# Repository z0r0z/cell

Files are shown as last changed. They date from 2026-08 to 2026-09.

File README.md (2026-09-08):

# CELL

A hardware wallet that needs a live pulse, or a drop of fresh blood, to authorise a transaction.

Airgapped signer for Bitcoin and Ethereum. Raspberry Pi, 3D-printed enclosure, $97.45 of hardware. Public domain.

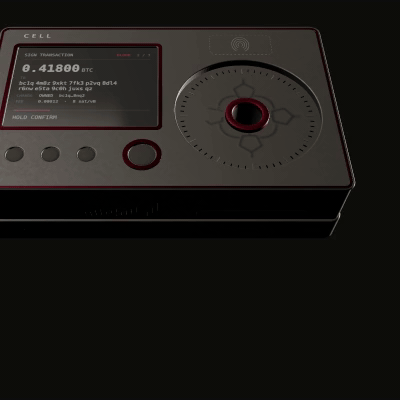
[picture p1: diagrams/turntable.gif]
CELL enclosure, 116 x 73 x 28 mm


<sup>The ring is the sensor port. A fingertip on it, or a cartridge under it. It is a bezel, not a control; nothing rotates.</sup>

## What it is

Transactions arrive as a QR code read by the camera and leave as a QR code on the display, in either of the two framings the airgap ecosystem uses. There is no wifi, no bluetooth and no USB data path.

`BUILD.md` §11 describes an optional USB-C data variant, for a device that signs often from one machine. It costs two properties §16 sets out, and it is not the default.

To authorise a signature you enter an eight-digit PIN and pass one of two liveness proofs.

| | Touch | Blood |
|---|---|---|
| Action | Fingertip on the ring | A drop in a disposable cartridge |
| Duration | 15 seconds | 10 minutes |
| Consumable | None | Cartridge and lancet |
| Proves | A living body is present | A living body bled, just now |

Touch is the everyday default. Blood is a mode you enter deliberately.

A button press costs nothing, so malware, an automated script and a deliberate human decision all produce an identical signal. An act your body rate-limits separates them: one drop of blood is one signature, and no budget compresses that.

How the two liveness tiers gate the signing key

## Status

**Firmware: complete.** 51 suites run on every commit, covering the signing stack against the vectors published in the BIPs, RFC 6979 and the EIPs, both liveness gates, the whole device loop, and the documented build sequence driven end to end. Bitcoin Core funds an address this firmware derives, and accepts and mines the spend it signs.

**Enclosure: complete.** Eleven parts are printed, all generated from the same constants the specification quotes, all mesh-checked and fit-checked before they are written.

**Sensors and secure element: written, not yet run on hardware.** The sensor head, the display, the buttons and the ATECC608B driver are code without a bench behind them. `VALIDATION.md` lists every claim in this repository and how it was checked, including the ones that are still open.

**Thresholds: calibrated on your build.** Sensing thresholds ship as physics-derived defaults. `calibrate.py` runs the spoof panel for both tiers against your own samples and writes the file the device loads. `BUILD.md` §13 is the procedure.

### Someone built one

**[Austin Griffith built a prototype and signed a transaction with fresh blood.](https://x.com/austingriffith/status/2097231722094191031)** Video, September 2026.

<a href="https://x.com/austingriffith/status/2097231722094191031">The blood gate running on the first prototype: laser warm-up, then gates G1 to G4</a>

<sup>A frame from the video: the blood gate mid-run on the prototype's display, showing this design's chemistry sequence in the builder's own wording: G1 return signal, G2 cellular scatter, G3 Soret, G4 shape.</sup>

The first build outside this repository: assembled hardware, a sample in the chamber, and a signature that happened because the blood gate passed. That build did not send back any measurements, so `VALIDATION.md` is unchanged. Everything it lists as needing hardware still needs it.

**There is a [bounty](https://poidh.xyz/mainnet/bounty/24) for building one and signing with it.** `BOUNTY.md` says what a claim looks like. A reader-only build counts.

## Try it without hardware

The gate logic, the signing stack and the whole device loop run on any machine.

```bash
pip install -r firmware/requirements.txt
python firmware/run_tests.py           # all 51 suites
```

Or one piece at a time:

```bash
cd firmware
python calibrate.py selftest --n 8     # blood tier, 6 gates, 18 sample classes
python touch_gate.py                   # touch tier, 7 gates
python test_app.py                     # the whole loop, driven with fakes
python test_wallet.py                  # end to end, then every footgun
```

Each spoof class fails at the physically correct gate, and the self-test fails if any gate stops being exercised by at least one class.

You can also spin the enclosure. It is a parametric three.js model, not a static render, and you can export OBJ or glTF straight from the viewer:

```bash
python3 -m http.server -d viewer 8000     # then open localhost:8000/instrument.html
```

## Building one

Read `SAFETY.md` first. It is short, and it covers blood handling.

The build splits into two kits, bought separately. **Order the reader kit first.** It answers the question that decides whether the rest is worth building, it has no security requirements because it signs nothing, and it costs a third of the total.

### 1. The reader kit: $63 of hardware plus $31 of consumables

A Pi, a spectrometer, a laser, a lensless camera, LEDs, a printed optical chamber, and the lancets, film and cartridges to run them. One weekend.

Build it, then run the spoof panel in `BUILD.md` §13. If the gate does not separate real blood from every fake on your hardware, you stop here and you have spent $94.

### 2. The wallet kit: a further $34.70

The signing half: display, buttons, QR webcam, ATECC608B secure element, USB-C power, the printed shells and the ring window. Then provision a seed and do the airgap hardening: radios disabled, antenna trace cut, read-only rootfs.

### The documents

| | |
|---|---|
| `BUILD.md` | The specification. Parts, wiring, optics, cartridge, firmware, calibration, threat model |
| `BOM.csv` | Every part, with a `Kit` column saying which kit it belongs to and what to insist on |
| `PRINTING.md` | The print runbook: plate order, what to check at each stage, the post-processing that is not optional |
| `SAFETY.md` | Blood handling. Read it before the first build |

Eleven parts are printed, all from `python3 tools/gen_printables.py`, all checked before they are written. `models/print/MANIFEST.md` is generated in the same pass and carries every dimension, quantity and print setting.

**Running costs.** A touch signature costs nothing. A blood signature spends a lancet, an alcohol pad, a PET window and a printed cartridge: about twenty cents, restocked from any pharmacy. Nothing in the device is consumed by either, and nothing on the bill of materials has a shelf life.

## How the gates work

### Blood: six gates, all must pass

**Chemistry.** Haemoglobin absorbs strongly at 415 nm, the Soret band of the iron-bearing porphyrin ring at the centre of the molecule. The absorption is roughly an order of magnitude stronger than anything else in the visible spectrum, and no common red substance produces it. Ketchup, food dye, beet juice and theatrical blood all fail immediately. Three further gates confirm that the sample returns light at all, that it scatters in the near infrared the way a suspension of cells does rather than a dye solution, and that the full eight-channel spectrum matches oxygenated whole blood.

**Motion.** Colour cannot tell fresh blood from a stored sample, so the device measures movement instead. Under laser illumination a liquid suspension of red cells produces a speckle pattern that boils as the cells move; as fibrin forms it locks them in place and the pattern freezes. A camera watches for ten minutes and measures the frame-to-frame correlation.

Fresh blood is the only sample that starts decorrelated and becomes correlated. Anticoagulated blood never arrests. Clotted blood, corn syrup and gels never moved in the first place. Dye produces no speckle at all.

This works because of an asymmetry in how blood can be kept: blood you can store has been anticoagulated and will not clot in the chamber, and blood that was not anticoagulated has already clotted and cannot be poured into a well. `BUILD.md` §16 gives the one exception and how far it reaches.

Implementation in `firmware/blood_gate.py`, with every threshold in a single dataclass.

### Touch: seven gates, all must pass

Photoplethysmography through the same ring bore the cartridge sits under. Arterial blood volume in the fingertip changes with each heartbeat, so the light coming back carries a small pulsatile signal on a large steady one. The white LED gives a red channel and the 940 nm LED gives infrared, both sampled at 50 Hz by the spectrometer that is already there. No extra parts.

The gates check that the capture rate was high enough to analyse, that a finger is in contact, that the signal is pulsatile at a physiological depth, that the rate falls between 40 and 180 bpm, that the cardiac band dominates, that beat-to-beat variability is present, and that the red-to-infrared ratio matches haemoglobin.

The last two carry most of the anti-spoof weight. A silicone finger with dye pumped through it can produce a convincing pulse, but dye does not share haemoglobin's absorption ratio across the two wavelengths; and respiratory sinus arrhythmia puts a resting adult's beat-to-beat variability in the tens of milliseconds, where a mechanical pulsator produces single digits.

Implementation in `firmware/touch_gate.py`.

### Tier policy

You may always escalate to a higher tier than policy requires. You may never proceed at a lower one.

Policy sets a floor, and changing that floor is blood-locked in both directions. Loosening must cost blood, or a thief lowers the bar and uses their own finger. Tightening must cost blood too, or someone locks you out by raising your floor while you are travelling without cartridges.

Escalation applies to one operation and does not persist. Five operations are blood-locked at provisioning and cannot be unlocked: policy changes, key export, device wipe, reprovisioning, and changes to the recipient allowlist.

Implementation in `firmware/policy.py`.

## What else it does

### Attestation

A signature says nothing about what gated the key, so the tier is claimed separately. Each device holds an attestation key generated at provisioning and signs a 238-byte record binding the tier to a specific sighash, a monotonic counter, a firmware hash, the calibration in force and the gate measurements behind the claim.

Co-signers register each other's attestation keys once, alongside the firmware and calibration hashes they accept. Verifying that every member of a quorum signed at blood tier is then a mechanical check, and a missing attestation counts as a failure and never an abstention.

The record travels beside the PSBT in a BIP-174 proprietary field and is stripped before broadcast, so it does not appear on chain. Publishing it says "this address is a CELL device, and this spend was authorised with blood", which is a leak for a treasury, and the whole point for an allowlist, so it is an option and not a default.

A contract can check the record itself. `contracts/src/CellAttestation.sol` verifies the signature; `CellRegistry.sol` holds what the record cannot carry: whose key it is, the highest counter seen from it, and which firmware and calibration you accept. The BIP-340 Schnorr signature has no EVM precompile, so it is rearranged into one `ecrecover` plus a `modexp` to lift the point: about 41k gas to verify, 81k for a full `redeem`. The digest commits to the chain, the contract and the claimant, so a record cannot be replayed on a fork, against another deployment, or by someone else.

What that buys is a signature nobody can farm. A script produces a million; a body produces about two a day, each costing a lancet and ten minutes. Implementation in `firmware/attest.py`.

### One of these devices bled, and you cannot tell which

For an allowlist, a mint or a quorum vote, the claim worth publishing is "a human bled", not "device 7 bled".

`firmware/ring.py` signs as one member of a registered set, using LSAG over the same secp256k1 everything else here signs on. A key image `I = d · H(event ‖ P)` links two claims from one device in one event, so nobody votes twice, and leaves claims in different events unlinkable, so nobody accumulates a voting history.

The firmware and calibration hashes are deliberately left out. They are what makes the ordinary record auditable, and they are exactly what would narrow a ring of forty to a ring of three. The ring replaces them: a verifier admits a set of keys and checked their firmware when it registered them.

A ring of n costs about 2n scalar multiplications on each side, which is slow in pure Python and does not matter, because the ring computes while the sample clots. Use it off chain or in a coordinator-maintained allowlist; it is too expensive to verify on chain.

### Proof of life

Dead-man switches key off signing activity, which answers the wrong question. A stolen key resets the clock, and an owner who simply does not spend for a year looks dead. The touch gate measures a body, so CELL can tell them apart.

A beacon is the attestation with no transaction under it: fifteen seconds, no consumable, nothing signed with the seed. `CellRegistry.heartbeat` records when a living human was last proven present, and an inheritance path, a recovery quorum or a multisig can read it.

**The date on the screen is the security control.** The device has no clock. The period comes from the companion and is displayed as a date range, so the owner is the clock, and `heartbeat` accepts a beacon only while its period is current. A harvested record cannot be spent early or late.

`CellDormancy.sol` reads it in two phases on purpose: a claim releases nothing, it opens a challenge window, and one beacon during that window cancels it. Six months in a drawer is the ordinary case, and fifteen seconds of a fingertip undoes it.

## The signing stack

Both chains sign on secp256k1, so one key and one signing core serve both. The wallet half is implemented here rather than delegated because the gate reaches inside it: the tier decision, the confirmation screen and the attestation all depend on what the transaction actually says. Pure Python, with `cryptography` as the only dependency, used for AES-GCM.

| | |
|---|---|
| `secp256k1.py` | ECDSA with RFC 6979 nonces, low-S, low-R grinding, BIP-340 Schnorr, BIP-341 tweaks |
| `bip39.py` / `bip32.py` | Mnemonic and HD derivation, with the wordlist's SHA-256 checked on load |
| `psbt.py` / `tx.py` | BIP-174 and BIP-370 parsing, and all three sighash algorithms |
| `addresses.py` | bech32 and bech32m, every script type, EIP-55 |
| `eth.py` | RLP and EIP-1559, built on the device from fields it displays |
| `names.py` | WNS, GNS and ENS names the owner registered — routing, per-chain addresses, and the reverse the screen draws |
| `eip712.py` | EIP-712 typed data for smart accounts, the timelock the screen states, and the EIP-7702 delegation |
| `beacon.py` | The beacon digest, and the period the owner reads |
| `qr.py` | The airgap: `pNofM` frames, and reassembly that refuses substitution |
| `ur.py` | UR 2.0 with fountain codes, and EIP-4527, against the published vectors |
| `link.py` | The USB-C data variant's wire. Opt-in, and it costs two properties |
| `app.py` | The loop: scan, show, confirm, PIN, gate, sign, emit |

The device signs a closed set of operations it can render as readable text, and refuses everything else, including arbitrary EVM calldata. Two consequences look like missing features and are not: a PSBT paying several recipients is refused, because the owner can check one destination character by character and cannot check a total; and every Ethereum field (chain id, nonce, and `gas_limit × max_fee_per_gas`) is on the confirmation screen, with unrecognised chain ids refused.

**Handing over your accounts.** The device prints its extended public keys on screen, and will also emit them as one `ur:crypto-account` so a coordinator scans all four Bitcoin script types instead of somebody retyping an xpub. It signs nothing and needs no PIN. It sits behind a warning, because an account xpub reveals every address that wallet will ever use, forever, to whoever reads it.

**Both QR framings, and a browser.** Transfers arrive and leave as either `pNofM` frames (the Specter convention) or UR 2.0 (what Sparrow and the Keystone-compatible coordinators reach for), and the device replies in whichever it was asked in. UR is rateless, so a frame the camera never manages to read is recovered from a mixture of others instead of stalling the transfer — which matters on a $8 webcam. UR also carries EIP-4527, so MetaMask's and Rabby's QR-account flows work: the request arrives as `ur:eth-sign-request` and the answer goes back as `ur:eth-signature`. There the transaction arrives encoded rather than as fields, so the device rebuilds it, re-encodes it, and refuses if the two differ by a byte.

One operation carries calldata, and the way it does is the point. An **ERC-20 transfer** is signed for tokens the owner registered, and the device is never handed those 68 bytes — it is handed a token, a recipient and an amount, and it writes `transfer(address,uint256)` itself. Both addresses go on the screen in full, because an ERC-20 transfer is addressed to the *contract* and carries the *recipient* in its calldata, and one address on a screen is the wrong one. `decimals` comes from the registration and never from the request: it is where the decimal point goes, and a request that could supply it could render a millionth of a token as one whole token. `approve` is not implemented, and neither is any other selector.

**Names, on both chains.** A payee's `.wei`, `.gwei` or `.eth` name can sit above their address on the confirmation screen — WNS first, then GNS, then ENS, since this project co-developed WNS. The device never resolves one: it has no network, and a name that arrived with a transaction would be a label an attacker picked for an address you are about to approve. So names are registered like chains, tokens and quorums are — `tools/ethnames.py` resolves and forward-verifies on the host, you check the address against the name's own page, and `provision.py name` records the pair. The address stays on the screen in full, and it is still what the signature commits to.

All three systems are rooted on Ethereum mainnet and read through the same SLIP-44 coin types, so one name covers more than one chain: its default address is drawn on every EVM chain, a per-chain address (ENSIP-11) overrides it on the chain that published one, and a Bitcoin address (coin type 0) makes the same name a payee on a Bitcoin spend. Where a name publishes an override, the device refuses to draw that name over the default address on that chain — the same twenty bytes on two chains can be two different owners.

One exception earns its place. A smart account's timelock is not in the signed message, so the same signature means "send now" or "send in two days" depending on chain state the device cannot read — the delay is registered out of band and stated on the screen, along with whether every owner signing together can skip it. And `cancelQueued` is the one self-call the device will sign, at touch tier, because a device that can start a delay but not stop one has given its owner a countdown and no button.

Multisig and smart accounts must be registered before they can be signed, and this device has to be a member of what it registers — a Bitcoin quorum it holds no key in, or an EVM account it is not an owner of, is refused rather than signed for and rejected afterwards. Without the co-signers on file, "is this output mine?" collapses to "does it contain a key of mine?", and a hostile coordinator can build a script holding one key of yours and the rest theirs; it hashes correctly, the wallet calls it change, and the money moves somewhere you cannot spend alone. With the quorum registered the device rebuilds the exact script your co-signers produce and compares it byte for byte. `tools/provision.py multisig` does the registering.

## Keys and backup

The device holds a standard BIP39 seed, encrypted at rest and unwrapped only after the gate passes. The unwrapping key comes from your PIN and the secure element's own secret, so the encrypted seed is inert on any other machine and recoverable on this one. Back it up on paper or steel as with any hardware wallet. If the device fails, restore to a Ledger, a Trezor or a replacement build.

The seed itself is drawn from three sources XORed together: the kernel CSPRNG, the ATECC608B's hardware RNG, and the difference between disjoint pairs of speckle frames from the chamber, where the static field cancels and photon shot noise does not. `provision.py` prints the min-entropy it measured on the sample it actually drew. A chamber that is dark, blocked or absent contributes zeros and says so, and zeros XOR into nothing.

## Limits

Worth reading before you trust it with anything. `BUILD.md` §16 carries the full threat model.

**The PIN is what proves who.** The gate only proves that someone alive is present. The PIN is eight digits. PIN-v2 derives each candidate through a random secret in the secure element, consuming a chip-counter use before comparison. A public PIN hash no longer suffices for raw verification commands. Firmware wipes after ten wrong entries; the separate hardware bound is the remaining Counter0 capacity, at most 2,097,151 uses shared with wrapping operations. The new provisioning policy rejects the old configuration. Physical validation remains required before release; see `VALIDATION.md`.

**The attestation rests on firmware and the tamper seal.** It states that a device holding this key ran the gate; it does not prove the gate passed. This is the same assumption as a TPM quote or a Secure Enclave receipt. Someone who opens the case and extracts the key can sign records without bleeding, so treat it as raising the cost of faking a human. Co-signers register firmware hashes alongside keys, and `verify()` refuses builds it does not recognise.

**An opened case derives a different key.** A ground-glass diffuser is epoxied into the optical chamber, and the laser and camera that watch blood clot read its speckle at every unlock. That reading is a term in the key that unwraps the seed, so a case that has been opened does not fail a check. It derives a different key, and the seed stays shut. Thermal drift is registered out against two reference patches and reported separately from tampering. Enrolment is optional. It costs one habit: because the laser is interlocked to the cartridge switch in hardware, an enrolled device needs the bay closed at every unlock, so leave a spent cartridge in the slot. `firmware/optical_puf.py`.

**Coercion needs a second PIN.** No measurement tells willing blood from coerced blood. Set a duress PIN and the device carries two wrapped seeds and two wallets; the duress PIN unlocks, signs and behaves identically, and opens the other one. Both seeds are written whether or not you configure one, so the card never says which kind of device this is. It protects what you sign, not what your device shows: the receive and identity screens are watch-only and still display the primary wallet. Fund the decoy plausibly. `firmware/duress.py`.

**A prepared laboratory attack is not in scope.** A well-made artificial finger containing a genuine haemoglobin-like absorber, driven by a pump replaying recorded variability, would pass the touch tier. So would a citrated sample recalcified immediately before loading, at the blood tier. Both need your blood, your device and your PIN together.

**Anyone taking anticoagulants cannot use the blood tier.** Their blood will not clot, and the gate will reject every sample.

## Repository layout

| Path | Contents |
|---|---|
| `BUILD.md` | Hardware specification: parts, wiring, optics, cartridge, firmware, calibration |
| `PRINTING.md` | Print runbook: order, checks, post-processing |
| `BOM.csv` | Bill of materials, by kit, with sourcing notes |
| `SAFETY.md` | Blood-contact handling. Read it first |
| `VALIDATION.md` | Verification status: what is tested, by what method |
| `CONTRIBUTING.md` | What this project actually needs |
| `firmware/blood_gate.py` | Blood tier, six gates |
| `firmware/touch_gate.py` | Touch tier, seven gates |
| `firmware/calibrate.py` | Spoof-panel harness for both tiers, and the synthetic self-test |
| `firmware/hardware.py` | Sensor drivers, and a bring-up checklist |
| `firmware/policy.py` | Tier selection and escalation rules |
| `firmware/signer.py` | The unlock chain: policy, confirm, PIN, gate, sign, attest |
| `firmware/attest.py` | Tier attestation and quorum verification |
| `firmware/ring.py` | The attestation with the device's name taken off it |
| `firmware/beacon.py` | Proof of life: the attestation with no transaction under it |
| `firmware/duress.py` | The second PIN |
| `firmware/optical_puf.py` | The chamber as a tamper boundary |
| `firmware/chamber_trng.py` | Seed entropy from the chamber, and its health tests |
| `firmware/se_atecc.py` | ATECC608B driver: CheckMac PIN, duress slots |
| `firmware/wallet.py` | Provisioning, and the two signing entry points |
| `firmware/app.py` | The loop, as a person uses it |
| `firmware/ur.py` | UR 2.0 framing, against the published vectors |
| `firmware/link.py` | The optional USB-C wire, and what choosing it costs |
| `firmware/names.py` | WNS, GNS and ENS names the owner registered, and what the screen may draw |
| `firmware/names.py` | WNS, GNS and ENS names the owner registered, and what the screen may draw |
| `firmware/run_tests.py` | Every self-test in one run. What CI runs |
| `tools/provision.py` | Choose a seed, wrap it, record the watch-only accounts |
| `tools/companion.py` | The host end of the USB-C variant's wire |
| `tools/ethnames.py` | Resolves WNS, GNS and ENS on the machine that has a network |
| `tools/ethnames.py` | Resolves WNS, GNS and ENS on the machine that has a network |
| `tools/gen_printables.py` | Generates every printable part, checks it, writes the manifest |
| `tools/gen_enclosure.py` | The inside of the two shells, and the fit checks |
| `tools/bench.py` | The checks only the built device can answer |
| `tools/regtest_e2e.py` | Sign with the firmware, make Bitcoin Core accept it |
| `tools/evm_e2e.py` | Deploy the contracts, make a node accept a beacon the firmware signed |
| `contracts/` | On-chain verification of the attestation record, and the registry |
| `models/print/` | The eleven printable STLs and their generated manifest |
| `viewer/` | Parametric three.js model of the enclosure |
| `diagrams/` | Explainer, build sheet, dimensioned drawings |

Build sheet: parts, optical head, cartridge

## Licence

CC0 1.0. See `LICENSE`.

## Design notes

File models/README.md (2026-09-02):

# Enclosure model

`instrument.obj`: 104 named objects with materials, 116.2 × 73.2 × 28.3 mm.
~54 MB, tracked with Git LFS (see `.gitattributes`).

The object and vertex counts are printed in the corner of
`diagrams/mechanical.svg`, which is generated from this file. Trust that copy
if this line ever drifts again.

## The chain is one-way

```
viewer/model.js  ──export──▶  instrument.obj  ──generate──▶  diagrams/mechanical.svg
```

`viewer/model.js` is the **parametric source**. It builds the geometry in
three.js. `instrument.obj` is an export from that viewer. The drawing is
generated from the export by `tools/gen_mechanical.py`, which reads every
dimension out of the mesh at generation time, so the drawing cannot drift from
the model. CI fails if it does.

After any model change, re-export and then:

```bash
python tools/gen_mechanical.py
```

**Do not hand-edit the OBJ.** It is 54 MB of triangles, and nothing downstream
of a hand edit can be reconciled with a parametric change.

`instrument.mtl` is written by `tools/export_model.py` in the same pass as the
OBJ, from the viewer's own materials, so the two stay in step. Material names
also ride on the objects themselves (`shell`, `oxblood`, `trim_oxblood`,
`glass`, `pad`, `etch_floor`, `steel`, `cavity`, `cavity_bore`, `screen`,
`silkscreen`, `silkscreen_mark`), so the separation survives if you drop the
MTL and assign your own. Twelve, not eleven: `cavity_bore` is the inward-facing
material on `port_sleeve`, and it is the one the OBJ cannot carry faithfully,
because a back-faced material is a thing the format has no way to say.

The two accent materials, `oxblood` and `trim_oxblood`, are the only ones a
builder is meant to choose. `model.js`'s `FINISHES` table names five, and
`PRINTING.md` section 2b carries the same set as filament colours. Oxblood is
the default, and the export is byte-identical in every finish that does not
change it: the OBJ carries no colour at all, and the MTL is written from
whichever finish is loaded, which for every committed artefact is the default.
Nothing here needs regenerating when a finish is added.

## Coordinate convention: centre-origin

| Axis | Range | Meaning |
|---|---|---|
| X | −58.10 … +58.10 | length, right positive |
| Y | 0 … 28.32 | height from the base |
| Z | −36.60 … +36.60 | depth, **+Z toward the front face** |

Some tooling works left-edge-origin (0 … 116.2). Crossing the two frames is a
silent 58 mm error that will not look wrong on screen.

---

## The printed parts

`models/print/` holds the parts that are *not* enclosure: the cartridge, the
pre-flight REFERENCE and NULL bodies, the aperture tube, the optical head, the
slot baffle, the display bezel, the rear bay blank, the window jig, and both
enclosure shells.
`python3 tools/gen_printables.py` builds all eleven, validates each one, and
regenerates `models/print/MANIFEST.md` from the same constants. The manifest
cannot describe a part the STLs no longer are.

The shells are the one place the one-way chain above does not tell the whole
story. `model.js` owns the outside and is an appearance model: its shells are
solid, and its openings are dark boxes with no volume removed. The inside
(wall, part line, bosses, rails, optical chamber) comes from
`tools/gen_enclosure.py`. Two parametric sources is exactly the drift this file
warns about, so the seam is checked on every run: the assembled shells must
match the documented envelope, and the assembly checks must pass. See
`models/print/MANIFEST.md`.

## Regenerating

`tools/export_model.py` drives headless Chrome against the real viewer, so the
mesh comes out of the same three.js code path a person gets when they open the
page. No reimplementation to drift.

```bash
python tools/export_model.py        # model.js  -> instrument.obj + .mtl
python tools/gen_mechanical.py      # instrument.obj -> diagrams/mechanical.svg
```

Run both after any model change, in the same commit. CI checks both links: the
`model-export` job re-exports and diffs the OBJ, and `drawings` regenerates the
SVG from it.

Three more things are rendered from this same model and are stale the moment it
changes. None is checked by CI, because each needs a browser:

```bash
python3 tools/render_turntable.py       # -> diagrams/turntable.gif + .mp4
python3 tools/render_social_card.py     # -> diagrams/social-card.png
python3 tools/build_single_file_viewer.py   # -> viewer/instrument-standalone.html
```

The last one is what `cell.wei.is` serves, so it is the one that matters
outside the repository. Building it is not deploying it. CI's `viewer` job
checks the bundle in the tree carries this tree's viewer. Nothing can check
what the host is serving.

## Geometry check

The cartridge enters the front slot and must land under the optical head, so
the slot and the ring share a centreline:

| | X centre | Z |
|---|---|---|
| `front_slot` | +28.50 (spans +11.5 … +45.5) | +36.05 |
| `ring` / read spot | +28.50 | +5.00 |
| Front face | — | +36.60 |

Cartridge travel front face to read spot is **31.6 mm**, which sets the 51 mm
cartridge length in `BUILD.md` §8. The WELL has to reach the read spot and sits
10.5 mm back from the tip, so 42.1 mm goes in and 8.9 mm stands proud to grip.
If you move the dish, re-derive the cartridge length from this number.

## The sensor port

The dish floor is an annulus. `PORT_D` 9.8 opens through it to the optical
chamber, and the Ø10 × 0.5 ring window that `BOM.csv` buys sits in a
Ø10.2 × 0.6 rebate under the ring's inner lip, flush with the floor. Four
objects carry it: `recess_floor_etch` (the annulus), `ring_window`,
`port_sleeve` and `port_floor`. The numbers come from `tools/gen_enclosure.py`,
which owns the inside. This file's job is only to look like it.

## The deck's top face is 28.32

Not 28.0. `shell_skin` extrudes 27.5 → 28.0 with a 0.4 bevel, which is thicker
than half the slab, so `ExtrudeGeometry` clamps the depth and the chamfer adds
its full thickness on top. The deck finishes at 28.32. That is where the
envelope's 28.32 comes from, and what `gen_enclosure.py` pins `ENV_Z` to.

Anything that sits ON the deck has to be placed against 28.32. Four things were
placed against 28.0 instead and spent a long time invisible inside the shell:
the pad marking, the display bezel, the CONFIRM collar and the edge break. They
are coplanar with the deck now, and depth-offset instead of floated, because
lifting them even a hundredth would raise the envelope that
`gen_enclosure.check_viewer_envelope()` compares against the printed shells.

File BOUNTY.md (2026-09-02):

# Bounty: build one and sign with it

Everything you need to build one is in this repo.

**Build the device. Sign with a pulse. Sign with fresh blood. Post pictures.**

**[Bounty 24 on poidh](https://poidh.xyz/mainnet/bounty/24)**, on mainnet. It
is topped up over time, so the listing carries the amount and this file
deliberately does not.

## Cost

**~$97 in hardware, ~$31 in consumables.** `BOM.csv` lists every part with
sourcing. The bounty is worth more than the build.

## Build it

`BUILD.md` §15, milestones 1 to 14. Wiring in `diagrams/wiring.svg`, optical
head in `diagrams/build-sheet.svg`, printables in `models/print/`.

Milestone 14 is the restore drill: wipe the device, restore from your paper
backup, spend again. Do it before you claim.

## Before you start

Read `SAFETY.md`. One device per person, one lancet per use, sharps container.

The gate wants a fresh sample from anybody. Anyone on anticoagulants will be
rejected every time, since clotting is the thing being measured.

Two things to know:

- `firmware/hardware.py` has never touched hardware. Treat it as a wiring
  diagram in Python. It has a bring-up checklist.
- Locking the chip is permanent. `lock-data` refuses a chip that fails its own
  policy or does not enforce it, so the tool covers you. Run
  `atecc_config.py verify --behaviour` first and read it anyway.

## Claim it

Submit the claim on [the bounty page](https://poidh.xyz/mainnet/bounty/24),
with pictures or video of:

1. The assembled device, running
2. A signature authorised by a pulse
3. A signature authorised by a fresh blood sample
4. The transaction on chain. Testnet is fine

And say what you had to change to make it work, if anything.

## Partial claims count

**Reader only.** Milestone 7, a spoof panel run, `thresholds.json` and
`captures/` posted. That is the half carrying the novel physics, and the
cheaper one to reach at $62. Open an issue here with the numbers as well as
claiming on poidh: `CONTRIBUTING.md` says what makes a panel run useful to
everybody else, and the captures are `.npz` so they can be replayed safely.

**A failure is a claim too.** If dye passes a gate, or real blood fails on your
optics, post it. That answer is worth paying for.

`VALIDATION.md` tracks what has been verified and what is waiting on a first
build. You're the one who moves rows from the second list to the first.

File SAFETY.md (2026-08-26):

# Safety

CELL is a blood-contact instrument. The handling rules are the ones any
phlebotomy or home-glucose workflow uses. Followed, the risk is that of a
finger-prick glucose test, a routine procedure performed billions of times a
year.

Read this before your first build.

---

## Who the blood tier is for

The blood tier works by measuring clotting. If your blood does not clot on a
normal schedule the gate rejects you every time. That is an incompatibility,
not a safety warning.

**Use the touch tier if you:**

- take anticoagulants: warfarin, DOACs (apixaban, rivaroxaban), clopidogrel,
  or daily aspirin
- have a bleeding or clotting disorder
- are immunocompromised
- have poor peripheral circulation

The touch tier is the everyday default, needs no consumable, and defeats the
same remote-attacker class. Nothing about the device is closed to you.

## The five rules

1. **One device, one person.** Blood-contact equipment is personal, the way a
   lancing device or a toothbrush is. Do not share it and do not lend it.

2. **Commercial sterile single-use lancets.** Contact-activated, 28G / 1.8 mm,
   about $0.06 each from any pharmacy. One lancet, one use. They retract and
   lock, which is what you are paying for.

3. **One cartridge, one use, then the sharps container.** A 1 L container is on
   the BOM. Used cartridges and lancets go in it, never in household waste.

4. **Alcohol before, pressure and a plaster after.** Rotate fingers. Use the
   sides of the pad: less nerve density, and not the surface you type with.

5. **Two blood authorisations a day is the design point.** The blood tier is
   for cold storage and infrequent high-value operations. The touch tier
   handles everything else. Wanting more means your policy floor is set too
   aggressively, which is a settings change.

## During calibration

Calibration wants 30+ genuine captures, and 100 for a tighter bound. Spread
them out:

- Draw once, venously, to supply the negative classes (aged, EDTA, haemolysed,
  deoxygenated). Do not lance repeatedly for them
- Spread genuine capillary trials across several weeks
- Rotate fingers and sites

It is also better data. Samples taken across weeks, hydration states and
temperatures give thresholds that hold up in real use.

## Standard aftercare

Puncture sites heal in a day or two. See a doctor for spreading redness,
warmth, swelling, pus, red streaking up the finger, fever, or bleeding that
will not stop after 10 minutes of direct pressure. That is the guidance that
comes with any lancing device.

## Laser

650 nm diode at ≤5 mW. Class 3R, the same class as a lecture pointer. It is
interlocked to the cartridge switch and sealed inside a light-tight chamber in
normal operation.

The chamber is open during bring-up. Do not stare into the beam. Do not point
it at anyone. Take off reflective jewellery while you work.

## Scope

CELL is a security device. It is not a medical one. It measures clotting to
prove a sample is fresh, and it reports gate results. It says nothing about
your health. A rejection means the sample or the optics, and the usual cause
is a fingerprint on the window.

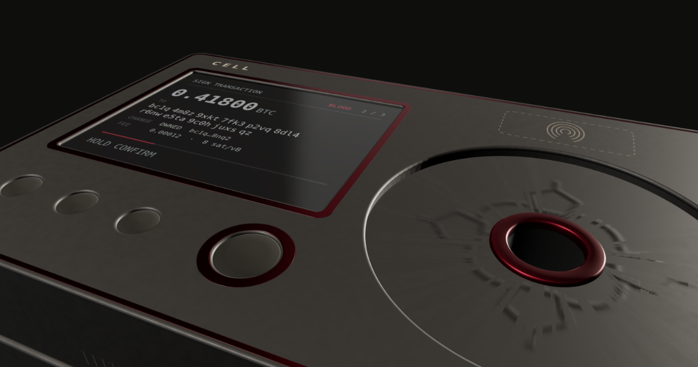
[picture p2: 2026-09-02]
diagrams/social-card.png

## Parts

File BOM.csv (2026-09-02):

Kit | Category | Item | Part / Spec | Qty | Unit USD | Ext USD | Notes
Reader | Compute | Single board computer | Raspberry Pi Zero 2 W | 1 | 15.00 | 15.00 | Disable radios in config.txt AND cut the antenna feed trace. Firmware-only disabling is reversible.
Wallet | Security | Gate chip | ATECC608B breakout (Adafruit 4314 / SparkFun) | 1 | 6.00 | 6.00 | PIN attempt counter + AES key storage + KDF. Counter increments before verify.
Reader | Sensing | Spectrometer | AMS AS7341 breakout (Adafruit 4698) | 1 | 16.00 | 16.00 | 8 colour channels 415-680nm + Clear + NIR. Onboard LDR pin drives LED #1 directly.
Wallet | I/O | Display | ST7789 1.3in 240x240 SPI | 1 | 8.00 | 8.00 | SPI0 CE0
Reader | I/O | Camera (speckle) | Pi Camera + mini-CSI cable | 1 | 10.00 | 10.00 | LENS REMOVED. Fixed exposure/gain/AWB - auto adjustment destroys the correlation measurement.
Wallet | I/O | Buttons | 12mm tactile switch + cap | 4 | 0.75 | 3.00 | CONFIRM gets its own pin (GPIO26) + RC debounce 10k/100nF
Reader | Optics | White LED | 5mm white 5000K | 2 | 0.40 | 0.80 | Mounted at 45 deg opposed
Reader | Optics | IR LED | 940nm 5mm | 1 | 0.50 | 0.50 | Co-sited with LED #1
Reader | Sensing | Laser | 650nm diode module, <=5mW | 1 | 2.00 | 2.00 | Liveness gate. Coherent source is MANDATORY - an LED has microns of coherence length and produces no speckle. Interlock to the cartridge switch.
Reader | Optics | MOSFET | 2N7002 SOT-23 | 3 | 0.15 | 0.45 | Low-side gates for white LED #2 (GPIO12, 68R to +5V), 940nm IR (GPIO23, 47R to +3V3) and the laser (GPIO6). Three loads, three parts.
Reader | Optics | Passives | 68R / 47R / 10k / 5.1k / 2.2k / 100nF assortment | 1 | 1.00 | 1.00 | ONE 2.2k pull-up pair on the whole I2C bus - remove from the other breakouts. The two 5.1k are the USB-C CC pulldowns - see the USB-C row.
Wallet | Power | USB-C power input | USB-C breakout, power only | 1 | 2.00 | 2.00 | NO BATTERY. A LiPo left at partial charge for a year swells or worse. Desolder D+/D- or use a data blocker. CHECK THE BREAKOUT HAS 5.1k CC1/CC2 PULLDOWNS - without them a compliant charger supplies nothing. Feed the Pi 5V/GND pads; needs 5V at 2A.
Reader | Sensing | Cartridge switch | SPDT snap-action microswitch with lever | 1 | 0.50 | 0.50 | GPIO22 cartridge-present. Also the laser interlock: the laser gate runs through its contacts, so an open chamber cannot be illuminated even if the firmware asks.
Reader | Compute | Prototyping | Small breadboard + jumper wires | 1 | 5.00 | 5.00 | No PCB needed to prove the sensing.
Reader | Storage | microSD | 16GB A2 | 1 | 6.00 | 6.00 | Read-only rootfs via overlayfs
Reader | Enclosure | Filament black | PETG black ~90g | 1 | 2.00 | 2.00 | Optical chamber. NOT PLA - creeps under screw preload.
Reader | Enclosure | Filament white | PETG white ~60g | 1 | 3.00 | 3.00 | Cartridges, ~2.4 g each. 20 for the build order's batch check, plus the REFERENCE and NULL pair. Ironing ON - the white patch is a photometric reference.
Wallet | Enclosure | Fasteners | M2.5x16 screw + M2.5 heat-set insert, 3.5mm knurled OD | 6 | 0.30 | 1.80 | Six insert bosses. Screws enter from the base into inserts in the upper shell; the two front-face pockets are blind and cosmetic
Wallet | Enclosure | Display fasteners | M2x6 self-tapping screw | 4 | 0.10 | 0.40 | Into the Ø1.8 pilots in the four display posts. Module hangs below the deck; display_bezel.stl masks the window down to the active area
Wallet | Optics | Ring window | 10mm dia x 0.5mm clear acrylic or glass disc | 1 | 1.00 | 1.00 | Seals the optical chamber and gives touch mode a defined contact surface. No AR coating needed - specular exits at 45 deg.
Reader consumable | Consumable | Safety lancets | Contact-activated sterile 28G / 1.8mm | 100 | 0.06 | 6.00 | COMMERCIAL ONLY. Never fabricate or reuse. Any pharmacy.
Reader consumable | Consumable | Alcohol prep pads | 70% IPA individually wrapped | 100 | 0.02 | 2.00
Reader consumable | Consumable | PET window film | 0.10mm laser transparency or laminate pouch | 100 | 0.08 | 8.00 | ~1600 windows per 100 sheets
Reader consumable | Consumable | Adhesive | 3M 300LSE double-sided 0.05mm | 1 | 9.00 | 9.00 | Window attachment
Reader consumable | Consumable | Sharps container | 1 litre | 1 | 6.00 | 6.00 | MANDATORY. Used cartridges and lancets are biohazard, not household trash.
Wallet | Enclosure | Test cartridges | REFERENCE + NULL, printed once and sealed | 2 | 0.00 | 0.00 | Pre-flight drift check. REFERENCE must pass spectral gates and fail Gate 5 (it cannot move). NULL must fail Gate 1 on the bright side.
Wallet | I/O | Camera (QR) | Cheap USB webcam | 1 | 8.00 | 8.00 | The Pi Zero has one CSI port and speckle has it. QR decoding tolerates auto-exposure.
Wallet | I/O | USB OTG adapter | micro-USB male to USB-A female | 1 | 2.00 | 2.00 | The Pi Zero's ports are micro-USB. Without this the QR webcam physically cannot be plugged in.
Wallet | Security | Chamber diffuser | Ø6 mm ground glass or holographic diffuser, 220 grit or finer | 1 | 1.50 | 1.50 | Epoxied into the chamber wall, clear of the cartridge optical window. Its speckle is the tamper boundary — see firmware/optical_puf.py. Any rough transmissive disc works; what matters is that it never moves again
Wallet | Security | Chamber epoxy | Two-part epoxy, 5 minute, opaque black | 1 | 1.00 | 1.00 | Bonds the diffuser and fills the void behind it. Opaque so the chamber stays light-tight. Do NOT use hot glue — it creeps with temperature and the speckle drifts with it

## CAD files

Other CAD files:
models/instrument.obj
models/print/shell_lower.stl
models/print/shell_upper.stl
models/print/cartridge.stl
models/print/cartridge_reference.stl
models/print/cartridge_null.stl
models/print/slot_baffle.stl
models/print/optical_head.stl
models/print/display_bezel.stl
models/print/aperture_tube.stl
models/print/bay_blank.stl
models/print/window_jig.stl

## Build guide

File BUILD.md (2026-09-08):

# CELL Build Specification

Single device, $97.45 in hardware plus $31.00 of consumables, Raspberry Pi Zero 2 W, 3D-printed shell over the Pi.

The enclosure comes from `viewer/model.js`, a parametric three.js model. `models/instrument.obj` is its export, 104 named objects with materials, 116.2 × 73.2 × 28.3 mm, and `diagrams/mechanical.svg` is generated from that by `tools/gen_mechanical.py`, so the drawing cannot drift from the model. See §10.

Sensing thresholds ship as physics-derived defaults and are calibrated to your hardware in §13, the step any instrument needs before it is trusted. `VALIDATION.md` is the engineering status record. Use testnet until you have run the calibration.

## Where to start

Read §1 and §2, order the reader kit, then work through §15's build order. The rest of this document is reference: come back to a section when the build order sends you there.

| | Sections |
|---|---|
| **What it is and what it costs** | §1 what you're building · §2 the two kits · §6 parts, and what to insist on when buying |
| **How it decides** | §3 sensing architecture · §4 the two tiers and the policy between them · §7 the six blood gates |
| **What to make** | §8 the cartridge · §9 optical head · §10 enclosure · §11 wiring |
| **What to install** | §12 firmware, from a blank SD card to a running device |
| **What to do once** | §13 calibration · §15 build order, milestone by milestone |
| **Before you trust it** | §5 deployment model and pre-flight · §14 safety · §16 threat model and design limits |

`PRINTING.md` is the print runbook and `BOM.csv` is the shopping list. Both are driven by the same constants as this document.

---

## 1. What you're building

An airgapped hardware wallet, 116 × 73 × 28 mm. Transactions enter and leave as QR codes, in either of the two framings the ecosystem uses; there is no wifi, bluetooth or USB data path. Signing requires a PIN and one of two liveness proofs. §11 has an optional USB-C data variant, and §16 says what it costs.

```
   operation ──(QR)──▶  camera ─▶ parse ─▶ render as readable text ─▶ confirm
                                                  │
                                    PIN  +  PULSE or BLOOD
                                                  │
                        seed decrypted in RAM ─▶ sign ─▶ zeroise
                                                  │
   authorisation ◀──(QR)─────────────────────────┘
                    companion submits it and pays the fee
```

Four elements, kept separate:

| Element | Mechanism | Establishes |
|---|---|---|
| Touch tier | 7-gate photoplethysmography, 15 s | A living body is present |
| Blood tier | 6-gate optical and speckle liveness, 10 min | A living body bled, just now |
| PIN | ATECC608B with a monotonic attempt counter | Identity |
| Seed | BIP39, AES-256-GCM at rest, key held by the ATECC608B | The signing secret |

The seed is backed up on paper or steel as with any conventional hardware wallet.

---

## 2. Two kits, ordered separately

The blood reader is the novel component. The wallet layer is a solved problem that can be forked from an existing project, so you build and buy them as two separate kits.

**"Phase" here means a shopping list, not a schedule.** Every row in `BOM.csv` carries a `Kit` column that says which one it belongs to:

| Kit | What it is | Cost |
|---|---|---|
| `Reader` | The blood reader hardware, Pi, spectrometer, laser, camera, LEDs, filament | $62.75 |
| `Reader consumable` | Lancets, alcohol pads, PET window film, tape, sharps container. Needed to run the reader at all. About 100 blood readings, limited by the lancet and pad counts | $31.00 |
| `Wallet` | The signing half, secure element, display, buttons, QR camera, ring window, fasteners | $34.70 |

Order the reader kit and its consumables together; they are one purchase and the reader is useless without both. The wallet kit is a second purchase you only make if the reader works.

### Kit 1. The blood reader ($62.75 hardware + $31.00 consumables, one weekend)

| Item | ~USD |
|---|---|
| Raspberry Pi Zero 2 W | 15 |
| AS7341 spectrometer breakout | 16 |
| 2 × white LED, 1 × 940 nm IR LED | 1.30 |
| 650 nm laser diode module | 2.00 |
| Pi Camera + mini-CSI cable | 10.00 |
| 3 × 2N7002 + resistors | 1.45 |
| Cartridge-present microswitch, DPDT | 1.00 |
| 16 GB microSD | 6 |
| Jumper wires, small breadboard | 5 |
| PETG white + black, ~90 g black + 60 g white | 5.00 |

Plus the reader consumables ($31.00): 100 sterile lancets, 100 alcohol pads, PET window film, 3M 300LSE tape, and a 1 litre sharps container. Every one of them is needed to run the spoof panel in §13, so budget them with the hardware. That is a starter pack, not a device lifetime: the lancets and pads run out first at 100 each, while 100 sheets of film cut about 1,600 windows. Restock the lancets from any pharmacy.

The reader has no security requirements, because nothing is being signed. Leave wifi enabled, work over SSH, print results to the console. No display, secure element, enclosure or airgap is needed. The only printed parts are a light-tight optical chamber and a plate of cartridges.

It answers the question that determines whether the rest is worth building: does the gate separate real blood from every fake? Run the spoof panel in §13. If it does not, you never order the wallet kit.

### Kit 2, the wallet (+$34.70)

| Item | ~USD |
|---|---|
| ST7789 1.3" 240×240 SPI display | 8 |
| USB webcam, for QR ingest | 8 |
| micro-USB OTG adapter, for that webcam | 2 |
| ATECC608B breakout | 6 |
| 3 × 6 mm tactile + 1 × 12 mm tactile (CONFIRM) | 3 |
| USB-C breakout, power only | 2 |
| M2.5 screws + heat-set inserts, M2 display screws | 2.20 |
| Ø6 mm ground-glass diffuser + 5-minute epoxy | 2.50 |
| Ø10 × 0.5 mm ring window, clear acrylic or glass | 1.00 |

The signing firmware is in this repository, see §12. Build it, provision a seed, then do the airgap hardening: radios disabled, antenna trace cut, read-only rootfs.

**Full device: $97.45 of hardware,** plus $31.00 of consumables. $128.45 all in.

**What a signature costs.** A touch-tier signature costs nothing, no
cartridge, no lancet, and touch is the everyday default. A blood-tier
signature spends one lancet ($0.06), one alcohol pad ($0.02), one PET window
(~$0.005) and one printed cartridge (~2.4 g of PETG, ~$0.12): call it **twenty
cents**. The device is not consumed by either, and nothing here has a shelf
life, there are no reagents, which is why §5 chose native clotting over dried
accelerants.

The hardware is not consumed. The $31.00 covers about 100 blood-tier readings. The lancets and alcohol pads run out first at 100 each, while 100 sheets of film cut roughly 1,600 cartridge windows. Touch-tier signatures cost nothing, and cartridges are printed filament rather than a purchase.

---

## 3. Sensing architecture

| | Sensor | Asks |
|---|---|---|
| **Chemistry** | AS7341 spectrometer + 3 LEDs | Is it blood? |
| **Liveness** | 650 nm laser + camera, speckle | Is it alive? |

The split matters because the two questions have different physics and one sensor is bad at both.

**Chemistry.** Haemoglobin's Soret band at 415 nm is roughly an order of magnitude stronger than anything else in the visible spectrum, and nothing in a kitchen has one. Four gates off one $16 part.

**Liveness is not a reflectance measurement.** What changes during clotting is the *motion* of the scatterers, red cells go from free Brownian motion to being locked in a fibrin network. Bulk reflectance barely registers that. Coherent light does: a speckle pattern from a liquid suspension boils, and a speckle pattern from a clot is frozen. This is why every established low-cost optical coagulometer uses a laser and a camera rather than a photodiode.

The measurement is **frame-to-frame speckle decorrelation**:

```
D = 1 − (correlation between consecutive frames)

    liquid blood   D ≈ 1.0    speckle fully decorrelates between frames
    clotted blood  D ≈ 0.0    pattern is static
```

The signal is close to binary. This is why the liveness gate measures motion rather than reflectance.

### The liveness test assumes no curve shape

Published coagulation indices disagree about whether clotting is exponential, sigmoid, or something else. The test does not need to know. It asks three things:

The frames are spatially high-passed before they are correlated. Real lensless speckle rides on a strongly non-uniform beam envelope which is *identical* frame to frame, and correlating raw frames measures the envelope instead of the speckle, enough to hold the correlation above 0.5 while the speckle is fully boiling, which fails Gate 5 on genuine blood. Each frame is high-passed independently; subtracting a temporal mean instead would invert the gate, because a frozen field minus its own mean is pure noise and decorrelates perfectly.

1. **Did it start moving freely?** `D(early) ≥ 0.60`
2. **Did it stop?** `D(late) ≤ 0.25`
3. **Was the transition real and in the right direction?** drop `≥ 0.35`, Spearman ρ `≤ −0.70`

This restates the security argument in measurable terms:

> Fresh blood is the only sample that starts decorrelated and becomes correlated. Anticoagulated blood never stops moving. Already-clotted blood, syrup and gels never started. Dye has no speckle at all.

---

## 4. Two tiers

| | **Touch** | **Blood** |
|---|---|---|
| Proves | A living body **is** here | A living body **bled** here |
| Action | Fingertip on the ring | A drop in a cartridge |
| Time | 15 s | 10 min |
| Consumable | None | Cartridge + lancet |
| Added parts | **Zero**, it reuses the spectrometer | The laser and the camera |
| Defeats | Malware, automation, remote signing | All of that, plus stored samples |

Touch mode is photoplethysmography. Arterial blood volume in the fingertip changes with each heartbeat, so light coming back through the ring bore carries a small pulsatile signal on a large steady one. The white LED gives a red channel, the 940 nm LED gives infrared, the AS7341 samples both at 50 Hz. **The ring bore is the sensor port in both modes**. A finger on it, or a cartridge under it.

### Seven gates, `firmware/touch_gate.py`

| # | Gate | Test | Catches |
|---|---|---|---|
| T0 | Capture rate | Achieved sample rate ≥ 20 Hz | A hardware timing fault. Not an anti-spoof gate, see below |
| T1 | Contact | DC level 8–85% of the empty bore | Nothing on the ring; or pressed so hard perfusion is occluded |
| T2 | Pulsatile | Perfusion index 0.3–10% | Static objects, printed photos, and, at the ceiling, motion |
| T3 | Rate | Dominant frequency 40–180 bpm | Anything not beating like a heart |
| T4 | Cardiac band | ≥45% of band power at the fundamental | Broadband noise, artefact |
| T5 | Variability | RMSSD 15–250 ms | **Mechanical pulsators.** A real heart is not a metronome |
| T6 | Haemoglobin ratio | Red/IR ratio-of-ratios 0.40–0.90 | **Dye-based fake fingers** |

T6 is the important one, and it is the same physics the blood mode uses at 415 nm applied to a living finger. A silicone finger with red dye pumped through it can produce a convincing pulse, but dye does not have haemoglobin's red-to-infrared absorption ratio. It also catches motion from the other side: a geometry change hits both wavelengths equally and drives the ratio toward 1.0, while real perfusion sits near 0.6.

**T0 exists because the sample rate is not a constant.** Every gate after it is computed in units of `fs`, so a capture taken at 8 Hz and analysed at a nominal 50 Hz reports a 68 bpm heart as ~11 bpm and fails T3. That sends the user hunting a heart problem that is really an I²C timing problem. `read_ppg` measures the rate it actually achieved and returns it; the analysis uses that number, and T0 refuses the capture outright if it is too low to analyse. The AS7341's chemistry integration time is 281 ms per channel and **cannot** produce a PPG waveform, touch mode switches to a short ATIME and back. See `hardware.py`.

Two of the thresholds are physiology, not tuning. **Perfusion above 10%** cannot be blood volume in tissue. The sensor or the finger moved. **Respiratory sinus arrhythmia** puts a healthy resting adult's RMSSD in the tens of milliseconds; a pump produces single digits.

### Touch is the default. Blood is a mode you enter.

Everyday operations run on touch. Blood is deliberate. You choose it, the way you'd choose to swear to something.

That only holds if the choice runs one way:

> **You can always escalate. You can never de-escalate.**

If blood were purely opt-in, an attacker holding the device and the PIN would simply never opt in, and the top tier would be decorative. So policy sets a floor. You may enter blood mode for a trivial transfer because it feels significant. That is a valid act and the device permits it. You may not go under the floor, ever, and there is no override.

**Changing the policy is itself blood-locked.** This is the rule people leave out, and it is the only thing separating a two-tier device from a one-tier device with extra steps. Without it the attack isn't "defeat the blood gate", it's "lower the threshold, then use a finger", which needs no blood at all.

Permanently blood-locked at provisioning, not configurable:

```
policy.change · key.export · device.wipe · device.reprovision · recipient.allowlist
```

Everything else is yours to set: an amount threshold, specific operation classes, or nothing at all.

### Escalation and the floor are different things

| | Scope | Persists? | Costs blood to change |
|---|---|---|---|
| **Escalation** | This one operation | No. The next one reverts to the floor | Nothing to change |
| **The floor** | A standing rule | Yes, until changed | **Yes, in either direction** |

Choosing blood for a single transfer changes nothing permanently; you paid more for one signature. Changing the floor is a different act, and it is blood-locked **both ways**.

Loosening must cost blood or a thief lowers the bar and uses their own finger. Tightening must cost blood too, or someone locks you out by raising your floor to blood-for-everything while you are travelling without cartridges.

Changing the rules costs blood, in either direction.

Running permanently at blood tier is `blood_above = 0`, blood for any positive amount, with every operation class locked.

`blood_above = None` is how you turn amount-based escalation *off*, leaving only the operation classes. The sentinel is spelled `None` and never `0`, deliberately: "blood above zero" reads to everyone as "blood for everything", and a value that quietly means the opposite is the wrong thing to hand someone hardening their own device.

Implementation in `firmware/policy.py`. It returns a reason alongside the tier so the device can display why blood is being requested rather than simply demanding it.

**Why the asymmetry matters most for proof-of-human:** one drop of blood is one signature, rate-limited by your body. A pulse can be produced all day. You cannot rent bloodstreams, but a hand can sit on a sensor indefinitely.

### Attesting the tier

A signature carries no information about what gated the key, so "this was signed with blood" has to be a **separate claim signed by a different key**. Each device holds an attestation key, generated in the ATECC608B at provisioning and never rotated. You record its public half once, the way you record an xpub.

`firmware/attest.py`. 238 bytes, fits in a QR:

```
magic 4 · version 1 · tier 1 · counter 8 · sighash 32 · fw_hash 32 · cal_hash 32 · live_hash 32 · pubkey 32 · sig 64
```

Four fields carry the security, and leaving any of them out breaks it:

- **sighash** binds the claim to one transaction. Without it a blood attestation can be lifted onto any other signature.
- **counter** is the device's monotonic counter. Without it an old blood attestation can be replayed for a new transaction.
- **fw_hash** says which firmware made the claim, so a verifier can refuse builds it doesn't recognise.
- **live_hash** is the gate's own measurements, compressed by `signer.liveness_digest()`. Without it the record says a tier passed but not on what evidence, so nothing ties the claim to a specific capture.
- **cal_hash** says which *thresholds* it was comparing against. The firmware hash pins the code and nothing else; every limit the gate can reject on lives in a per-device JSON file, and two devices on identical firmware can hold calibrations a factor apart. `blood_gate.calibration_hash()` computes it over the threshold files actually in force, and hashes an `UNCALIBRATED` sentinel when there are none, so a device still on shipped defaults is distinguishable rather than unattestable, and a co-signer decides whether that is acceptable.

**No timestamp.** The device is airgapped with no battery-backed clock, so it cannot honestly attest to time. The counter orders events; the coordinator's clock does the rest.

### The quorum case

`verify_quorum()` answers "everyone in this multisig signed with blood." Each signer's attestation key goes in a roster at setup; after that it is a mechanical check against one sighash.

**A missing attestation is a failure, not an abstention.** Otherwise the claim degrades silently into "everyone who bothered signed with blood," which is worth nothing.

### Attestations do not go on chain

They travel beside the PSBT in a BIP-174 proprietary field (prefix `CELL`) and are stripped before broadcast. Publishing one fingerprints the address as a CELL device and discloses how it was authorised. On-chain publication is possible and is a deliberate choice, never a default.

### What the attestation is worth

A device holding this key **states** that it ran the blood gate for this sighash. It does not prove the gate passed. You are trusting the firmware and the tamper seal.

This is the same assumption as a TPM quote or a Secure Enclave receipt. It is a real guarantee against a remote or careless attacker and none at all against someone who has opened the case and reflashed the firmware. State this to co-signers explicitly, since the chain does not verify it.

### Limits of the touch tier

Touch cannot prove *whose* finger it is. Neither can blood. That is the PIN's job. And a well-made artificial finger containing a genuine haemoglobin-like absorber, driven by a pump replaying recorded variability, would pass. That is a lab effort, not a lunch-break one, and it is beyond any remote attacker.

### Hardware note

The ring bore needs a **Ø10 × 0.5 mm clear window**, flush, sealing the optical chamber. It gives the finger a defined contact surface and keeps blood and dirt out. No anti-reflection treatment is needed: at 45° incidence the window's specular lobe exits at 45° and misses the 0° aperture, for the same reason the wet blood surface does.

---

## 5. Deployment model

This device is for **infrequent, high-consequence signing**, treasury moves, role authorizations, key ceremonies. Not trading. Everything below follows from that one fact.

### It holds spend authority and nothing else

| | Lives on | Blood |
|---|---|---|
| Spend key → your pubkey `P` | **Device** | Yes |
| Confidential note owner (same `P`) | **Device**, same key | Yes |
| Scan / view key | Companion | Never, it cannot spend |
| Gas account | Companion or relayer | Never. The device holds no gas |

No tiers, no spending thresholds. Every key on the device requires blood, because the only keys on the device are the ones that move value.

**The device never builds a transaction. It signs an authorization; the companion submits it and pays the fee.** So it holds no ETH, has no nonce, and never has to reason about calldata it can't read.

### The closed operation set

It signs exactly six things:

- A Bitcoin spend, amount, destination, fee, change ownership
- An Ethereum transfer, amount, destination, chain, nonce, worst-case fee
- An ERC-20 transfer of a **registered** token, amount, recipient, contract,
  chain, nonce, worst-case fee
- A confidential note spend, note, amount, recipient owner
- A direct transfer to a pubkey
- A transfer out of a registered smart account, as EIP-712 typed data, with
  the amount, the destination, the account, the chain and the account's nonce

And two things that move no value: cancelling a transaction the account's
timelock is holding, and an EIP-7702 delegation. See "The smart-account path"
below.

**It refuses everything else**, including generic EVM calldata and bare hashes. If the device can't render an operation as a sentence a human can read, it doesn't sign it. A device that displays `0x9a3f…` and asks for blood is worse than one that refuses.

**The ERC-20 transfer is the one exception, and how it is taken is the point.** The device is never handed calldata. It is handed a token, a recipient and an amount, and it *encodes* the 68 bytes itself — one selector, `transfer(address,uint256)`, and two arguments the screen already shows in full. A device that decodes calldata has to be right about every way 68 attacker-chosen bytes can be malformed; a device that writes them has to be right about one function. `approve` is not implemented, and neither is any other selector.

Tokens are registered in advance, like chains and quorums, and for a sharper reason than either: `decimals` is where the decimal point goes. A request that could supply it could render a millionth of a token as one whole token, and nothing downstream can catch that — the signature commits to the contract and the unit count, and to neither of the two strings the owner actually reads. See §12.

Two consequences of that rule are worth stating outright, because both look like missing features and neither is:

**One destination per Bitcoin transaction.** A PSBT paying several recipients is refused. The device shows one destination in full, on a screen the owner can check character by character; a batch would be a total they cannot. Split the payment, or batch at a layer above the signer.

**Every Ethereum field is displayed.** The chain id, the nonce and `gas_limit × max_fee_per_gas` are on the confirmation screen next to the amount. They are what the signature commits to, so they are what the owner is asked to approve. An unrecognised chain id is refused, because nobody can evaluate a bare number. A signature that does not pin the chain replays on every other EVM network the owner holds funds on. The device ships knowing four chains and is taught the rest by its owner; see §12.

Make this scope decision deliberately.

### The smart-account path

The first four operations are the EOA path. The device builds a whole EIP-1559
transaction, holds the account's nonce and prices `gas_limit × max_fee_per_gas`,
because an EOA has no other way to move value. That contradicts the rule two
paragraphs up: the device is supposed to sign an authorisation and let the
companion submit it.

A smart account is the shape that rule describes. The authorisation is an
EIP-712 `Execute` message, the account's own contract holds the nonce, and
whoever relays it pays the gas. So the device signs three fields and a domain,
holds no gas, and never reasons about a fee it cannot bound.

`chainId` and `verifyingContract` sit inside the EIP-712 domain separator, so
the signature is pinned to one chain and one deployment. That is strictly more
than the EOA path pins, and it is why the account is registered in advance:

```bash
python3 tools/provision.py smart-account --dir /boot/cell \
    --label treasury --chain-ids 1,8453 \
    --address 0xCcCCccccCCCCcCCCCCCcCcCccCcCCCcCcccccccC \
    --implementation 0xD54cb65224410F3Ff97a8E72f363f224419f4FB0 \
    --implementation-label "Multisig v1" \
    --threshold 2 --owners 0xCD2a...,0xbBbB... \
    --delay 172800 --executor 0x00000000a72A30AdBf38e14d36BCE2610ec3973F \
    --fast-track
```

An attacker who can choose `verifyingContract` chooses which account the owner
is spending from, so the device takes it from its own record and refuses every
account it was not told about. Same rule as a registered quorum, for the same
reason.

**This device must be one of the owners.** `--owners` has to contain the
address `provision.py show` prints for this device, and registration is refused
otherwise. The Bitcoin side has always enforced the equivalent — a quorum this
device holds no key in is refused — and the EVM side did not, so any address
could be registered and the device would take a drop of blood before the
account rejected the signature for coming from a stranger. The owner pays the
gate before anything on chain can tell them.

**One account, several chains.** `--chain-ids` takes a list because the factory
deploys by deterministic salt against a singleton implementation, so a quorum
lives at the same address on every chain it was summoned on. The chain comes
from the request and is checked against this list; it is safe to take it from
there and nowhere else, because `chainId` is inside the domain separator, so a
request naming the wrong chain produces a signature that deployment will not
accept. The alternative — one registration per chain — would mean eight labels
for one account, and the screen would then be naming the label rather than the
network.

### What the timelock does to the screen

The account contract packs a `delay` beside its nonce. When it is non-zero,
`execute` does not execute: it writes `queued[hash] = block.timestamp + delay`
and the transaction runs later. The signed `Execute` struct is `(target, value,
data, nonce)` and commits to **none** of that.

So one signature means "send now" or "send in two days" depending on chain
state the device cannot read, and a confirmation screen that cannot tell those
apart is asking for blood against an outcome the owner has not been shown. The
delay is recorded with `--delay` and stated:

```
  timing   HELD 2d after relay,
           or now if all 2 owners sign
```

The second line is the executor. `TimelockExecutor.forward` verifies **the same
EIP-712 Execute digest** the account does, so one signature from this device is
accepted by both routes and the companion picks which — through the account it
queues, through the executor with every owner's signature and `forwardEnabled`
on, it runs immediately. Both outcomes are on the screen because the owner is
consenting to both. Unanimity is what makes that acceptable rather than a hole:
fast-tracking needs *all* owners, so this device is one of the signatures
required, and no quorum short of everyone can shorten a delay behind its
owner's back. Record it with `--executor` and `--fast-track`.

### The one self-call

`data` must be empty, which keeps the operation renderable and means the
account's own governance calls are refused: changing owners, changing the
threshold, changing the delay all travel as `execute(target=self, data=...)`.

`cancelQueued(bytes32)` is the exception, and it is the exception that lets the
rule stand. A timelock's whole value is the window it opens between a
transaction being authorised and it running; cancelling is what an owner does
*in* that window, and a device that can start a delay but not stop one has
given its owner a countdown and no button. It is safe to render where the
others are not because its calldata has exactly one shape — four bytes of a
selector the firmware fixes, then one 32-byte hash and nothing after it — so
the screen can state the whole of what the signature commits to.

It is **touch tier, deliberately**. `account.cancel` is not in `ALWAYS_BLOOD`.
Everything the operation can do is subtract: it moves no value, it cannot
create a transaction, and the worst outcome of signing one wrongly is that a
transfer has to be proposed again. Meanwhile the case for cancelling is usually
that something is wrong and the clock is running. The expensive gate must not
stand between an owner and the stop button.

Nothing else is decoded. One selector is one sentence to get right; a table of
them is a table of sentences.

### What the companion holds up to the camera

A PSBT is recognised by its magic bytes. Everything else is a flat JSON object
with a `type`, and a request carrying a field the device does not know is
refused rather than ignored — a field it cannot display is a field the owner
cannot consent to.

```json
{"type": "cell-eth-tx", "chain_id": 1, "nonce": 3, "to": "0x5aAe…",
 "value": 100000000000000000, "gas_limit": 21000,
 "max_fee_per_gas": 25000000000, "max_priority_fee_per_gas": 1000000000}

{"type": "cell-account-execute", "account": "treasury", "chain_id": 1,
 "to": "0x5aAe…", "value": 100000000000000000, "nonce": 4}

{"type": "cell-account-cancel", "account": "treasury", "chain_id": 8453,
 "tx_hash": "0xabab…", "nonce": 5}

{"type": "cell-delegate", "account": "mine", "chain_id": 1, "nonce": 0}
```

The account is named by **label**, never by address. The address, the domain,
the implementation, the timelock and the owner count all come from the device's
own registration, so a request cannot choose which account it is spending from
— that is the whole reason the registration is a record rather than a payload.
The delegation request carries no address at all, for the reason above.

The EOA path emits a raw transaction, which is self-describing. The other three
emit a signature, which is not: sixty-five bytes say nothing about which
account they authorise, on which chain, at which nonce, or through which route.
So the fields the device displayed are the fields it emits.

```json
{"type": "cell-signature", "for": "cell-account-execute",
 "account": "treasury", "chain_id": 1, "nonce": 4,
 "signer": "0x9f3c…", "digest": "0x…", "signature": "0x…"}
```

A companion that rebuilds the digest from this envelope and gets a different
answer knows the two disagree before it spends any gas finding out.

**EIP-7702 delegation is blood-locked, unconditionally.** The authorisation is
`keccak(0x05 || rlp([chain_id, address, nonce]))`. Three fields, all
displayable, and it moves nothing. It also decides what every later signature
from that address means, which makes it reprovisioning under another name, so
`policy.ALWAYS_BLOOD` holds `account.delegate` and no policy can unlock it.

Two rules the device enforces on a delegation. Chain id 0 is refused: it is
legal, and it means the authorisation is valid on every chain that exists and
every chain that ever will. And the implementation must be registered first,
because the signature commits to an address and to nothing whatever about what
that address contains.

**What delegation costs you, and it is not small.** A 7702 delegation leaves
the EOA key a superuser. That key can still send ordinary transactions and can
revoke the delegation, so a timelock or a guard on a delegated account bounds a
relayer and does not bound the key holder. For a device whose whole argument is
that one path in is chosen once, that matters: use the factory-deployed account
when the timelock has to be a security property, and the delegated EOA when the
point is to add guards and recovery to an address that already holds funds.
`provision.py smart-account --delegated-eoa` records which one this is.

**The device only ever delegates its own key.** A 7702 authorisation commits to
the implementation, the chain and the nonce, and never to the address being
delegated — the authority is whoever signs. So an account address taken from a
payload would be a caption on a screen rather than a fact about the signature:
the owner reads an address they do not recognise, approves it at blood tier,
and delegates their own. Registration with `--delegated-eoa` therefore refuses
any address that is not this device's, and takes the device's own when
`--address` is omitted:

```bash
python3 tools/provision.py smart-account --dir /boot/cell \
    --label mine --chain-ids 1 --delegated-eoa \
    --implementation 0xD54cb65224410F3Ff97a8E72f363f224419f4FB0 \
    --implementation-label "Multisig v1" --owners 0x9f3c...
```

`--implementation-label` is required to delegate. The screen refuses to render
an implementation the owner has no name to check the address against, and
before this flag existed there was no way to set one — so every account
registered through this command produced a delegation that could not be
displayed, and the path was unusable.

**One gap that signing cannot close.** A 7702 authorisation does not commit to
the initialisation call that has to run in the same transaction, so a relayer
can delegate to the implementation the owner approved and initialise it with
their own owners. That is security consideration 2 of the EIP itself.

The device has no network and will not get one, so the check happens out of
band. Have the companion read `owners()`, `threshold()`, `delay()`,
`executor()`, `forwardEnabled()` and the delegation target into a JSON file,
and diff it against what the device believes:

```bash
python3 tools/provision.py verify-account --dir /boot/cell \
    --label treasury --state state.json
```

```
  owners          MATCH        ('0x9f3c…', '0xbbbb…')
  threshold       MATCH        2
  delay           DIFFER       recorded 172800
                               on chain 0
```

It exits non-zero on any disagreement, and separately says so if this device is
not an owner on chain. Run it before you fund an account and again after a
delegation lands. It proves nothing about the RPC that produced the file — an
owner who is worried should take the numbers off a block explorer — but it
turns "I think I typed it right" into an answer. `VALIDATION.md` carries the
underlying gap open, because no signature can close it.

### Proof of life

The device signs one thing that authorises nothing. A beacon asserts that a
living human authenticated here during one period, and it is the only operation
whose chain never unwraps the seed: the claim is made by the attestation key in
the secure element, so `signer.SignRequest(needs_seed=False)` skips the unwrap
entirely and `EXPECTED_ORDER_NO_SEED` is asserted beside the ordinary order.

Touch tier, by policy and by design. Proof of life that costs a lancet is proof
of life nobody produces, and a dead-man switch that fires on the living is
worse than no switch. `life.beacon` is in `KNOWN_OPS` and not in
`ALWAYS_BLOOD`, and an owner who wants it blood-locked can still do that
through the policy floor.

The period is the whole of what the owner can check, so it is the first thing
on the screen and it is spelled out as two dates. The chain enforces the rest:
`heartbeat` takes a beacon only while its period is the current one, which
means a harvested record cannot be spent early or late. `firmware/beacon.py`
states plainly what that does and does not bound.

### Dual chain is nearly free

Bitcoin and Ethereum both use secp256k1, so one signing core serves both. The difference is transaction encoding, not cryptography. The same spend pubkey can own value on either side, which means one identity and one blood-gated key rather than two devices.

If you're pairing this with a protocol that already derives a tree from one root: keep the spend key on the device, keep the scan key off it, and **make the root's origin exclusive at provisioning.** If a key born in this device can also be reached through a passkey or an exported seed on a laptop, an attacker never touches the device and the blood gate is decoration next to an open door. One path in, permanently, chosen once.

### Dormancy is the real failure mode

A device used twice a year spends 364 days in a drawer. That is where it fails, not under load.

- **No battery.** A LiPo left at partial charge for a year deep-discharges, swells, and occasionally catches fire. USB-C power only. You're at a desk when you use this.
- **No reagents.** Dried clotting accelerants drift with humidity, so cartridges that sit for a year drift with them. Native clotting instead, over a **600 s** window. Indefinite shelf life.
- **Two sealed test cartridges** (below). This is the part that matters most.

### Pre-flight

Per-cartridge references tell you the *cartridge* is fine. They tell you nothing about whether the LED has aged or the optics have fouled over a year in storage. Two sealed cartridges, made once and kept with the device, cover that:

| Cartridge | Contents | Must |
|---|---|---|
| **REFERENCE** | A stable, characterised spectral target, sealed under a bonded PET window | Read within tolerance of the value recorded at provisioning, and **fail the coagulation gate**: it can't clot |
| **NULL** | A red target with no absorption at 415 nm. A printed or painted swatch | **Fail Gate 1.** If a red target ever passes, stop using the device |

The reference cartridge is a **drift check, not a blood simulant.** It verifies the optical chain, LED output, sensor response, geometry, still reads a known target the way it did on day one. It is not trying to imitate blood.

Before any signing that matters:

```
1. Insert NULL       → must reject at Gate 1 (too bright)   ~40 s
2. Insert REFERENCE  → spectral gates within tolerance,
                       G5 rejects it: it cannot move         ~90 s
3. Proceed
```

Under three minutes for the pair, because neither cartridge runs the full ten. NULL fails on chemistry and stops at t = 5 s. REFERENCE passes chemistry and then simply sits there, so what stops it is G5, at the close of the 60 s early window; §7 has both aborts. That fits the ritual this device already is, and it's the check a role-based signer should have and a trading wallet never would.

### Write the PIN down

Not next to the device, **with the seed backup, in the other location.**

For a device used twice a year, forgetting the PIN is a more likely loss event than burglary of two separate locations. And the failure is asymmetric: a forgotten PIN with a working device is recoverable from the seed; a compromised seed is not recoverable at all. Different people will weigh this differently, but for this audience that's the right default.

---

## 6. Parts (~US$97 complete, ~US$63 for the reader alone)

| Item | Part | ~USD | Notes |
|---|---|---|---|
| Compute | Raspberry Pi Zero 2 W | 15 | Radios get disabled *and* the antenna trace cut |
| Gate chip | ATECC608B breakout (Adafruit 4314) | 6 | Wallet kit. PIN counter, AES key storage, KDF |
| Spectrometer | AMS AS7341 breakout (Adafruit 4698) | 16 | 8 colour channels + Clear + NIR. Drives an LED directly |
| Laser | 650 nm diode module, ≤5 mW | 2 | Liveness gate. Coherent source is mandatory. An LED will not produce speckle |
| Camera (speckle) | Pi Camera + **mini**-CSI cable | 10 | **Reader kit.** Lens removed. Fixed exposure/gain, see §8 |
| Display | ST7789 1.3" 240×240 SPI | 8 | Wallet kit |
| Camera (QR) | Cheap USB webcam | 8 | Wallet kit. **Not a second CSI camera**. The Pi Zero has one CSI port and the speckle path has it. QR decoding tolerates auto-exposure |
| USB OTG adapter | micro-USB male → USB-A female | 2 | Wallet kit. The Zero's ports are micro-USB. Without this the webcam does not physically connect |
| Buttons | 6 mm tactile ×3 + 12 mm tactile ×1 | 3 | Wallet kit. The 12 mm one is CONFIRM, on its own pin. The deck is drilled Ø6.3 on an 11 mm pitch for the three and Ø9.1 for CONFIRM, so a 12 mm body will not fit the other three positions |
| LEDs | 5 mm white ×2, 940 nm IR ×1, 2N7002 ×3, resistors | 2.75 | One MOSFET each for LED #2, the IR LED and the laser, see §11 for the rails |
| Cartridge switch | **DPDT** snap-action microswitch, lever | 1.00 | Reader kit. Two poles: GPIO22 on one, the laser supply on the other (§9). One pole cannot do both |
| Power | USB-C breakout, power only | 2 | **No battery**, see §2. Desolder D+/D− or use a data blocker. **Confirm it carries 5.1 kΩ CC pulldowns**, see §11 |
| Storage | 16 GB A2 microSD | 6 | |
| Prototyping | Small breadboard + jumper wires | 5 | Reader kit. No PCB is needed to prove the sensing |
| Test cartridges | Printed once, sealed, kept with the device | 0 | Wallet kit. REFERENCE + NULL, see §5 |
| Filament | PETG black ~90 g, white ~60 g | 5 | Not PLA |
| Fasteners | M2.5×16 + heat-set inserts ×6 | 2.20 | Includes the four M2 self-tappers for the display. **Not a shorter screw:** it enters from the base and has to cross the part line at 11.4 to reach an insert seated 6 mm into the upper shell |
| Ring window | Ø10 × 0.5 mm clear acrylic or glass disc | 1 | Seals the chamber, contact surface for touch mode |
| Chamber diffuser | Ø6 mm ground glass, 220 grit or finer, + opaque black 5-minute epoxy | 2.50 | Wallet kit. The tamper boundary, see §9. Skip it and the device still signs; the case just stops being part of the key |

**Consumables:** contact-activated sterile lancets 28G/1.8 mm (~$0.06 ea, any pharmacy), alcohol prep pads, 0.1 mm PET film for cartridge windows (transparency or laminating pouch, ~$8/100 sheets ≈ 1,600 windows), a 1 L sharps container. No reagents. Nothing here has a shelf life.

**Optional, later:** MLX90614-DCI infrared thermometer (~$15) adds a sixth gate. See §3 for why it isn't in the core build. It must be the DCI variant; the 90° version images the whole chamber rather than the sample.

### Buying it

Most of this is generic and any supplier will do. Five items are not, and
picking the wrong one costs a rebuild rather than a return.

| Item | What to insist on | What goes wrong otherwise |
|---|---|---|
| **ATECC608B** | The **608B**, on a breakout with I²C pulled out. Adafruit 4314 or the SparkFun equivalent | The 508A and 608A are different parts; 608A is end-of-life. Footprints and libraries look identical |
| **AS7341** | Adafruit 4698, or a clone that brings out the **LDR/LED driver pin** | Boards that omit that pin cannot drive LED #1 directly and §9's wiring does not apply |
| **ST7789 240×240** | A module with a **CS pin broken out** | Many 1.3" 240×240 boards hard-wire chip select. §11 puts the display on SPI0 CE0; without CS you cannot share the bus and the pinout in §11 is wrong for your board |
| **Pi camera** | An **OV5647 (v1-style)** module, plus the **narrow 22-pin "Zero" CSI cable** | The lens has to come off (§9). v1 modules unscrew; v3 does not come apart the same way. And the Zero's connector is narrower than a full-size Pi's. The standard cable will not fit |
| **650 nm laser** | A **module with a driver board**, 3–5 V in, ≤5 mW, with a lens you can defocus | A bare laser diode without current limiting dies the first time you power it |

The **USB webcam** only has to resolve a QR code at roughly a hand's distance.
Fixed-focus units often cannot focus that close. One with a manual focus ring
is the safer buy, and it is the cheapest part in the wallet kit to get wrong.

Lancets, alcohol pads and the sharps container come from any pharmacy. PET
window film is laser-printer transparency or laminating pouch stock. The 3M
300LSE tape is worth buying by name: it is 0.05 mm, and thicker double-sided
tape changes the optical path length the cartridge was dimensioned around.

### Tools

Assumed, and not in the bill: a 3D printer (see `PRINTING.md` for what it has
to be able to do), a soldering iron, **with a heat-set insert tip**, which is
the one tool people do not already own, digital calipers, a small screwdriver
set, and a craft knife with fresh blades for the antenna trace and the PET
windows. A multimeter is not required but you will want one the first time a
bus does not answer.

Also assumed: a **5 V supply good for 2 A** and a USB-C cable. The Pi Zero 2 W
peaks near 0.5 A on its own, and the QR webcam, the laser and the LEDs are all
drawing at the same moment during a blood run. A 1 A phone charger will brown
the Pi out mid-capture, which looks like a sensor fault rather than a power one.

### Cost reduction

| Target | Change | Cost |
|---|---|---|
| **~$70 today** | Original Pi Zero instead of the 2 W. It has no radios to disable. One less build step and one less thing to get wrong. Cheapest USB webcam for QR | −$20 |
| **~$60, worth testing on the reader** | Replace the AS7341 with four discrete LEDs (415, 525, 630, 940 nm) and one photodiode, flashed in sequence. Classic multi-wavelength colorimetry. You lose spectral resolution, but the speckle gate does the security work. The colour half only has to establish "this is blood" | −$12 |
| **~$40 at ~100 units** | One custom PCB with bare parts. The AS7341 die is ~$3 against $16 for the breakout; the ATECC608B ~$1 against $6 | −$30 |

Most of the current bill is the cost of breakout boards rather than the silicon on them.

**Deliberately not included:** no secure element beyond the ATECC608B (the seed is backed up anyway, so a $32 non-exportable-key chip buys little here), no fingerprint sensor (the PIN does identity), no impedance analyser, no battery.

---

## 7. How the sensing works

**Six gates, all must pass.** Full implementation in `firmware/blood_gate.py`; every threshold lives in one `Thresholds` dataclass.

| # | Gate | Test | Catches |
|---|---|---|---|
| 1 | **Return signal** | Clear channel in a **window**, 0.015–0.35 of the white patch | Too dark: empty dark well, any non-scattering liquid. Too bright: an empty white well, or a painted swatch, including the NULL cartridge |
| 2 | **Cellular scatter** | White-normalised NIR/Clear ≥ 2.2 | Dye solutions, haemolysed blood. A solution, not a suspension |
| 3 | **Haem Soret band** | (R630−R415)/(R630+R415) ≥ 0.75 | Every kitchen fake. No common red substance is a porphyrin |
| 4 | **Spectral shape** | SAM cosine ≥ 0.995 over the **unclamped** channels | Deoxygenated and met-haemoglobin, blood that is old, venous, or otherwise not a fresh capillary draw |
| 5 | **Free motion** ⭐ | `D(early) ≥ 0.60`, speckle contrast valid | Already-clotted blood, syrups, gels, anything that was never liquid |
| 6 | **Motion arrested** ⭐ | `D(late) ≤ 0.25`, drop ≥ 0.35, ρ ≤ −0.70 | **Anticoagulated blood.** This is the anti-replay gate |

Gates 1–4 are evaluated at t = 5 s **and the capture aborts there if any of them fail**, so an obvious spoof is rejected in seconds instead of ten minutes.

**Gate 5 aborts too, one window later.** It reads only the frames inside the first 60 s, so the moment that window closes its verdict is fixed and the remaining nine minutes cannot move it. Everything that was never liquid leaves there: corn syrup, gels, already-clotted blood, and the sealed REFERENCE cartridge the pre-flight in §5 runs before every signing session.

**Gate 6 is the one that needs the whole run,** and it is deliberately not abortable. Its question is whether the sample arrested by the end, and no earlier moment answers it.

An abort is a latency win only if it cannot change an answer, so `test_gate_robustness.py` runs all 18 spoof classes both ways and requires the two verdicts to match gate by gate. `calibrate.py` disables both aborts, because calibration wants the whole speckle series even for samples that fail on chemistry.

### Gate 1 is a window, not a floor

A floor alone cannot reject a *bright* sample, and two of the things that must be rejected are bright: an empty white well reads ~0.97 of the white patch, and a red painted swatch ~0.58. Whole blood reads ~0.15. The NULL pre-flight cartridge is exactly a bright red swatch, so §5's "NULL must fail Gate 1" only holds with the ceiling in place.

### Gate 2 is normalised before the ratio is taken

Clear is read under the white LED and NIR under the 940 nm LED. A raw `nir/clear` ratio is therefore set largely by the two drive currents and drifts as they age. The exact effect the printed white patch exists to cancel. Both channels are normalised against the patch first, so what remains is a property of the sample.

### Gate 4 ignores the clamped channels

SAM is computed only over the channels not pinned at the absorbance clamp. A clamped channel holds the same value for every sample dark enough to reach it, so including it contributes a constant to every vector and drags all cosines toward 1. Measured against the shipped reference: with 415 nm included, deoxygenated blood scores 0.991 against a 0.985 threshold and is **accepted**. Excluding it, genuine sits at 0.99999 and deoxyHb at 0.98821. A margin ten times larger relative to sensor noise. The mask is derived from the reference at import, so enrolling your own reference recomputes it.

### The 415 nm channel saturates

Whole blood is roughly **4,600 absorbance units per centimetre** at 415 nm. In an optically semi-infinite well the 415 channel sits at the ADC floor, and an absorbance computed from a floor reading is numerically meaningless. It is unbounded and unstable, and a very dark dye floors there too.

Gate 3 is therefore a **normalised difference index**, bounded in [−1, 1], which never divides by a floor value. Gate 1 has already established that the sample returns real signal, so the ratio is meaningful when it is computed. Absorbance is still used for Gate 4's shape comparison, but **clamped** at 2.5, hitting that clamp on the 415 channel is the expected result for genuine blood, not an error.

### Timing

Native whole blood on a plastic surface clots far more slowly than on glass, which is a strong contact activator. The closest published work to this approach used finger-prick samples in glass microchannels and observed for 35 minutes. Ten minutes on PETG carries margin.

For a device used twice a year this costs nothing, and it removes any need for a clotting accelerant, which would carry a shelf life in a device that spends 364 days in a drawer.

---

## 8. The cartridge

**This is the part that needs care.** Everything else is ordinary electronics.

**51 × 14 × 2.4 mm, white PETG, 0.15 mm layers, 100% infill, top-surface ironing ON.**

**It reads at two stops.** There is one aperture and one read spot, 31.6 mm behind the front face, so the patch and the well cannot both be under it at once. They take turns:

| Stop | Insert to | Under the aperture | What the device reads |
|---|---|---|---|
| 1 | 34.6 mm, the first click | the white patch, centred 3.0 mm from the tip | white reference, then dark with the LEDs off |
| 2 | 42.1 mm, pushed past the detent | the well, centred 10.5 mm from the tip | the sample, then 600 s of speckle |

A low detent ridge across the top at 34.6 mm meets the slot lip and gives you the first stop by feel. It stands 0.35 mm proud into 0.6 mm of slot clearance, so a deliberate push rides over it. It is a tactile stop, not a lock.

**The order is load-bearing.** Every gate is normalised against the patch, so a white reference taken at the second stop is a reading of the sample against itself: absorbance collapses to zero and the device rejects genuine blood at G1 while reporting "far too bright to be whole blood". `hardware.py` refuses both mistakes instead of measuring through them. It will not read white with the cartridge seated, and it will not read the sample without the seating switch closed.

The length follows from the geometry: the well must reach the read spot, which puts 42.1 mm of the cartridge inside, leaving 8.9 mm proud of the slot to grip. Shorten it and you are fishing a blood-contact part out of the slot with your fingernails.

| Feature | Dimension | Why |
|---|---|---|
| Sample well | Ø4.0 × 0.55 mm deep (≈7 µL) | See below |
| Overflow moat | Ø7.0 annulus, 0.4 mm deep | Accepts 8–15 µL without flooding the optics |
| White reference patch | 4 × 4 mm, ironed, coplanar with the well rim | Per-measurement normalisation |
| Lid | 0.1 mm PET film, taped along one edge | Optical window. **The tape is the hinge**. No printed living hinge to tune |
| Grip tab | 8.9 × 14 mm, proud of the slot | Keeps fingers off the optics |

Four features in total. Two of them matter more than their size suggests:

**The well is optically semi-infinite.** At ≥0.4 mm, essentially no light penetrates whole blood and returns from the floor. Reflectance becomes independent of fill volume *and* of the backing, which is why 8–15 µL is an acceptable tolerance instead of a pipetting requirement, and why the well floor's print finish is irrelevant. Only the *white patch* needs a good surface. **Don't "improve" this by making the well thinner.**

**Every cartridge carries its own white and black references.** LED aging, sensor drift, and print variation are all first-order effects that would walk your thresholds out of spec within weeks, silently. Normalising against a patch printed in the same layer, on the same part, from the same filament cancels nearly all of it. This one choice is the difference between a device that works for a year and one that works for a week.

**No black reference feature.** The dark reading is taken at the *same position as the white patch with the LEDs off*, dark current plus any ambient leak, for free. That removes a printed feature from every cartridge, and the light-tightness test in §9 is what validates the assumption.

### Printing them

```bash
python3 tools/gen_printables.py     # -> models/print/*.stl
```

That one command builds everything printable. The shells included, via `tools/gen_enclosure.py`, dimensioned from the constants in this section: the cartridge, the pre-flight REFERENCE and NULL bodies, the aperture tube, the optical head, the slot baffle, the display bezel, the rear bay blank, a jig for cutting the PET windows, and the two shells. It validates each mesh before writing it. Every shell closed, consistently wound, positive in volume, and exits non-zero instead of handing a slicer something it would have to guess at. It also re-checks the cartridge geometry, the bezel, and the filament the BOM buys against what the parts actually weigh. `models/print/MANIFEST.md` is regenerated in the same pass and lists quantities, orientation, settings and every dimension the generator had to derive. It is interpolated from those constants, so it cannot drift from the STLs beside it. `PRINTING.md` walks the whole print through in order.

**Why the well sits 10.5 mm back.** It has to leave room for a 4 mm patch *ahead* of it. Features nearer the tip cross the read spot first, so a patch ahead of the well is read before the sample; a patch behind it would only be reachable after the sample had already been read, which is no use for normalising that same reading. At the original 6.0 mm the moat wall was 2.5 mm from the tip and there was nowhere to put the patch at all, which is exactly how this shipped with a white patch that no optical path could reach. `tools/gen_printables.py` re-checks all six distances on every run and refuses to write a cartridge that breaks any of them.

**Windows:** cut 12 × 10 mm rectangles from 0.1 mm transparency film. Tape one edge to the cartridge body with 3M 300LSE so it flips up to load and down to close. Handle by the edges. A fingerprint on the window is a calibration error.

---

## 9. Optical head

```
                    AS7341
                      │  ← 9.0 mm standoff
                 ┌────┴────┐
                 │ Ø3 × 6  │  aperture tube, matte black inside
    white LED    └────┬────┘    white LED
        ╲             │             ╱
         ╲ 45°        │ 0°     45° ╱      ← 12 mm from spot centre
          ╲           │           ╱
    ══════════════════▼══════════════════   PET window
              [   whole blood   ]           well, 0.55 deep
    ─────────────────────────────────────   white PETG cartridge body
```

**The 2 ms exposure has 2.5x of margin, and the failure is not the obvious one.** `firmware/speckle_sim.py` models the scattered field as an Ornstein-Uhlenbeck process and integrates it over the exposure, which is the only way to see this: a frame that averages many independent speckle patterns loses contrast AND looks like the frame before it, so liquid blood reads as arrested. Swept against the shipped thresholds at a 0.3 ms correlation time, liquid still reads liquid at 2 ms and fails G5 by 5 ms. It fails toward a false REJECT rather than a false accept, and only because G5 runs first, without the free-motion check the same blur would satisfy G6 and be read as a clot.

**The camera rate sets how still a clot has to be.** At 30 fps the same model reads liquid up to a 31 ms correlation time and arrest from 269 ms, so clotting has to raise tau_c about ninefold, through a band where the sample reads as neither and is rejected. A faster camera narrows that band: 120 fps moves it to 7.4 ms and 64 ms. Recording tau_c against time for one genuine clot is the first measurement the speckle path needs.

- **45°/0° is not decorative.** Wet blood is glossy. A normal-incidence lamp would swamp the sensor with surface reflection carrying zero chemical information. At 45° the specular lobe exits at 45° and misses the aperture entirely.
- Two opposed LEDs cancel directional shading from droplet asymmetry.
- The aperture tube defines a 3 mm spot inside the 4 mm well, so the sensor never sees the meniscus at the edge.
- White LED #1 runs off the AS7341's own `LDR` driver pin, which gives synchronised flash/measure timing for free. LED #2, the IR LED and the laser each gate through their own 2N7002, **three** of them, on two different rails. See §11.

### The speckle path

A second, independent optical path in the same chamber.

```
   laser diode 650 nm            camera, LENS REMOVED
        ╲  ~30° off normal            │  ~20 mm from the spot
         ╲                            │  off the specular axis
          ╲                           │
    ═══════▼═══════════════════════════════════   PET window
              [   whole blood   ]
```

| Item | Spec | Why |
|---|---|---|
| Source | 650 nm diode module, ≤5 mW | Coherent light is mandatory. An LED's coherence length is microns. It produces no speckle |
| Interlock | Laser energised only when the cartridge switch is closed | The chamber is sealed, but wire the interlock anyway. Put a switch pole in **series with the laser module's supply**, not in the GPIO6 gate line. An interlock the firmware can talk its way past is not an interlock. GPIO6 then gates a laser that is already dead with the chamber open. **This is why the switch is DPDT.** The other pole is GPIO22, and the two jobs need two poles, see §11 |
| Camera | Pi Camera, **lens unscrewed and removed** | Lensless speckle grain ≈ λz/D ≈ 4.3 µm at 20 mm over a 3 mm spot, about 3.1 pixels on the OV5647's 1.4 µm pitch, inside the 3–5 px check below. (On an IMX219's 1.12 µm pitch the same grain is 3.9 px; §6 specifies the OV5647 because its lens unscrews.) With a lens fitted the grain falls to ~1.6 px and is undersampled |
| Standoff | ~20 mm, off the specular axis | |
| Settings | **Fixed** exposure ≤2 ms, fixed gain, AWB off, denoise off | Any auto-adjustment between frames destroys the correlation measurement. This is the single most common way to get garbage out of this sensor |
| Capture | 128×128 ROI, 16 frames per burst, one burst every 20 s | |

**Verify before trusting it:** take the 2-D autocorrelation of a single frame. The central peak should span 3–5 pixels. Narrower means undersampled speckle; broader means you are imaging something other than speckle.

**The two paths must not run at once.** The laser contaminates the 630 nm channel and the white LEDs wash out the speckle. Interleave: LEDs on for the chemistry read at t = 5 s, laser only during bursts.

**Light-tightness test:** cartridge inserted, room at 10,000 lux, all LEDs off. The Clear channel must read under 0.5% of its LEDs-on value. Print the chamber in black PETG at ≥4 perimeters and paint the interior matte black. Thin PETG passes more light than you'd expect.

**Cartridge slot:** 34.0 × 3.0 mm on the front edge (model: `front_slot`), with a sprung silicone flap plus a 6 mm offset baffle behind it.

### The chamber diffuser

A Ø6 mm ground-glass disc, epoxied into the chamber wall. It is what makes the
enclosure part of the key: `firmware/optical_puf.py` reads its speckle at every
unlock and mixes the result into the seed-wrapping KDF, so a case that has been
opened derives a different key and the seed does not unwrap. Skip it and the
device still works. The KDF term is simply absent, but the tamper binding is
what you are skipping.

| | |
|---|---|
| Position | Chamber wall, lit by the same 650 nm diode, imaged by the same camera. **Clear of the cartridge's optical window** |
| Standoff | ~20 mm, as for the blood path, so the grain lands at the same 3–5 px |
| Bond | Two-part epoxy, opaque black, filling the void behind the disc |
| Capture | 768×768 ROI, 16 frames, averaged |

**Clear of the cartridge window** is the constraint that matters. If a seated
cartridge is in the diffuser's optical path, then changing cartridges changes
the reading and every cartridge change looks like tampering. The laser
interlock still applies, so the bay must be closed for the read, the cartridge
closes the bay, it must not be part of the measurement.

**The mount matters as much as the bond.** A speckle grain is about 4 px, so
the pattern only has to slide one grain for the raw features to be destroyed —
and PETG over the 20 mm standoff moves roughly a pixel per kelvin, which makes
a cold morning enough on its own. `optical_puf` registers every read against
two published fiducial patches before it reads anything: ±24 px of slide and
about 3° of twist come out, and both are reported rather than merely absorbed,
so a chamber that is drifting can be told from one that has been opened. Keep
the standoff rigid and the whole assembly moving together, the budget is there
for thermal creep, not for a camera free to wander.

**Not hot glue, and not tape.** Both creep with temperature. The diffuser has
to be in the same place in six months as it is today, because "the same place"
is what the key is. Epoxy it once and leave it.

**768×768, not the 128×128 the blood path uses.** The PUF spends grains on key
material, on the margin filter that discards the unreliable ones, and on a rule
that no two key bits come from touching grains, neighbouring grains share the
tail of one speckle lobe and are not independent. Same sensor, same optics, a
larger crop; `hardware.read_chamber_burst` switches the mode and switches back.

**Averaged, unlike the blood burst.** There the frames carry the signal and
averaging would destroy it. Here the pattern is meant to be static, so the
frames are repeated looks at one thing and averaging buys shot-noise margin.

**Keep something in the slot.** This is the part that surprises people, so it
is worth stating on its own. The chamber is read at EVERY unlock, because its
answer is a term in the key that opens the seed, and the laser interlock is
wired through the cartridge switch, in series with the diode's supply, where
firmware cannot reach it. So on a chamber-enrolled device the bay has to be
closed for a **touch** signature too, not only for a blood one, even though
touch consumes nothing and involves no cartridge.

Leave a cartridge seated between spends. A spent one does, and so does
`cartridge_null`, which has no well and is already on the print list. Swap in a
fresh cartridge when you are actually bleeding into it. The diffuser sits clear
of the cartridge window either way, so which one is in there changes nothing
about the reading.

A device that has NOT enrolled a chamber never reads it, and none of this
applies.

---

## 10. Enclosure

**Printing the shells:**

```bash
python3 tools/gen_enclosure.py      # -> models/print/shell_lower.stl, shell_upper.stl
```

The viewer model is an appearance model, solid extrusions, with the openings drawn as dark boxes and nothing cut out. Slice it and you get a brick. `tools/gen_enclosure.py` is the source for the inside: 2.4 mm wall, the part line at 11.4 with a tongue and groove, the four openings actually removed, six M2.5 insert bosses, rails the Pi slides in on, and the light-tight skirt around the optical chamber. It re-checks the envelope against the figures below on every run, and re-checks that the thing can still be assembled, cartridge path, blind vents, Pi bay, sensor port, part line. Both files are parametric; the checks are what keep them describing one instrument.

**`viewer/model.js` is the parametric source of the enclosure.** It builds the geometry; `models/instrument.obj` is an export from it, and `diagrams/mechanical.svg` is generated from that export by `tools/gen_mechanical.py`. The chain is one-way:

```
viewer/model.js  ──export──▶  models/instrument.obj  ──generate──▶  diagrams/mechanical.svg
```

Edit the model, re-export, re-run the generator. CI fails if the drawing and the OBJ disagree. Do not hand-edit the OBJ. It is 54 MB of triangles and nothing downstream of it can be reconciled with a parametric change.

**Envelope: 116.2 × 73.2 × 28.3 mm.** Two shells parted at 11.4 mm from the base, with the seam picked out in oxblood. The Pi enters from the rear like a cartridge; the sample cartridge from the front, on the same centreline as the dish.

| Feature | Dimension | Notes |
|---|---|---|
| Sample dish | Ø47.2, 2.0 deep | Recessed into the deck. The optical head sits above it |
| Ring | Ø14.4 OD / Ø9.8 ID, 1.5 proud | Oxblood, smooth bezel. **A marker for the measurement spot, not a control, nothing rotates** |
| Index ticks | 60 @ R21.2, every 5th in steel | Around the dish |
| Display | 49.7 × 37.7 | Flush glass, oxblood bezel |
| Buttons | 3 × Ø5.8 + 1 × Ø8.6 | The Ø8.6 is CONFIRM, with its own collar. The three navigation holes are on an 11 mm pitch, which takes a 6 mm switch body; CONFIRM has 17 mm to itself and takes the 12 mm one |
| Pad | 24.0 × 12.0 | Printed marking. **Reserved, see below** |
| Sample slot | 34.0 × 3.0, 4.2 deep | Front face |
| Compute bay | 72 × 16, 3.2 deep | Rear face |
| USB-C | 9.0 × 3.2 | Right face, power only |
| Vents | 15 slots, 1.6 deep | Front face. **Must be blind, see below** |
| Fasteners | 2 × Ø4.0 slotted | Front face, lower shell |

### Constraints not expressed in the model

**1. The vents must be blind pockets.** They are cut 1.6 mm into a 2.4 mm wall, leaving 0.8 mm of material behind them. The 3.0 this section used to specify was safe in a solid appearance model and is 0.6 mm past the inside face of that wall. Keep them that way. If any becomes a through-hole, ambient light reaches the optical chamber and the 415 nm gate stops working. Verify with the light-tightness test in §9, not by eye.

**2. The pad is reserved, not fitted.** It is a flat printed marking sized for the optional fingerprint sensor, which the base build doesn't use. The PIN does identity (§4). It is deliberately not a recess: an unpopulated pocket on the deck is a place for blood to collect.

**3. The dish is a reader, not a dial.** The ring and the 60 index ticks are decorative. Nothing rotates. The cartridge enters through the front slot and sits under the dish, and the ring frames the measurement spot and serves as the contact surface for the touch tier.

**4. The display window is bigger than any 1.3 in module.** 49.7 × 37.7 comes from the viewer model; a 1.3" 240×240 panel has a ~23 mm active area. `models/print/display_bezel.stl` masks the window down to the screen and is the one printed part fitted to a component this specification does not pin down, **measure the module you bought** and set `SCREEN_W`, `SCREEN_H` and `SCREEN_OFFSET_Y` at the top of `tools/gen_printables.py` before printing it. Those three place the aperture. The four posts it screws to are a separate number, on a fixed 25 × 30 mm grid in `DISPLAY_POST` at the top of `tools/gen_enclosure.py`; a board drilled to a different grid needs that moved and both files regenerated. The module hangs below the deck on the four Ø4 posts, M2 self-tappers into their Ø1.8 pilots; the bezel drops into the window from outside, flush with the deck, counterbored over those screw heads.

### Print settings

| Part | Material | Layer | Perimeters | Infill | Special |
|---|---|---|---|---|---|
| Shells | PETG black | 0.16 | 4 | 25% | Part line down, no supports |
| Optical chamber | PETG black | 0.12 | 6 | 40% | Paint interior matte black |
| Aperture tube | PETG black | 0.12 | 4 | 100% | Paint interior matte black |
| Cartridge | PETG **white** | 0.15 | 3 | 100% | **Ironing ON**, only the white patch surface matters |
| Display bezel | PETG black | 0.12 | 4 | 100% | Front face down. Fitted to your screen, see below |
| Slot baffle | PETG black | 0.16 | 4 | 40% | Flat on its largest face |
| Bay blank | PETG black | 0.16 | 4 | 40% | Lip down. Fit AFTER provisioning, then seal |
| Window jig | any | 0.2 | 3 | 20% | Cutting template, not a device part |

`tools/gen_printables.py` emits every part in this table, the shells included, already at these settings, see `models/print/MANIFEST.md`, which is generated alongside the STLs and carries orientation, quantities and every derived dimension. `PRINTING.md` is the runbook: plate order, what to check off each part, and the post-processing that is not optional.

PETG, not PLA, PLA creeps under screw preload and softens in a hot car. The accent elements (seam, ring, bezel, ticks) are a second filament or a paint fill; the model separates them as distinct objects with their own materials, so a multi-material printer can take them straight. Oxblood is the default and the one every drawing here shows, but the accent is a choice: `PRINTING.md` section 2b lists the five supported finishes with their hex values, and `viewer/model.js`'s `FINISHES` table is the same set, previewable at `cell.wei.is/?finish=bone`. No geometry changes with the finish, so the STLs and the manifest do not either.

**Note:** `models/instrument.mtl` is exported alongside the OBJ by `tools/export_model.py` and carries the viewer's own colours. Material names also ride on the objects themselves (`shell`, `oxblood`, `trim_oxblood`, `glass`, `pad`, `etch_floor`, `steel`, `cavity`, `cavity_bore`, `screen`, `silkscreen`, `silkscreen_mark`), so you can substitute your own filament colours without losing the separation.

---

## 11. Wiring

Everything on I²C1 at **100 kHz** plus SPI0 for the display. BCM numbering.

**Leave the bus at 100 kHz. This is the ATECC608B's constraint, not the AS7341's.**
The chip sleeps between commands and is woken by holding SDA low for ≥60 µs,
which `cryptoauthlib` does by writing `0x00` at the bus speed. That byte is low
for ~90 µs at 100 kHz and only ~2.5 µs at 400 kHz, so at 400 kHz the part never
wakes and every call returns a timeout that reads exactly like a chip you have
mis-soldered. The Linux `i2c-dev` API cannot drop the speed for a single
transfer, so the bus rate is the fix. `raspi-config` leaves `i2c_arm_baudrate`
at 100 kHz. The correct value here is the default, so simply do not raise it.

The AS7341 has room for this: touch mode's 20 ms budget per PPG sample spends
~5.6 ms integrating (§4) and ~2 ms on the register reads at 100 kHz. If gate T0
still reports a rate below `fs_min` on your build, give the ATECC its own
`dtoverlay=i2c-gpio` bus and put the AS7341 back on hardware I²C1 at 400 kHz —
do not raise the shared bus and hope.

`diagrams/wiring.svg` draws the Phase 1 half of this table. The reader, which is what you build first. It is generated from the table below by `tools/gen_wiring.py`, so the sheet you solder from cannot drift from the spec. Change the table, re-run the generator, commit both.

| Pin | Function |
|---|---|
| GPIO2/3 | I²C1, AS7341 (0x39), ATECC608B (0x60) |
| GPIO5, 13, 19 | UP / DOWN / BACK |
| **GPIO26** | **CONFIRM**, dedicated, RC-debounced (10 kΩ + 100 nF), shares no bus |
| GPIO8–11 | SPI0 → display |
| GPIO25 / 27 / 24 | Display D/C, RESET, backlight |
| GPIO12 | White LED #2 gate (2N7002 low-side, 68 Ω to **+5 V**) |
| GPIO6 | Laser gate (2N7002), interlocked to the cartridge switch |
| GPIO23 | 940 nm IR LED gate (2N7002 low-side, 47 Ω to **+3V3**) |
| GPIO22 | Cartridge-present microswitch, **pole 1**, internal pull-up, LOW when seated. Pole 2 carries the laser supply |
| CSI | Camera |

**Two common first-build failures:**

1. **Both I²C breakouts ship with pull-ups fitted.** Remove one pair (2.2 kΩ) or the bus may not enumerate. This is the #1 first-build failure.
2. **CONFIRM is on its own pin for a reason.** An attacker who owns the SPI bus still can't assert it.

3. **The two LED rails are not the same rail**, and this is derived from the
   resistor values rather than stated anywhere, so check it against the parts you
   actually bought. 68 Ω suits a white LED (Vf ≈ 3.1 V) on +5 V, giving ~28 mA; on
   +3V3 the same resistor yields ~3 mA and the LED barely lights. 47 Ω suits the
   940 nm LED (Vf ≈ 1.35 V) on +3V3, giving ~41 mA; on +5 V it passes ~78 mA and
   cooks a 5 mm part. Only one assignment makes both values sensible, which is why
   the table reads the way it does. The rule, if your LEDs differ: size R for
   ~20–30 mA at your Vf, then pick the rail that value implies. The MOSFETs switch
   the low side either way, so 3V3 gate drive is fine for both.

4. **The cartridge switch needs two poles, and an SPDT has one.** It is asked
   to do two things at once: pull GPIO22 down when a cartridge is seated, and
   carry the laser's supply so an open bay cannot be lit. Both want a contact
   that closes on seating, and on a single-pole switch that is the same
   contact. Tie them together and the diode's rail lands on a 3V3 input the
   moment the bay opens. So: pole 1 to GND and GPIO22, pole 2 in series with
   the laser module's V+, one lever, one actuation, no shared node.

5. **A USB-C breakout with no CC pulldowns delivers nothing.** A compliant source
   reads the absent 5.1 kΩ on CC1/CC2 as "nothing plugged in" and never turns on.
   Most power-only breakouts fit them; some do not. Measure CC1–GND before you
   conclude the Pi is dead. Budget 5 V at 2 A: the Zero 2 W peaks near 0.5 A, and a
   blood run has the webcam, laser and LEDs live at once.

### Optional: the USB-C data variant

**The build above has no USB data path, and that is the shipped device.** This
subsection is how to give one up deliberately. Read §16 before you do.

What it buys is a wire: a PSBT moves without anybody aiming a camera, and
without the size limit a 240 × 240 panel puts on a transfer.

**It is not HWI, and that is worth being straight about.** Bitcoin Core,
Sparrow and Specter drive a hardware wallet through a driver inside the `hwi`
package, and adding one is a change to that package rather than to this
repository. What ships here is the layer underneath: `tools/companion.py` is
the host end of the wire, and the loop is coordinator → PSBT file → companion
→ device screen and gate → signed PSBT file → coordinator. `VALIDATION.md`
carries the HWI driver as not built.

**Wiring.** One change, and no new opening — the shell already carries a
9.0 × 3.2 mm USB-C cutout on the right face:

| | Camera build | Data variant |
|---|---|---|
| USB-C breakout | Power only, D+/D− desoldered | **Data-capable**, D+/D− carried through |
| USB-C D+/D− | — | To the Pi's **OTG** micro-USB pads (the port marked `USB`, not `PWR IN`) |
| USB-C 5 V/GND | Pi 5 V/GND pads | Pi 5 V/GND pads, unchanged |
| QR webcam | USB OTG port, via the adapter | **Removed** |
| micro-USB OTG adapter | Fitted | **Removed** |

The webcam comes off because it has to. The Pi Zero 2 W has one data-capable
USB port, a `dwc2` controller cannot be host and peripheral at the same time,
and the webcam is what currently occupies it. So the variant is **$10 cheaper**
than the bill of materials: the webcam and its adapter come off and nothing is
added. `BOM.csv` describes the camera build and is not changed by this.

**Firmware.**

```ini
# /boot/firmware/config.txt
dtoverlay=dwc2
```
```
# /etc/modules
dwc2
libcomposite
```

Bring the gadget up as CDC-ACM with libcomposite; it presents `/dev/ttyGS0`.
`firmware/link.py` reads and writes one framed message per line on it and
hands the bytes to the same `app.classify` the camera path feeds. The
confirmation screen, the PIN and the gate are untouched.

**From the host**, where the device appears as `/dev/ttyACM0`:

```bash
python3 tools/companion.py send --port /dev/ttyACM0 \
    --in unsigned.psbt --out signed.psbt
```

It sends, then waits while you read the screen, type the PIN and pass the
gate. It verifies nothing on purpose: it runs on the machine the device is
airgapped *from*, so it is a pipe, and every judgement about what was signed
belongs on the device in front of you. Both ends import the framing from
`firmware/link.py`, so there is one definition of it rather than two that can
drift.

**Check the power budget on your build.** §11 asks for 5 V at 2 A because a
blood run has the webcam, laser and LEDs live at once. Drawing power from a
host over the same USB-C cable means a laptop USB-A port at 0.9 A will not do
it. Removing the webcam recovers some of that; measure it rather than assume,
and keep a mains supply for blood runs if it comes out short.

### Radio removal, non-negotiable

```ini
# /boot/firmware/config.txt
dtoverlay=disable-wifi
dtoverlay=disable-bt
```
```
# /etc/modprobe.d/blacklist-radio.conf
blacklist brcmfmac
blacklist brcmutil
blacklist hci_uart
blacklist btbcm
blacklist bluetooth
```

Then **cut the antenna feed trace** at the board edge with a scalpel. Firmware disabling is reversible by anyone who touches the SD card; a cut trace is not.

Verify: `iw dev` empty, `hciconfig` empty. Desolder USB D+/D− or use a data-blocker, power only.

---

## 12. Firmware

### From a blank SD card to a running device

Do this on the bench, with the case open, before the seed exists. Every step
has a check, because a step that silently half-worked is worse than one that
failed.

**1. Flash the card.** Raspberry Pi Imager, *Raspberry Pi OS Lite (64-bit)*.
In the gear menu set a hostname, enable SSH with a password, set a user, and
**do not configure wifi**. You will remove networking entirely later; you only
need it long enough to install packages.

**2. Enable the buses.** `sudo raspi-config` → Interface Options → enable
**I2C**, **SPI** and **Legacy Camera**/**Camera** as your image offers. Reboot.

```bash
ls /dev/i2c-1 /dev/spidev0.0        # both must exist
i2cdetect -y 1                      # 0x39 AS7341, 0x60 ATECC608B once wired
```

**3. Install what the firmware needs.**

```bash
sudo apt update && sudo apt install -y python3-numpy python3-scipy \
     python3-cryptography python3-opencv python3-gpiozero python3-pil \
     i2c-tools git
sudo pip3 install --break-system-packages cryptoauthlib qrcode \
     adafruit-circuitpython-as7341 adafruit-circuitpython-rgb-display
```

`picamera2` ships with Raspberry Pi OS. Nothing else is needed: the signing
stack has no third-party dependency.

**4. Put the firmware on the device and prove it runs there.**

```bash
git clone <your fork> ~/cell && cd ~/cell
python3 firmware/run_tests.py
```

All suites must pass **on the Pi**, not only on your laptop. This takes a few
minutes on a Zero 2 W. It is the cheapest possible check that the card, the
Python and the install are sound, and it runs before any key exists.

**5. Check the hardware answers.** With the sensor head and the gate chip
wired per §11, run the bench checks. Each takes about a minute and each
settles something no amount of testing on a laptop can:

```bash
tools/bench.py display                      # is the panel's origin the driver's?
tools/bench.py buttons                      # do your switches settle in 30 ms?
tools/bench.py atecc --i-can-wipe-this-chip # does the PIN counter actually gate the key?
tools/bench.py thermal --load 4             # what a sealed case does over a 10 min run
```

The ATECC608B check wipes the chip, which is the point: a counter that
survives being tested was never tested. Run it before there is a seed to lose,
and re-provision afterwards. If "the wrapping key CANNOT be derived without a
PIN" fails, stop, slot 0 is not bound to the PIN slot, the attempt counter is
decoration, and an eight-digit PIN is a hundred million offline guesses
against the encrypted seed, with nothing debited for any of them.

Then:

```bash
python3 firmware/se_atecc.py --probe     # after the zones are locked
python3 firmware/app.py --dir /boot/cell --console
```

The console runner drives the real loop against stub hardware, so you can walk
the screens before trusting the panel.

**6. Calibrate.** §13, in full. Do not skip to provisioning, the thresholds
the device ships with are physics-derived starting points, not your optics.

**7. Provision.** §12, *Provisioning*, below. Write the words on paper, and do
the restore drill in the build order before you fund anything.

**8. Harden, then seal.** §11's radio removal and antenna cut, the read-only
rootfs, `cell.service`, and only then the tamper seal. In that order: a sealed
case you have to reopen because a package was missing is a seal that no longer
means anything.

### Wallet layer

The signing stack is in `firmware/`, not delegated. That was a reversal: the earlier plan was to fork [SeedSigner](https://github.com/SeedSigner/seedsigner) and add a gate to it, on the reasoning that writing your own PSBT parser is how you lose money to a change-address bug. That reasoning is still correct, and it is exactly why the parser here is written the way it is, but the gate turned out not to be separable. The tier decision needs the amount. The confirmation screen needs the change ownership. The attestation binds to the sighash. All three want the transaction already parsed, and a signer that hands those out through a plugin boundary is a signer whose security properties live on both sides of that boundary.

So the stack is here, and the mitigation for writing it ourselves is that none of it is trusted on its own authority:

| Module | Checked against |
|---|---|
| `secp256k1.py` | RFC 6979 vectors, BIP-340 vectors, OpenSSL for ECDSA verification |
| `bip39.py` | The official Trezor vectors; the wordlist's SHA-256 is verified on load |
| `bip32.py` | BIP-32 vectors 1, 2 and 5 |
| `addresses.py` | BIP-173 and BIP-350 valid *and* invalid vectors; EIP-55 vectors |
| `tx.py` | BIP-143 P2WPKH and P2SH-P2WPKH vectors; a real mainnet transaction |
| `eth.py` | Yellow-paper RLP vectors; EIP-1559 encoding |
| `hashes.py` | ISO RIPEMD-160 vectors; Keccak-256 vectors |

During development every signature was also compared byte for byte against `embit` (Bitcoin, all four script types) and `eth-account` (Ethereum, across six chain ids). They match exactly, including Bitcoin Core's low-R grinding convention, which is why our DER encodings are the same length as everyone else's. Neither package is a dependency; the vectors they confirmed are in the suites.

SeedSigner remains the reference worth reading for the parts this repo does not solve: the ST7789 UI, camera handling, and the hardened read-only image build.

### What the device recomputes rather than believes

A PSBT is a document written by software the device does not trust. `firmware/psbt.py` treats every number in it as an assertion until it is rederived:

- **Input amounts.** A segwit v0 signature commits to its own input's amount and not the others', so a host that understates one turns the difference into fee. Every non-taproot input must carry its full parent transaction, whose txid is recomputed and compared to the outpoint. Taproot commits to every amount at once, so there, and only there. A witness UTXO alone is enough.
- **Which output is change.** The host labels an output as change by attaching a derivation path. The device derives the key at that path from its own seed, rebuilds the scriptPubKey, and compares it byte for byte. An output that fails is shown as an unverified destination, in full, with a warning, never folded into "change".
- **The script type**, read from the scriptPubKey itself, because it selects the sighash algorithm.
- **The sighash flag.** SIGHASH_ALL only. Every other flag lets someone change part of the transaction after the owner approved it.

`firmware/test_wallet.py` runs each of these as an attack and requires a refusal.

### Multisig has to be registered first

The device refuses a multisig input belonging to a quorum it has not been told about, and will not call a multisig output change unless the whole quorum rebuilds it. Register the co-signers once, on every device in the quorum:

```bash
python3 tools/provision.py show --dir /boot/cell        # your line, to send out
python3 tools/provision.py multisig --dir /boot/cell \
    --label family --threshold 2 --cosigners cosigners.txt
```

The file is one co-signer per line, `label fingerprint path xpub`, and it must include this device. BIP-48 paths (`m/48'/coin'/account'/2'` native, `.../1'` p2sh-wrapped) are derived at provisioning whether or not you ever use them, so getting your own xpub does not mean re-opening a sealed case.

**Why the ceremony.** Without the co-signers on file, the only question the device can answer is "does this script contain a key of mine?". A coordinator under an attacker's control can build a script holding exactly one key of yours and n-1 of theirs: it hashes correctly, the wallet calls it change, and the balance moves to an address you cannot spend without them. With the quorum registered the question becomes "does this equal the script my co-signers produce at the path it claims?", which is arithmetic. BIP-67 key ordering is recorded rather than guessed, because the wrong choice produces a different address instead of an error.

### EVM chains have to be registered too

The device ships knowing Ethereum, Base, Robinhood and Sepolia. Those four are
built in because the account contracts in "The smart-account path" above are
deployed on them at the addresses quoted there, so a builder registering a
smart account has a chain already named for it and never types a chain id to
get started. All four denominate in ETH, which is the only reason a ticker can
be asserted rather than asked for.

Every other chain id is refused until you register it, with the name and the
native-token ticker it should be displayed under. The same deployment also
lives on Arbitrum, OP Mainnet, MegaETH and Base Sepolia, and those are
deliberately left to the owner:

```bash
python3 tools/provision.py chain --dir /boot/cell \
    --id 42161 --name "Arbitrum One" --ticker ETH
python3 tools/provision.py chain --dir /boot/cell \
    --id 137 --name "Polygon" --ticker POL
```

### And ERC-20 tokens

Nothing ships pre-registered. `0xA0b8…eB48` is USDC on Ethereum because Circle
says so, not because this project can derive it, so every token is your own
claim:

```bash
python3 tools/provision.py token --dir /boot/cell \
    --chain-id 1 --address 0xA0b86991c6218b36c1d19D4a2e9Eb0cE3606eB48 \
    --symbol USDC --decimals 6
```

The chain has to be registered first. Both fields fail silently and they fail
differently: a wrong **symbol** shows you the name of a token you do not hold,
and a wrong **decimals** moves the decimal point. At 6 where the contract uses
18, a request for a millionth of a token renders as one whole token and you
approve a screen that is off by a factor of a trillion.

So read both off a block explorer's own page for that contract, and read back
the confirmation the command prints. `provision.py show` lists what is
registered, with the contract checksummed the way the screen shows it.

The confirmation screen names both addresses in full, because an ERC-20
transfer is addressed to the *contract* and carries the *recipient* in its
calldata — one address on a screen is the wrong one, and two unlabelled
addresses are worse:

```
SEND USDC ON ETHEREUM
  amount   250 USDC
  to
           0xd8dA6BF26964aF9D7eEd9e03E53415D37aA96045
  USDC contract
           0xA0b86991c6218b36c1d19D4a2e9Eb0cE3606eB48
  max fee  0.00195 ETH
  chain id 1
  nonce    3
```

Check the contract, not just the symbol. Nothing about "250 USDC" on a screen
distinguishes real USDC from a contract somebody deployed yesterday; the
address does, and it is there for that.

**On tiers.** `Policy.blood_above` is denominated in the chain's smallest unit
— wei — and a token amount is not that. 250 USDC is 250000000 units, which
compares *below* one ether's 10¹⁸ wei, so pricing a token transfer on its own
number would let a large stablecoin move slip under a floor meant to catch it.
The device holds no oracle and does not guess: any positive token amount
prices above every floor an owner can set. With `blood_above` unset — the
default, meaning amount-based escalation is off — a token transfer runs at
touch tier exactly as a thousand-ether transfer does. Put `tx.token` in the
policy's `blood_locked` set if you want it gated regardless.

**Why this is not just a shorter list.** The signature commits to the chain id,
but nobody reads a chain id. The name and the ticker are what the owner
actually reads to know which network and which denomination they are approving.
If those two strings could arrive with the transaction, an attacker who labels
chain 1 "Sepolia (test)" collects a blood-gated signature on real money from an
owner who believed it was play money. Registering them yourself makes the label
your own claim, exactly as registering a quorum makes the script your own claim.

So check the chain id against a source you trust before you type it, and read
back the confirmation the command prints. Nothing downstream can catch a
registration that names the wrong network. It is wrong on every transaction
you will ever approve on that chain.

Registrations are refused if they would rename a chain already registered, or
relabel one of the four built in. Names are capped at 24 characters and tickers
at 8, both printable ASCII only: a name carrying a direction override or a
zero-width joiner renders as something other than what was registered.

### And names, if your payees have them

A `.wei`, `.gwei` or `.eth` name is a claim held by a contract on Ethereum
mainnet. The device has no network and can never read it, so a name reaches the
screen the same way a token symbol does — you resolve it, you check it, you
register it:

```bash
export CELL_RPC=https://your-node
python3 tools/ethnames.py resolve alice.wei --chain 8453
python3 tools/provision.py name --dir /boot/cell --name alice.wei \
    --rpc $CELL_RPC --address 0xd8dA6BF26964aF9D7eEd9e03E53415D37aA96045
```

Give `--rpc` and `--address` together and they are checked against each other,
which is the only check here that does not rest on a single source. An RPC that
lies about where `alice.wei` points redirects every payment you ever make to
that name, and nothing downstream of this command would catch it. Read the
address off the name's own page — `wei.domains`, `gwei.domains`,
`app.ens.domains` — and paste it in as `--address`.

Registered, the name goes *above* the address on every screen that pays it:

```
SEND ON ETHEREUM
  amount   0.1 ETH
  to  alice.wei
           0xd8dA6BF26964aF9D7eEd9e03E53
           415D37aA96045
  max fee  0.001 ETH
  chain id 1
  nonce    3
  MOST     0.101 ETH
```

The address is still there, still in full, and still what the signature commits
to. The name is a recognition aid for the second and every later payment to a
payee you already checked once. It is not the thing being confirmed.

**Three systems, in one order.** WNS (`.wei`), GNS (`.gwei`) and ENS
(everything else dotted) all hash a name the same way — EIP-137 — and all three
answer through the same SLIP-44 coin types, so one module reads all three. The
suffix decides which, longest match first, and `.eth` is reserved to ENS. A
bare label like `alice` is a name in both WNS and GNS pointing at two different
people, so it is refused: register the name in full. Where you have registered
several names for one address, the screen draws WNS first, then GNS, then ENS —
this project co-developed WNS, so that order is an admitted bias. It changes
which of your own labels appears and nothing else.

**One name, several chains, and Bitcoin.** A name is an Ethereum mainnet
record, but the address underneath it need not be an Ethereum one:

| What the name publishes | Coin type | What the device does with it |
|---|---|---|
| its default address | 60 | drawn on every EVM chain that has no entry below |
| a per-chain address | ENSIP-11, `0x80000000 \| chain_id` | drawn on that chain, *instead of* the default |
| a Bitcoin address | 0 | drawn on Bitcoin spends |

The per-chain row is the one that matters. A name can be an EOA on Ethereum and
a contract on Base, and the same twenty bytes on two chains can belong to two
people — so where a name publishes an override, the default address is *wrong*
there, and the device says so by refusing to draw the name over it. `--chain
8453` reads those at registration; `--chain-address 8453=0x…` records one you
read yourself.

The Bitcoin address is a separate record the name publishes, never derived from
the EVM one. Nothing derives one from the other, and a device that pretended
otherwise would be inventing an address nobody controls.

**Why registration, and not resolution on the device.** The same reason chains
and tokens are registered. An attacker who can put "vitalik.eth" above `0xBAD`
on the confirmation screen does not have to beat a gate: you read a name you
recognise and press CONFIRM on somebody else's address. So no operation this
device parses has a field that can carry a name — `firmware/names.py` checks
that against the parser on every run — and the only names it will draw are the
ones you registered yourself.

`provision.py show` lists them. `tools/ethnames.py reverse 0x…` goes the other
way and forward-verifies before it answers: a primary name is a string its own
subject wrote, so it is resolved back to the address that claimed it before the
tool will repeat it.

### Proving it against a node

`tools/regtest_e2e.py` runs the whole thing against Bitcoin Core on a private regtest chain: Core funds an address the firmware derived, the firmware signs a PSBT spending it, and Core finalises, accepts and mines the result. Every script type, taproot and 2-of-3 included.

```bash
tools/regtest_e2e.py --bitcoin-dir /path/to/bitcoin-28.0/bin
```

It starts a private regtest node, runs every script type through it, and stops
the node again. Pass `--datadir` to keep the chain around, or `--no-start` to
drive one you started yourself.

Worth doing before you fund anything, and worth doing again after any change to `psbt.py`, `tx.py` or `addresses.py`. It is the only check in this repo that answers on its own authority rather than by comparison, and it earned its place the first time it ran by finding a malformed BIP-174 proprietary key that made every PSBT this device produced unreadable to Core.

### Both QR framings

Transfers arrive and leave in one of two encodings, and the device accepts
either without being told which:

| | |
|---|---|
| `pNofM` | `p1of4 cHNidP8B…`. The Specter convention, and what this device shipped with. Fixed rate: the receiver needs every index |
| UR 2.0 | `ur:crypto-psbt/1-9/lpadascf…`. BCR-2020-005, what Sparrow and the Keystone-compatible coordinators reach for first. Rateless: past the first pass the sender emits XOR mixtures of fragments, and any sufficient subset reconstructs |

The difference matters on this hardware. A `pNofM` loop repeats the same
frames, so a reader that keeps missing frame four never finishes, however long
it loops. A UR loop's second pass is not a repeat, and a permanently missed
frame is recovered from a mixture of others. On a $8 webcam and a Pi Zero
that is the difference between a transfer that converges and one that stalls.

**The device replies in the framing it was asked in.** A coordinator that can
talk to this device cannot then fail to read its answer, and neither encoding
is a default the other has to catch up with.

### Handing the coordinator your accounts

The THIS DEVICE screen prints the extended public keys so somebody can type
them into a coordinator. That transcription is where a character gets dropped,
and a wallet built on a wrong xpub watches addresses nobody can spend from and
shows the owner a receive address that is not theirs.

So the same screen offers to emit them instead: **CONFIRM** exports every
Bitcoin account as one `ur:crypto-account`, and a coordinator scans it and has
all four script types at once. It signs nothing, it needs no PIN and no seed,
and it is built from the recorded xpubs like the receive screen is.

It is behind a second confirmation with a warning on it, because an account
xpub reveals **every address that wallet will ever use, forever**, to whoever
reads it. A coordinator on your own machine is the ordinary case; a phone
camera over somebody's shoulder is not, and you are the only one in a position
to tell which room you are in.

The Ethereum account is not in the export — Ethereum has no output script —
and neither are the multisig accounts, because a quorum descriptor needs your
co-signers' keys and this device holds only its own share. `provision.py show`
prints the multisig descriptor for those.

`firmware/ur.py` builds it against BCR-2020-007, -010 and -015 on the legacy
tag numbers (303, 308, 311) rather than the renumbered `ur:hdkey` range,
because the point of an export is that a coordinator somebody already has can
read it. All four descriptors are checked as substrings of BCR-2020-015's own
published vector, from its own test seed.
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

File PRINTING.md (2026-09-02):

# Printing CELL

Everything printable comes out of one command. This file is the order to print
in, what to check before moving on, and the post-processing the device does not
work without. Dimensions live in
[`models/print/MANIFEST.md`](models/print/MANIFEST.md), generated from the same
constants as the STLs. If this file and the manifest disagree about a number,
the manifest is right.

## 0. Generate the parts

```bash
python3 tools/gen_printables.py     # -> models/print/*.stl + MANIFEST.md
```

The STLs are committed, so you can slice them straight from a clone and skip
this. Run it if you have changed anything, and always after editing a constant.
The generator validates every mesh, runs the fit checks, and exits non-zero
instead of handing your slicer something it would have to guess at. CI runs the
same command and fails if the committed STLs are not what it produces.

Eleven parts. Nothing needs supports.

## 1. What you need

| | |
|---|---|
| Printer | Anything with a 130 × 90 mm bed that can hold PETG temperatures |
| Temperatures | 240 °C nozzle, 80 °C bed. Fix on one pair and hold it for the whole cartridge batch |
| Black PETG | ~90 g. Shells, optics, bezel, bay blank |
| White PETG | ~60 g. Cartridges. A *different spool*, not "light grey" |
| Matte black paint | Acrylic or model paint, for the optical bores |
| M2.5 heat-set inserts | 6, Ø3.5 knurled OD, plus a soldering iron with an insert tip |
| M2.5 × 16 screws | 6. They enter from the base and thread into the inserts in the upper shell |

**PETG, not PLA.** PLA creeps under screw preload and softens in a hot car. The
bosses lose their grip and the optical chamber stops being light-tight.

**Dry the white spool before the batch.** Four hours at 65 °C. PETG is
hygroscopic, and wet PETG's signature failure is a hazy, stringy top surface —
which is the surface every reading in this device is normalised against. A
builder who fails the Stage 1 check below and goes hunting through flow and
temperature will not find it there.

**The white spool is a measuring instrument.** Every cartridge carries the white
reference patch that every reading is normalised against. Print the whole batch
from one spool in one session. Switching filament mid-batch walks your
thresholds without telling you.

## 2. Print order

Each stage tells you something about the next one, and the first stage is cheap.

### Stage 1: one cartridge

Print a single `cartridge.stl` before anything else. It is the smallest part and
the most demanding. The white patch and the well floor must both come out as
clean ironed top surfaces.

**Check before continuing:** the patch is smooth and matte, with no gaps between
ironed lines. Hold it to the light at an angle. If it is ridged, or
glossy-then-dull in patches, fix your ironing now: flow, speed, and top-layer
temperature. Every gate in the device is normalised against this surface.

### Stage 2: the cartridge batch

Plate them, plus one `cartridge_reference.stl` and one
`cartridge_null.stl`. Twenty-two at 51 × 14 mm is three plates on a
130 × 90 bed, so run the plates back to back on the one spool. That is [BUILD.md §15](BUILD.md) milestone 3. It is a
measurement and not a stockpile: read the white patch on all 20 and require
**under 3% spread after normalisation**. Cartridges that do not agree with each
other will not agree with themselves next month. Fix the printer here.

The REFERENCE and NULL bodies must come off the same spool in the same session
as the batch they are the reference for.

### Stage 3: the optics

`optical_head.stl`, `aperture_tube.stl`, `slot_baffle.stl`. Black PETG, fine
layers, and the orientations in the manifest: open face down for the head,
flange down for the tube.

These three are the light-tight chamber. They are also the parts where "looks
fine" and "works" are different things. See post-processing below.

### Stage 4: the shells

`shell_lower.stl` and `shell_upper.stl`, part line down, seam at a corner. These
two are most of the filament and most of the hours. Babysit the first layer,
and on smooth PEI or glass put a glue-stick layer down first — PETG bonds to a
bare sheet hard enough to take a piece of it away with the part. Keep part
cooling low: the shells carry the screw preload PETG was chosen for, and fan
speed is what costs you layer adhesion.

**Check before continuing:** the tongue on the lower shell enters the groove in
the upper without forcing, and the two close with no visible gap at the part
line. There is 0.15 mm of clearance designed in, on the sides as well as over
the top, with a 0.4 mm lead-in on the tongue so the joint starts itself. If it is tight, your printer is
running wide and the cartridge slot will be tight too.

### Stage 5: the bezel, last

`display_bezel.stl`, once the display module is physically in your hand.

**This is the only part fitted to hardware the specification does not pin
down.** BUILD.md buys "an ST7789 1.3 in 240×240". Those boards differ between
vendors in where the active area sits on the PCB and where the mounting holes
are. Measure yours, set `SCREEN_W`, `SCREEN_H` and `SCREEN_OFFSET_Y` at the top
of `tools/gen_printables.py`, and regenerate. If the mounting holes miss the
four posts, move `DISPLAY_POST` in `tools/gen_enclosure.py` and regenerate both.
The posts are derived, not specified.

`check_bezel_geometry()` refuses anything that cannot fit or cannot print, so a
wrong number is a failed run instead of a wasted print.

### Also: the window jig

`window_jig.stl`, any filament, whenever. It is a cutting template for the PET
windows and no part of the instrument.

### And last of all: the bay blank

`bay_blank.stl`, black PETG, lip down so the 1.6 mm lip is not a ledge printed
into mid-air. It closes the rear compute bay, and it goes on **after
provisioning** — the bay is how you reach the Pi and its microSD during a
build. Fit it, then seal it.

## 2b. Choosing a finish

The accent is the only part of this instrument you are meant to choose. It is
carried by four features: the parting seam, the raised ring around the sensor
port, the CONFIRM collar and display bezel, and the 60 index ticks. On a
printed device it is a second filament or a paint fill, not a coating. Nothing
structural changes. The STLs are identical whichever you pick, so this is a
spool decision made at Stage 4 and not a geometry decision made at Stage 0.

| Finish | Accent | Ring / trim | Gloss | Reads as |
|---|---|---|---|---|
| `oxblood` **(default)** | deep red | `#55161d` / `#5f151d` | high | The shipped instrument. Every drawing and render in this repository is this one |
| `deep` | near-black maroon | `#2e1013` / `#3a141a` | low | The same colour held back. Red only resolves at a grazing angle |
| `bone` | warm off-white | `#8e877a` / `#9a9284` | low | Ossuary. The etched dish carries the character on its own |
| `brass` | dark antique brass | `#6b5220` / `#7a5f2a` | high | Alchemical instrument rather than ritual object |
| `nickel` | brushed nickel | `#6f6a63` / `#7d776f` | high | Utility. The only colour left is the etched dish |

The finish also sets the colour of the `BLOOD` word on the signing screen, so
a device reads as one object rather than a coloured case around a red display.
That word keeps its distance from the grey a `TOUCH` reading renders in,
whichever finish you pick: the difference between those two words is the
difference between a gate that took blood and one that did not, and no finish
is allowed to blur it.

**Gloss matters as much as colour.** The ring surrounds a black bore, so a
high-gloss accent catches a hard highlight and the port reads as a lit
aperture; a satin one reads as a machined bezel. If you are painting rather
than printing the accent, that is a choice between a gloss and a satin clear
coat over the same pigment.

To see one before you commit a spool, open the viewer with the finish named:
`cell.wei.is/?finish=bone`. The default is `oxblood` with no parameter, and the
parameter changes nothing that gets exported or printed. The STLs, the
drawing and the manifest are the same in every finish.

## 3. Post-processing

Four steps. The first two are load-bearing.

**Paint every optical bore matte black.** The inside of the aperture tube and
the whole interior of the optical head. Black PETG is not optically black. It
reflects enough at grazing incidence to put stray light on the sensor, and stray
light is indistinguishable from a bright sample. Thin acrylic paint, two coats,
kept out of the bore's clear path.

**Fit the six heat-set inserts.** Ø3.6 × 6 holes in the **upper** shell, M2.5
inserts, soldering iron at ~230 °C, pressed in square and flush. Skewed inserts
are the usual reason an enclosure will not close. The screws come up from the
base through the lower shell and thread into these, so the heads finish
underneath and the display face stays unbroken.

**Cut and tape the PET windows.** Use the jig: 12 × 10 mm rectangles from 0.1 mm
film, one per cartridge. Tape one long edge to the cartridge body with 3M 300LSE
so it flips up to load and down to close. **The tape is the hinge.** Handle the
film by its edges. A fingerprint on the window is a calibration error.

**Seal the pre-flight pair.** Put a known target in the REFERENCE well and close
it permanently. Leave NULL bare. Record their baselines. REFERENCE must pass the
spectral gates and fail the liveness gate, since it cannot move. NULL must fail
gate 1 on the bright side.

## 4. Before you call it printed

* [ ] 20 cartridges agree with each other within 3% after normalisation
* [ ] All optical bores are matte black inside
* [ ] Six inserts in the upper shell, square and flush, and six M2.5 × 16
  screws reaching them from the base
* [ ] Shells close on the tongue and groove with no gap at the part line
* [ ] A cartridge slides to the first detent, then past it, without forcing
* [ ] Chamber light-tight: clear channel under 0.5% of LEDs-on at 10,000 lux
* [ ] REFERENCE and NULL sealed, baselines recorded

The light-tightness test is the one people skip. Every vent in the shell is a
**blind pocket** for this reason. One vent that broke through to the interior
puts ambient light on the optical chamber and the 415 nm gate stops working.
Test it. Do not eyeball it.

## 5. Used cartridges are biohazard

A cartridge that has held blood goes in the sharps container with the lancet.
Never in household waste, never back in the slot. Read
[`SAFETY.md`](SAFETY.md) before you print the batch.

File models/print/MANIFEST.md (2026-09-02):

# Printed parts

Generated by `tools/gen_printables.py`, which builds the internal and consumable parts itself and calls `tools/gen_enclosure.py` for the two shells. Every number in this file is interpolated from the constants the STLs were generated from. Do not hand-edit either -- regenerate.

| Part | Triangles | Solid volume | Print settings |
|---|---|---|---|
| `cartridge.stl` | 2376 | 1803.4 mm3 | PETG white, 0.15 mm, 3 perim, 100%, ironing ON |
| `cartridge_reference.stl` | 2376 | 1803.4 mm3 | as cartridge; seal a known target in the well |
| `cartridge_null.stl` | 36 | 1820.6 mm3 | as cartridge; no well, leave bare |
| `aperture_tube.stl` | 1152 | 119.3 mm3 | PETG black, 0.12 mm, 4 perim, 100%, bore matte black |
| `optical_head.stl` | 89792 | 5113.5 mm3 | PETG black, 0.12 mm, 6 perim, 40%, interior matte black |
| `slot_baffle.stl` | 28884 | 993.2 mm3 | PETG black, 0.16 mm, 4 perim, 40% |
| `display_bezel.stl` | 72380 | 2462.4 mm3 | PETG black, 0.12 mm, 4 perim, 100%; masks the window to your screen |
| `bay_blank.stl` | 24 | 3950.1 mm3 | PETG black, 0.16 mm, 4 perim, 40%; fit AFTER provisioning, then seal |
| `window_jig.stl` | 21504 | 498.9 mm3 | any filament; not a device part |
| `shell_lower.stl` | 224228 | 26423.0 mm3 | PETG black, 0.16 mm, 4 perim, 25%, seam at a corner |
| `shell_upper.stl` | 264920 | 30832.9 mm3 | PETG black, 0.16 mm, 4 perim, 25%, seam at a corner |

## How many of each

One of everything, except:

* **cartridges -- print a plate of them.** They are consumed one per reading
  and they are biohazard afterwards. BUILD.md's build order asks for 20 up
  front, measured against each other, before you trust any of them.
* **`cartridge_reference` and `cartridge_null` -- one each, then seal them.**
  These are the pre-flight pair. REFERENCE takes a known target in the well
  and must pass the spectral gates while failing the liveness gate, because it
  cannot move; NULL has no well at all and must fail gate 1 on the bright
  side. Print them from the same spool, in the same session, as the batch they
  are the reference for.
* **`window_jig` -- one, and it is not part of the instrument.** It is the
  cutting template for the 12 x 10 mm PET windows.

## Two sources, one instrument

`viewer/model.js` owns the instrument's OUTSIDE: it is what the turntable
renders and what `gen_mechanical.py` measures. It is an appearance model --
solid extrusions, with the openings drawn as dark boxes rather than cut out of
anything. Slicing it gives you a brick.

`tools/gen_enclosure.py` owns the INSIDE: wall, part line, tongue and groove,
real openings, insert bosses, the rails the Pi slides in on, and the
light-tight skirt around the optical chamber.

Two parametric sources is the drift `models/README.md` warns about, so the
seam between them is checked rather than trusted. `check_envelope()` fails the
build if the assembled shells stop matching the documented envelope, and
`check_fit()` fails it if the inside stops being assemblable -- see below.

## What the fit checks cover

Watertight is not the same as buildable. Every generation run probes the ways
this instrument can be wrong without looking wrong.

The enclosure, in `gen_enclosure.check_fit()`:

* the cartridge path, across the full width and thickness of the cartridge,
  from the front face to the read spot;
* every vent, which must still have material behind it;
* the Pi bay, sampled at 1 mm through the corridor a 65 x 30 board sweeps plus
  its headroom;
* the sensor port, across the 3 mm spot the aperture tube defines;
* the part line, where no point may be solid in both shells at once.

The cartridge, in `check_cartridge_geometry()` -- the six distances the
two-stop read needs to hold at once: patch clear of the moat, patch on the
part, stop 1 ahead of stop 2, detent shorter than the slot clearance, detent
clear of the PET window, and enough grip left to pull the thing out.

The bezel, in `check_bezel_geometry()`: aperture inside the window, screw
counterbores on the plate and out of the aperture, counterbore shallower than
the plate, and frame wide enough to print flat.

A check that has never failed is a check nobody knows works, so
`tools/test_printables.py` drives the cartridge, bezel and filament guards
past their own limits and requires each one to raise; CI runs it. The
enclosure's `check_fit()` samples a distance field over the whole body and is
too slow to break repeatedly, so it runs on every generation instead. Real
conflicts found this way and fixed in the geometry: two insert bosses standing
inside the Pi's footprint, a dish recess as deep as the ceiling it was cut
into (so the dish opened straight through to the interior), vent pockets
deeper than the wall is thick, and a white patch with no optical path to it.

## Mesh accuracy

`cartridge`, `cartridge_null` and `aperture_tube` are analytic: circles are
192- and 96-gon approximations, everything else is exact.

`optical_head`, `slot_baffle`, `display_bezel` and `window_jig` are
isosurfaced at a 0.35, 0.3, 0.3 and 0.25 mm grid respectively, because their
bores enter walls at an angle and that needs real CSG. Expect edges rounded by
roughly half the grid pitch. That is under the print's own tolerance for a
clearance bore, but do not take a critical dimension off those meshes -- take
it from the constants at the top of `tools/gen_printables.py`.

**Both shells are surface-netted at 0.5 mm**, the coarsest grid in the set, on
the two parts that carry the part line, the tongue and groove and the insert
bosses. No fit feature finer than that survives into the mesh, which is worth
knowing before you judge a 0.15 mm clearance by eye.

Every part is checked before it is written: each shell closed, consistently
wound the same way, positive in volume, and in no more separate pieces than it
is entitled to. Winding is counted on directed edges, which is what makes it a
real test -- an undirected count proves only closure, and passes a mesh with a
patch turned inside out. The generator exits non-zero rather than emit a mesh
that fails any of it. Volumes in the table above are SOLID volumes: where a
part is several overlapping shells the sum is corrected for what they share,
so the cartridge's figure no longer double-counts the stop rib sunk into its
slab, and the bay blank's no longer double-counts its lip.

## Orientation

Cartridge: well-side up, on the bed, no supports. The well floor and the white
patch must both be top surfaces or ironing does nothing for them.

Aperture tube: flange down. The flange seats on the optical head's roof and
the barrel drops through the 5.4 mm bore, so the tube hangs at the standoff
rather than being glued at it. The seat is an arc, not a full ring -- the
laser arrives close enough to vertical to cut into it -- so bond the flange as
well as seating it.

Optical head: open face UP on the bed, no supports. Face down, the chamber
roof is a 39 mm unsupported span printed in mid-air, and it is the surface
that carries the aperture tube and sets the sensor standoff. Face up it is the
first layer instead: a solid disc, which is also far better adhesion than a
2.4 mm ring. Every bore is 38 deg or more off horizontal and self-supports
either way.

Slot baffle: flat on its largest face, no supports. On edge it is a 42 x 13
wall 2.0 mm thick and wants a brim.

Display bezel: front face down, no supports. The counterbores open upward and
the aperture is a through-cut, so nothing overhangs.

Bay blank: lip down. The lip is 1.6 mm larger than the plate on all four
sides, so plate-down it is an unsupported ledge appearing in mid-air.

Window jig: either face down. It is a flat plate with a through slot.

Shells: part line down -- the tongue on the lower shell and the groove in the
upper both print as top features that way, and neither needs support.

## Dimensions taken from BUILD.md

Cartridge 51 x 14 x 2.4; well 4.0 dia x 0.55; moat 7.0 dia x 0.4; patch 4 x 4;
window 12 x 10 x 0.1 PET; travel 31.6; aperture 3.0 dia x 6.0; sensor standoff
9.0; LEDs 45 deg at 12.0 mm; laser 30 deg; camera 20 mm lensless; slot 34.0 x
3.0; baffle offset 6.0.

## Derived here, not in BUILD.md -- review before printing

* **Well centre 10.5 mm from the tip**, moat outer wall at 7.0, so a 4 mm
  patch centred at 3.0 fits ahead of it. Features nearer the tip cross the
  read spot first, which is what makes the patch readable before the sample
  rather than after it.
* **Two stops, 34.6 and 42.1 mm of insertion.** Stop 1 puts the patch under
  the aperture, stop 2 puts the well there. The first is a detent ridge 0.8
  proud and 1.2 along, into 0.6 mm of slot clearance -- a tactile stop that a
  deliberate push rides over, not a lock. The second is the grip shoulder, 3.6
  thick against the 3.0 slot.
* **8.9 mm of cartridge proud of the slot** at stop 2, which is what you have
  to pull a blood-contact part back out with.
* **Beam channels through the roof**, not module bores: 3.4 for each LED, 4.9
  for the laser, 5.0 for the camera. At these angles a part 12 to 20 mm from
  the sample spot sits above a 8.2 mm block, so its body mounts on the top
  face and only its light goes through. Bored to the modules' own 5.4/6.4/8.0
  the openings ran into each other and the walls between them feathered away
  to nothing.
* **The angled channels converge**, so below the roof they are one painted
  cavity -- that is the design. Across the roof each pair is held either
  clearly apart or clearly merged, never tangent, with 0.4 mm to spare.
  `check_head_geometry()` measures it on the true elliptical section a tilted
  bore actually cuts, which is what a slanted cylinder leaves at constant
  height, and not on the circle it is tempting to assume.
* **Optical head block** 43.6 mm dia x 8.22 mm, 2.4 wall. It has to pass the
  optical chamber's Ø45.2 skirt bore and fit under a ceiling 8.52 mm above a
  seated cartridge -- NOT the Ø47.2 cosmetic recess in the top face, which is
  where the old 46 mm came from and is 0.8 mm too wide for the hole it has to
  enter. The angles and standoffs are BUILD.md's; the block carrying them is
  not.
* **Display bezel 49.4 x 37.4 x 2.0**, aperture 23.799999999999997 x
  23.799999999999997, 6.8 mm of frame and 0.90 mm of web beside a counterbore,
  with 4.4 x 1.4 counterbores over the module's screw heads. **This is the
  part fitted to hardware nobody specified** -- see below.

## The bezel is fitted to your screen, not to a standard

BUILD.md buys an "ST7789 1.3in 240x240" and the enclosure window follows the
viewer model at 49.7 x 37.7. No 1.3 in module is that big, so the window is
masked by this frame rather than left as a hole with a small screen rattling
behind it.

The defaults are for an Adafruit 4313-class breakout. Boards from other
vendors put the active area somewhere else on the PCB, and the four posts in
the shell are on a 25 x 30 mm grid that not every board matches. **Measure the
module in your hand**, set `SCREEN_W`, `SCREEN_H` and `SCREEN_OFFSET_Y` at the
top of `tools/gen_printables.py`, and regenerate. `check_bezel_geometry()`
will refuse anything that cannot be printed or cannot fit. If your board's
mounting holes do not land on the post grid, move `DISPLAY_POST` in
`tools/gen_enclosure.py` and regenerate both -- the posts are derived, not
specified.

Print the bezel last, once the screen is in front of you.

## Derived for the enclosure -- review before printing

BUILD.md section 10 dimensions the outside. Everything structural is
`tools/gen_enclosure.py`'s invention, and all of it is a constant at the top
of that file:

* **2.4 wall, 2.0 floor and 2.0 ceiling**; a 1.2 x 2.0 tongue on the lower
  shell into a groove in the upper, 0.15 clearance on the sides as well as
  over the top, with a 0.4 lead-in so the joint starts itself.
* **6 M2.5 fasteners, entering from the BASE.** The insert lives in the UPPER
  shell -- a Ø3.6 x 6 hole in a pillar hanging from the deck underside to the
  part line -- and the screw passes through a Ø6 column in the lower shell on
  a Ø2.8 clearance, its head sunk 2.4 into the base. That is the only
  direction that works: the insert has to be in the half the screw does not
  pass through, and a screw entering the deck would span the whole interior
  and put 6 heads on the display face. M2.5 x 16, and `check_fit()` proves the
  length reaches. The 2 front-face features are blind Ø4 x 1.2 pockets and
  take no fastener: the pocket and anything that could be threaded behind it
  are both in the lower shell, so there is nothing there for a screw to clamp.
* **Pi rails at 7.1**, a 1.8 slot 30 mm deep, entered through the rear bay.
  The board cannot sit on the cartridge plane at 14.9 -- that is inside the
  optical chamber -- so it lives under the skirt with 4.8 mm of headroom above
  the board's top face. The groove is narrower than the rail and biased
  outboard, so the lip reaches 1.2 mm over the board's edge; cut the full
  width of the rail, it reached nothing and the board fell out.
* **Optical chamber skirt**, Ø50 x 2.4 wall, hanging 11 mm off the deck
  underside, slotted where the cartridge crosses it.
* **Vents cut 1.6 deep, not 3.0.** Section 10's figure was safe in a solid
  body and is 0.6 mm past the inside face of a 2.4 mm wall. Blind is the
  point: one through-hole and the 415 nm gate stops working.
* **Display ledge and four posts**, Ø4 with a Ø1.8 pilot, masked by the bezel
  above.

## Filament

About 57 cm3 of black PETG for the two shells and 13 cm3 for the optical parts
and bezel -- near enough 89 g, against the 90 g the BOM budgets. A cartridge
is 1.8 cm3, or 2.3 g, so the 20 of them the build order wants plus the 2
pre-flight bodies is 50 g of the 60 g white spool.

`check_filament_budget()` compares both figures against `BOM.csv` on every
run, so a heavier part cannot quietly outgrow the spool the BOM buys.

Those are solid volumes. Real filament use runs under them wherever infill is
below 100% -- the shells are the bulk of it and print at 25% -- so treat the
figure as the ceiling, not the estimate.

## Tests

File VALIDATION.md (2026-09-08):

# Verification status

What has been verified, by what method, and what is scheduled for first build.
This is the engineering status record, `README.md` is the product description
and `BUILD.md` is the specification.

Instruments are calibrated to their hardware before use. CELL is no different:
the thresholds ship as physics-derived defaults, and `calibrate.py` replaces
them with values measured on your own optics, your own printer and your own
samples. That step is one of the build milestones in `BUILD.md` §15.

## At a glance

| Area | Status |
|---|---|
| Signing stack: curve, BIP-32/39, PSBT, sighash, addresses, RLP, EIP-712 | **Verified** against published vectors, two independent libraries, an independent script interpreter, and Bitcoin Core on regtest |
| Attestation, quorum, ring signature, proof of life | **Verified** in CI, and against a live node for the beacon period |
| Blood and touch gate logic | **Verified** against a synthetic spoof panel. Thresholds are physics-derived and want real samples |
| Enclosure, cartridge and the printed parts | **Verified** as geometry: every mesh checked, every fit checked, the drawing generated from the mesh |
| ATECC608B driver | **Arithmetic verified** against Microchip's own definitions. Nothing that touches I²C has run |
| Sensor head, display, buttons, QR camera | **Written, not run.** Each needs the part in hand |
| Gate separation on real blood | **Open.** This is the measurement the design turns on, and nobody has contributed one |
| Thermal, supply and the optical PUF as optics | **Open.** Bench checks exist and want a built device |

The sections below carry the detail: what was checked, by what method, and what each open row needs.

## Built, on video

[A prototype has been built and used to sign behind the blood
gate](https://x.com/austingriffith/status/2097231722094191031) — video,
September 2026. That build did not contribute any captures, thresholds or
panel runs, so nothing below changes because of it. A video shows the device
worked once; the rows here record measurements, and there are none from it.

The frame in `README.md` does show the chemistry sequence running in order on
real optics: laser warm-up, then G1 to G4 pending. Those are
`blood_gate.py`'s first four gates, relabelled for the display by whoever
built it. The frame is `diagrams/first-build.png`, IPFS
`bafybeihrnbc5sivwzuhjsej6aa6tasufcdygtw5aoh5dgql3zsbzm6ruqi`.

---

## Verified in CI, every commit

`python firmware/run_tests.py`, 51 suites, no hardware required.

### The signing stack

Every row here is checked against vectors published by someone else. A round
trip against our own implementation proves nothing, so none of these are that.

| Component | Method | Result |
|---|---|---|
| RIPEMD-160 | ISO reference vectors, incl. the 1 MB case | Byte-exact; also cross-checked against OpenSSL where available |
| Keccak-256 | Published vectors, plus rate-boundary lengths | Byte-exact; asserted to differ from SHA3-256, which is the mistake that silently produces wrong Ethereum addresses |
| ECDSA nonces | RFC 6979 secp256k1/SHA-256 vector | Byte-exact on both r and s |
| ECDSA signatures | OpenSSL verification of our output | Accepted; low-S and low-R enforced across 24 signatures |
| BIP-340 Schnorr | Published BIP-340 test vectors | Byte-exact match on pubkey and signature |
| BIP-341 tweaks | Private and public tweak agreement | Same output key by both routes; key-path signature verifies |
| BIP-39 | Official Trezor vectors, 12 and 24 words | Mnemonic and seed byte-exact at every length; wordlist SHA-256 verified on load |
| BIP-32 | Official vectors 1, 2 and 5 | xprv and xpub byte-exact; invalid keys refused; hardened derivation impossible from an xpub |
| bech32 / bech32m | BIP-173 and BIP-350, valid and invalid | All decode; wrong-variant checksums refused, which is the failure that burns taproot funds |
| EIP-55 | Vectors from the EIP | Byte-exact; a single flipped case is rejected |
| BIP-143 sighash | Published P2WPKH and P2SH-P2WPKH vectors | Byte-exact |
| BIP-341 sighash | Differential against an independent implementation | Byte-exact; asserted to commit to every input's amount |
| Transaction parsing | The block-170 mainnet transaction | Round trips byte for byte; txid matches the known value |
| RLP | Yellow-paper vectors | Byte-exact; negative, boolean and float inputs refused |
| EIP-1559 | Field-by-field differential | The digest changes if any of the seven signed fields changes |
| Cross-implementation | `embit` and `eth-account`, during development | Signatures byte-identical across four Bitcoin script types and six EVM chains. Neither package is a dependency |
| Two Schnorr copies | `attest.py` vs `secp256k1.py` | Pinned to agree on 8 keys, so the standalone copy in `attest.py` cannot drift |
| Attestation record | Pack/unpack round trip | 238 bytes, exact |
| Attestation rejection | 8 negative cases | Wrong transaction, replayed counter, unknown firmware, unregistered calibration, swapped gate measurements, wrong signer, forged signature, wrong tier, all refused |
| Malformed input | 6 hostile inputs | Truncated, empty, bad magic, bad version, unknown tier, all-zero. All return a verdict, none raise |
| Quorum | 3-signer roster | Missing attestation fails; touch-tier attestation fails where blood is required |
| Tier policy | 12 cases | Escalation permitted, de-escalation refused, five locked classes enforced |
| Unlock chain | 41 checks | Step order asserted against `EXPECTED_ORDER`; render before all, confirm before PIN, gate before unwrap |
| Key binding | Differential | Wrapping key is stable across captures and transactions, so the seed stays recoverable; changing the PIN or the device secret changes it |
| Liveness in the record | Differential | The attestation commits to the gate measurements; a different capture attests a different hash |
| Operation set | 5 hostile payloads | Unknown type, bare hash, unknown field, missing field, non-object, all refused |
| Display safety | Width and height limits | Destinations shown in full; anything that does not fit is refused, never truncated |
| Secure element | 12 checks | Attempt debited before compare, wipe at 10, KDF context-bound and per-device |
| Blood gates | 18 sample classes | Each rejected at the physically correct gate; all 6 gates exercised |
| Touch gates | 9 sample classes | Each rejected at the correct gate; all 7 gates exercised |
| Calibration loop | Capture → sweep → load → re-verify | Thresholds written, loaded, and still separate the panel |
| Touch calibration loop | Same, for the touch tier | Every touch threshold set from captured sessions; calibrated set still separates the panel |
| Enrolment invariant | Reference written by `enroll-reference` | Reproduces the G4 clamp mask; 415 nm stays excluded; the enrolled vector is the one gate 4 compares against, and a genuine capture still passes under it |
| Hostile captures | 9 malformed captures | Zeros, NaNs, negative counts, short speckle. Each rejected at a named gate, none raise |
| Drift invariance | LED aging, gain drift, ambient leak, beam envelope | Gate scores do not move: the white patch divides the first two out, the dark read subtracts the third, the spatial high-pass removes the fourth |
| Speckle physics | Ornstein-Uhlenbeck field, exposure-integrated | Reproduces frozen and liquid limits; exposure, frame interval and grain each swept against the G5/G6 thresholds |
| Drift margins | 7 disturbance axes, bisected | Tightest budget reported and ranked; a finite tolerance on an invariance axis fails the suite |
| Mechanical drawing | Regenerated from the mesh | Byte-identical, enforced in CI |
| A fresh clone | `git clone`, install, `run_tests.py` | 51 suites pass; every path and command the docs name resolves; the LFS mesh arrives as a mesh; all four generators reproduce `models/`, `diagrams/` and `viewer/` byte for byte |

### The two QR framings

`firmware/qr.py` and `firmware/ur.py`. The second is the one interoperability
turns on, so it is checked against the reference implementation's own published
vectors rather than against our output — the fountain mixture in part 13 of a
transfer is a function of a seeded PRNG, an alias table and a particular
shuffle, and a subtly wrong one produces plausible URs nothing else can read.

| Case | Method | Result |
|---|---|---|
| CRC-32, Bytewords | BCR-2020-012 published values | Byte-exact, both encode and decode; a bad checksum refused |
| Xoshiro256\*\* | Three published streams, 100 draws each: seeded from a string, from a CRC-32, and through `next_int` | Exact, including `next_int`'s inclusive upper bound |
| Alias sampler | 500 published draws | Exact, including the two-draw sampling and the reversed index fill both being observable |
| Fisher-Yates | Ten published permutations | Exact |
| Degree chooser | 200 published nonces | Exact |
| Fragment selection | 30 published parts, mixtures included | Exact |
| Nominal fragment length, partition | Published values, padding included | Exact |
| Single-part UR | Published string, 50-byte message | String-exact |
| Multipart UR | Published strings, 20 parts of a 256-byte message at a 30-byte fragment | String-exact, all twenty |
| The fountain property | Decode from the mixtures alone, out of order, with every duplicate a loop produces, and with one pure fragment permanently missing | Reconstructs in every case; the same transfer in `pNofM` cannot, however long it loops |
| Hostile frames | A UR type this device does not read, a type outside the alphabet, two transfers mixed on screen, two types mixed, a fragment replaced mid-scan with every checksum recomputed, outer and inner headers disagreeing, a `seqLen` or `messageLen` past the ceiling, a payload the wrong size for its claims, a reassembled message failing its own checksum, CBOR nested past its bound, a float, an indefinite-length string | All refused; an incomplete transfer yields nothing at all |
| Byte-for-byte equivalence | The same PSBT through `pNofM`, through UR, and through the USB link | Identical bytes reach `classify` by all three routes |
| EIP-4527 | An `eth-sign-request` round trips through the codec and through a whole UR transfer; the reply is tag 402 with the request id echoed and 65 bytes of r, s and v | Exact. Hostile requests refused: the wrong tag, a non-map, an unknown map key, a missing field, sign data past the ceiling, a path deeper than the device renders, a 19-byte address, a keypath under the wrong tag or with a non-boolean hardened flag |
| crypto-account export | Every descriptor this device exports, against BCR-2020-015's own published vector, derived from its own test seed | All four byte-exact as substrings of the published CBOR: `pkh` at m/44h/0h/0h, `sh(wpkh)` at m/49h, `wpkh` at m/84h, `tr` at m/86h. The account is tag 311 with the fingerprint and one output each; a testnet key declares coin-info and a mainnet one leaves it at the default; an exported key is always compressed and never claims to be private; both hardened spellings parse; a path that does not start at m, a non-numeric level, an index past 31 bits and an empty level are refused |
| Transfer direction | Collecting a UR type this device only emits | Refused, naming the direction. `crypto-account` and `eth-signature` are answers, so a scan that reassembled one would be reading a signer's screen, not a coordinator's |
| Rebuilding an encoded transaction | `eth.from_signing_payload` on a canonical payload, then on payloads that decode to the same fields and re-encode differently | The round trip rebuilds exactly; a leading zero on the nonce, the value or the chain id is refused, as are a legacy or EIP-2930 encoding, an empty payload, the wrong field count, a contract creation, a non-empty access list, an integer encoded as a list, and a signed transaction where an unsigned one belongs |

### The USB link variant

`firmware/link.py`. Opt-in, off on every build `BUILD.md` §1 describes, and
tested regardless: a variant nobody tests is a variant that breaks silently.
The gadget port itself needs hardware — see "Written but unverified".

| Case | Result |
|---|---|
| Framing | One newline-terminated message per line; round trips, empty payload included |
| Resynchronisation | A stream joined halfway through recovers on the next message |
| Junk on the wire | Getty banners, modem probes, a bad tag, a body that is not base64: all reported and stepped over, never interpreted |
| Delivery shape | A message arriving a byte at a time reassembles; two back to back both read |
| Bounds | A message past the line cap refused; an unterminated stream discarded rather than accumulated; silence times out; BACK leaves the waiting screen |

### Multisig, and the registry it depends on

| Case | Result |
|---|---|
| 2-of-3 p2wsh, full unlock chain | Partial signature present and verifying against the BIP-143 sighash; only our key signed for |
| 2-of-3 p2sh-p2wsh | Signs; both BIP-48 script types covered |
| Quorum on the confirmation screen | "MULTISIG 2 of 3" and "signature 1 of 2", rebuilt from the registered co-signers, never read off the host's script |
| Unregistered quorum | Refused before the gate. A device that signs a quorum it cannot describe cannot tell yours from someone else's |
| **A co-signer swapped in a change output** | Not treated as change; shown as a WARNING with the address in full. This is the attack registration exists to stop |
| A co-signer quoted at a different index | Not change |
| BIP-67 ordering flipped | Not change |
| Witness script absent, or not a bare m-of-n | Not change; a non-multisig witness script is refused at the input |
| Registering a quorum we are not in | Refused |
| Registering one that quotes a foreign xpub under our fingerprint | Refused |
| 4-of-3, or a duplicate label | Refused |

### Names — WNS, GNS and ENS

Resolution happens on the host, in `tools/ethnames.py`. The device holds no
resolver: it draws names the owner registered, over addresses the owner
checked, and the address stays on screen in full.

| Case | Result |
|---|---|
| EIP-137 namehash | Matches the node constant WNS, GNS and ENS each publish, and the `foo.eth` vector in EIP-137 |
| The token id the registries compute | Read back from the contract on every resolution and compared to ours; a disagreement refuses rather than resolving the wrong name |
| Selector derivation | Pinned to the six interface ids ENS and WNS publish — `addr(bytes32)`, `addr(bytes32,uint256)`, `text`, `contenthash`, `resolver`, `name` |
| Routing | `.wei`→WNS, `.gwei`→GNS, everything else dotted→ENS; longest suffix first, so `.gwei` is never read as `.wei` |
| `.eth` | Reserved to ENS; no registry may claim it |
| A bare label | Refused. `alice` is a name in two systems pointing at two people |
| A homograph | Refused. Names are lowercase ASCII, because a Cyrillic "a" renders as a Latin one at 40 columns |
| **A name arriving with a transaction** | Impossible, and checked against the parser on every run: no operation declares a field that could carry one |
| A name on a chain it published an override for | The default address is *not* drawn under that name there. The override is |
| A Bitcoin address a name publishes | Read from coin type 0 as a scriptPubkey, decoded through the same `script_to_address` the signer uses, checked against the BIP-173 vector |
| Reverse resolution | Forward-verified — a primary name is resolved back to the address that claimed it before the tool repeats it |
| Two of the owner's names over one address | WNS, then GNS, then ENS, then alphabetically. Deterministic, and the command that registers the second one says which is drawn |
| Repointing a registered name | Refused, like relabelling a token |
| A per-chain address on an unregistered chain | Refused at registration, where a typo is visible, rather than silently never applying |
| Live, against mainnet | `vitalik.eth`, `zswap.wei` and `alice.gwei` resolve to their published addresses; `vitalik.eth` reverse-resolves and forward-verifies. Not in CI — CI has no network |

### PSBT version 2 (BIP-370)

| Case | Result |
|---|---|
| v2 rebuilt into a transaction | Byte-identical to the v0 form of the same PSBT |
| v2 signed | Same signature as v0, returned as v2 and never silently downgraded |
| v2 under attack | Two destinations and a lying witness UTXO refused exactly as in v0 |
| Malformed v2 | Missing input count, previous txid, output index; short version or txid, all refused |
| Locktimes | A required height locktime overrides the fallback; requiring both a height and a time locktime is refused as unsatisfiable |
| An unknown PSBT version | Refused by name, not guessed at |

### The application loop

`firmware/test_app.py`. The device driven end to end with fake display, buttons
and camera. The seams between parts that are individually correct.

| Case | Result |
|---|---|
| A scanned PSBT, start to finish | Signed; emitted frames reassemble into a PSBT carrying both the signature and the attestation |
| Ordering | The transaction is displayed before the PIN is asked for, the PIN before the gate runs |
| Declining | At the confirmation, at the PIN, and at the gate. Nothing signed, nothing emitted, and the owner told so |
| A wrong PIN | Refused, gate never reached, attempts remaining shown |
| Hostile input | A PSBT with none of our keys, a truncated one, a two-destination one, a QR that is not a transaction, foreign JSON, an Ethereum request with an unknown or missing field. Every one refused as a readable screen, never a traceback |
| An incomplete scan | Reported in words instead of hung on |
| Ethereum | Signed; chain, chain id, nonce and worst-case fee all on screen; raw transaction emitted as a typed envelope |
| ERC-20 | A registered token signs; the screen names the token, shows the amount at the registered decimals, and shows BOTH the recipient and the contract in full; no calldata reaches the screen; the emitted raw transaction carries the bytes the device encoded. An unregistered token is refused before the gate, with the command that fixes it on screen. A request carrying a `data` field is refused by name |
| Either QR framing | A PSBT arriving as UR signs identically to one arriving as `pNofM`, carries the same attestation, and is answered in the framing it arrived in — checked both ways round |
| The USB variant | A PSBT arriving over the wire signs; the gate still runs; the destination is still shown in full; nothing is put on screen as a QR; the reply goes back down the wire. Silence on the wire is a readable screen, not a hang |
| Exporting the accounts | DOWN, then CONFIRM on THIS DEVICE | Emitted as `ur:crypto-account` with one descriptor per Bitcoin script type and none for `eth`; the warning about what an xpub reveals is shown before the QR; every exported key is one the recorded xpubs hold, compressed and public; BACK at the warning shows nothing; nothing was unlocked to build it |
| EIP-4527, end to end | A request from a browser wallet signs; the amount and chain are rendered from the REBUILT transaction; the reply is an `eth-signature` and recovers to this device's own address. Data types 1, 3 and 4 are each refused by name before the gate runs, as are a payload that does not re-encode to itself, a request for another derivation path, one naming another address, and an outer chain id disagreeing with the payload it carries |
| Multisig | A registered quorum signs and shows its threshold; an unregistered one is refused before the gate |
| Tier policy | A spend above the floor demands blood and says what that costs; a small one runs at touch |
| Read-only screens | The receiving address matches what the seed derives, with nothing unlocked to show it |
| Every screen, everywhere | None overflowed 40 columns or 20 rows |
| **The seam to the sensing half** | `app.gate_result` adapted against the gates' REAL outputs, not a mock: a genuine blood capture and a genuine touch capture pass, ketchup and a pumped silicone finger fail with a message naming the gate. The two tiers report measurements under different keys, blood `gate_scores`, touch `features`, and `liveness_digest` reads both, so two captures at either tier attest to different measurements |

### The secure element driver

`firmware/test_se_atecc.py`, against a fake chip. This is logic coverage, not
evidence about silicon. The fake holds slot secrets in memory, which is the
one thing the real part does not do.

| Case | Result |
|---|---|
| An unlocked chip | Refused outright, with a message saying how to fix it |
| The attempt counter | Spent before the comparison; the cost survives a power cut |
| A correct PIN | Restores the budget by moving the on-chip baseline, never by winding the counter back |
| A baseline ahead of the counter | Treated as tampering and refused |
| The wipe | Overwrites the wrapping slot; the correct PIN cannot revive the device, across a power cut |
| The KDF | Refuses without a spent attempt, and is single use |
| The attestation key | Stable, per-chip, verifies against its own pubkey, and is not the wrapping key |

### The wallet, end to end and under attack

`firmware/test_wallet.py`. The first group proves it works; the rest are the
ways hardware wallets have actually lost money, each written as a hostile
input whose pass condition is a refusal.

| Case | Result |
|---|---|
| Full unlock chain, 4 script types | p2wpkh, p2sh-p2wpkh, p2pkh, p2tr. Signature verifies against the sighash; change recognised; attestation rides in the PSBT |
| Fee inflation | A witness UTXO alone is refused for segwit v0; one that disagrees with the parent is refused; a parent with the wrong txid is refused |
| Taproot exception | A witness UTXO alone IS accepted for p2tr, because BIP-341 covers every amount |
| Change substitution | Change we cannot derive is shown as a WARNING with the address in full, never as "your wallet" |
| Path lying | A real key quoted at a path that does not derive it is not treated as change; the correctly quoted version still is |
| Sighash downgrade | NONE, SINGLE, ANYONECANPAY\|ALL, ANYONECANPAY\|NONE all refused; an explicit ALL accepted |
| Unrenderable transactions | A batched payment and an OP_RETURN output both refused |
| Nothing to sign | A PSBT holding none of our keys is refused instead of silently returned unchanged |
| Malformed encodings | Truncated, trailing bytes, bad magic, duplicate map key, pre-signed unsigned transaction, all refused |
| The seed at rest | A wrong PIN, a tampered blob and a foreign chip all fail closed, with one message for all three |
| Ethereum | Recovers to the displayed sender; chain id, nonce and worst-case fee displayed; calldata and unnamed chains refused; the chain id changes the digest |
| The gate still governs | A spend above the floor demands blood; a failed gate signs nothing; cancelling at the prompt signs nothing |

Interoperability against published vectors is the meaningful result in both
tables. A round trip against your own implementation proves nothing.
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

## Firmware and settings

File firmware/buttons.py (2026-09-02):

"""Four buttons, and the one that is different from the others.

UP, DOWN and BACK are navigation. CONFIRM is consent, and it is wired
differently on purpose: its own GPIO, its own RC debounce, sharing no bus with
anything. BUILD.md section 11 states the reason and this file enforces the
consequence — an attacker who owns the SPI bus, the display, or the I2C line
still cannot assert CONFIRM, because nothing on those buses is in its path.

WHAT THIS FILE GUARDS AGAINST beyond wiring:

  CONTACT BOUNCE.  A mechanical switch closes several times in a few
      milliseconds. Debouncing is normally a cosmetic concern; here one stray
      edge on CONFIRM is a signature the owner did not give, so it is a
      correctness concern.

  QUEUED PRESSES.  A press that arrived while the device was busy computing
      must not be delivered to the confirmation screen that appears
      afterwards. Consent has to be given to a screen the owner has actually
      seen, so the queue is drained before a confirmation is asked for, and
      `confirm()` refuses anything that arrives implausibly fast.

  A HELD BUTTON.  Tape over CONFIRM would otherwise confirm everything. A
      press only counts on the edge, and a button already down when the
      confirmation appears is not a press.
"""

from __future__ import annotations

import time
from dataclasses import dataclass, field
from typing import Callable, Protocol, runtime_checkable

# BCM numbering, from BUILD.md section 11.
PIN_UP = 5
PIN_DOWN = 13
PIN_BACK = 19
PIN_CONFIRM = 26                        # dedicated, RC-debounced, shares no bus

UP, DOWN, BACK, CONFIRM = "UP", "DOWN", "BACK", "CONFIRM"

DEBOUNCE_S = 0.030

# A confirmation that arrives faster than a person can read the screen is not
# a confirmation. This is not an anti-robot measure — nothing here can tell a
# fast human from a script — it is a guard against a press that was already in
# flight when the screen changed under it.
MIN_READ_S = 0.400


class ButtonError(Exception):
    """The button hardware is missing or misbehaving."""


@runtime_checkable
class Buttons(Protocol):
    def poll(self) -> str | None:
        """The next press, or None. Never blocks."""

    def peek(self) -> str | None:
        """The next press WITHOUT consuming it. Never blocks.

        Separate from `poll` because a screen that is watching for one
        particular button must not swallow the others on its way past. The
        scan screen wants BACK and nothing else; if it polled, a CONFIRM the
        owner pressed a moment early would vanish rather than queue.
        """

    def wait(self, timeout: float | None = None) -> str | None:
        """Block for the next press."""

    def drain(self) -> None:
        """Discard anything queued. Called before asking for consent."""


@dataclass
class FakeButtons:
    """Scripted presses, for the tests and the console runner."""

    script: list[str] = field(default_factory=list)
    clock: Callable[[], float] = time.monotonic
    delay: float = MIN_READ_S + 0.1     # by default, presses look considered

    def __post_init__(self):
        self._t = 0.0

    def poll(self) -> str | None:
        if not self.script:
            return None
        self._t += self.delay
        return self.script.pop(0)

    def peek(self) -> str | None:
        return self.script[0] if self.script else None

    def wait(self, timeout: float | None = None) -> str | None:
        return self.poll()

    def drain(self) -> None:
        pass

    def now(self) -> float:
        return self._t


class GPIOButtons:
    """The real buttons. Untested until they are on a bench."""

    def __init__(self):
        try:
            from gpiozero import Button
        except ImportError:                                     # pragma: no cover
            raise ButtonError(
                "gpiozero is not installed. On Raspberry Pi OS:\n"
                "    apt install python3-gpiozero") from None

        self._queue: list[tuple[str, float]] = []
        self._buttons = {}
        for name, pin in ((UP, PIN_UP), (DOWN, PIN_DOWN),
                          (BACK, PIN_BACK), (CONFIRM, PIN_CONFIRM)):
            b = Button(pin, pull_up=True, bounce_time=DEBOUNCE_S)
            # `when_pressed` fires on the falling edge only, so a button that
            # is already held when we start listening produces nothing. That
            # is the behaviour we want for CONFIRM.
            b.when_pressed = self._make_handler(name)
            self._buttons[name] = b

    def _make_handler(self, name: str):
        def handler():
            self._queue.append((name, time.monotonic()))
        return handler

    def poll(self) -> str | None:
        return self._queue.pop(0)[0] if self._queue else None

    def peek(self) -> str | None:
        return self._queue[0][0] if self._queue else None

    def wait(self, timeout: float | None = None) -> str | None:
        deadline = None if timeout is None else time.monotonic() + timeout
        while True:
            if self._queue:
                return self._queue.pop(0)[0]
            if deadline is not None and time.monotonic() > deadline:
                return None
            time.sleep(0.01)

    def drain(self) -> None:
        self._queue.clear()

    def held(self, name: str) -> bool:
        return bool(self._buttons[name].is_pressed)


def confirm(buttons: Buttons, present: Callable[[], None],
            clock: Callable[[], float] = time.monotonic,
            min_read_s: float = MIN_READ_S) -> bool:
    """Show a screen and wait for CONFIRM or BACK. Everything else is ignored.

    `present` is called AFTER the queue is drained, so the screen the owner
    reacts to is the screen they were shown. Returning False is a decline, and
    a decline is the default for anything ambiguous — a timeout, a BACK, or a
    press too fast to have followed a reading.
    """
    buttons.drain()
    present()
    shown_at = clock()
    deadline = shown_at + 120.0
    while True:
        # Measured from when the SCREEN went up, not from the last press. A
        # per-press timeout meant every ignored edge started the 120 s again,
        # so a bouncing switch or a stream of stray edges held a confirmation
        # screen up indefinitely -- and the whole point of the timeout is that
        # an unattended screen decides for itself.
        remaining = deadline - clock()
        if remaining <= 0:
            return False
        press = buttons.wait(timeout=remaining)
        if press is None:
            return False                    # walked away; that is a decline
        if press == BACK:
            return False
        if press == CONFIRM:
            if clock() - shown_at < min_read_s:
                # In flight before the screen existed. Ignore it and keep
                # waiting rather than counting it or aborting: aborting would
                # let a stray edge cancel a legitimate signing.
                continue
            return True
        # UP and DOWN do nothing here. There is nothing to scroll: the screen
        # is guaranteed to fit, so movement keys would only add ways to be
        # somewhere other than where you think you are.


def pin_entry(buttons: Buttons, display, length: int = 8,
              prompt: str = "ENTER PIN") -> str | None:
    """Digit picker on four buttons. Returns None if the owner backs out.

    UP and DOWN change the current digit, CONFIRM accepts it and moves on,
    BACK removes the last one — and BACK on an empty PIN abandons the entry
    entirely, which is the only way out that does not spend an attempt.

    The digits are shown as they are chosen. Masking them would be theatre on
    a device you hold in your own hand, and it would stop the owner noticing
    that a button is bouncing.
    """
    digits: list[int] = []
    current = 0
    while True:
        shown = "".join(str(d) for d in digits)
        display.show([
            prompt, "",
            f"  {shown}{current}{'_' * (length - len(digits) - 1)}",
            "",
            "  UP/DOWN  change the digit",
            "  CONFIRM  accept it",
            "  BACK     delete, or cancel",
            "",
            f"  {len(digits)} of {length}",
        ])
        press = buttons.wait(timeout=300.0)
        if press is None:
            return None
        if press == UP:
            current = (current + 1) % 10
        elif press == DOWN:
            current = (current - 1) % 10
        elif press == BACK:
            if not digits:
                return None
            digits.pop()
            current = 0
        elif press == CONFIRM:
            digits.append(current)
            current = 0
            if len(digits) == length:
                return "".join(str(d) for d in digits)


def open_buttons(console: bool = False, script: list[str] | None = None) -> Buttons:
    if console:
        return FakeButtons(script or [])
    try:
        return GPIOButtons()
    except ButtonError as e:
        print(f"No buttons: {e}\nFalling back to a scripted stub.")
        return FakeButtons(script or [])


# --------------------------------------------------------------------------


def _selftest() -> int:
    print("Buttons — debounce, consent, PIN entry\n")
    checks = []
    from display import ConsoleDisplay

    checks.append(("FakeButtons satisfies the protocol",
                   isinstance(FakeButtons(), Buttons)))
    checks.append(("GPIOButtons satisfies the protocol",
                   all(hasattr(GPIOButtons, m) for m in ("poll", "wait", "drain"))))
    checks.append(("CONFIRM is on its own pin",
                   PIN_CONFIRM not in (PIN_UP, PIN_DOWN, PIN_BACK)))
    checks.append(("CONFIRM is GPIO26, as BUILD.md wires it", PIN_CONFIRM == 26))

    # ---- consent ----
    shown = []

    def present():
        shown.append(True)

    b = FakeButtons([CONFIRM])
    checks.append(("CONFIRM confirms", confirm(b, present, clock=b.now) is True))
    checks.append(("the screen was shown before the press", len(shown) == 1))

    b = FakeButtons([BACK])
    checks.append(("BACK declines", confirm(b, present, clock=b.now) is False))
    checks.append(("walking away declines",
                   confirm(FakeButtons([]), present, clock=lambda: 0.0) is False))

    # Navigation keys must not confirm.
    b = FakeButtons([UP, DOWN, UP, CONFIRM])
    checks.append(("UP and DOWN do not confirm", confirm(b, present, clock=b.now) is True))
    b = FakeButtons([UP, DOWN, BACK])
    checks.append(("...and BACK after them still declines",
                   confirm(b, present, clock=b.now) is False))

    # A press already in flight when the screen appeared must not count.
    fast = FakeButtons([CONFIRM, CONFIRM], delay=0.001)
    got = confirm(fast, present, clock=fast.now)
    checks.append(("a press faster than a read is ignored once", got is False))

    # The same press, given time to have been read, is accepted. Both halves
    # matter: a guard that rejected everything would pass the test above and
    # make the device unusable.
    considered = FakeButtons([CONFIRM], delay=MIN_READ_S + 0.05)
    checks.append(("but a considered press is accepted",
                   confirm(considered, present, clock=considered.now) is True))

    # And a stray fast edge must not cancel a signing the owner then confirms.
    recovered = FakeButtons([CONFIRM, CONFIRM])
    recovered.delay = 0.001
    seq = iter([0.0, 0.001, 5.0])
    checks.append(("a stray edge does not cancel a later real press",
                   confirm(recovered, present, clock=lambda: next(seq)) is True))

    # The queue must be drained before consent is asked for.
    drained = []

    class Recording(FakeButtons):
        def drain(self):
            drained.append(len(self.script))
            self.script.clear()

    r = Recording([CONFIRM, CONFIRM, CONFIRM])
    checks.append(("queued presses are discarded, then it waits",
                   confirm(r, present, clock=r.now) is False and drained == [3]))

    # ---- PIN entry ----
    d = ConsoleDisplay(out=open("/dev/null", "w"))
    # 1, then 2, then six zeros. Eight digits by default -- see app.PIN_LENGTH.
    script = ([UP, CONFIRM] + [UP, UP, CONFIRM] + [CONFIRM] * 6)
    checks.append(("PIN entry assembles the digits",
                   pin_entry(FakeButtons(script), d) == "12000000"))
    checks.append(("BACK on an empty PIN cancels",
                   pin_entry(FakeButtons([BACK]), d) is None))
    checks.append(("BACK deletes a digit",
                   pin_entry(FakeButtons([UP, CONFIRM, BACK, CONFIRM] + [CONFIRM] * 7),
                             d) == "00000000"))
    checks.append(("DOWN wraps to nine",
                   pin_entry(FakeButtons([DOWN, CONFIRM] + [CONFIRM] * 7), d)
                   == "90000000"))
    checks.append(("a timeout cancels rather than submitting",
                   pin_entry(FakeButtons([UP, CONFIRM]), d) is None))
    checks.append(("PIN length is honoured",
                   len(pin_entry(FakeButtons([CONFIRM] * 6), d, length=6)) == 6))
    # The default has to match what the device actually asks for, or a build
    # ships a screen that collects six digits for a PIN of eight.
    import app
    checks.append(("...and the default is the device's PIN length",
                   len(pin_entry(FakeButtons([CONFIRM] * app.PIN_LENGTH), d))
                   == app.PIN_LENGTH))

    ok = True
    for label, good in checks:
        ok &= good
        print(f"  {label:<52}{'PASS' if good else 'FAIL'}")
    print("\n" + ("PASS" if ok else "FAIL"))
    print("\nThe switches themselves are unverified until they are on a bench.")
    return 0 if ok else 1


if __name__ == "__main__":
    raise SystemExit(_selftest())

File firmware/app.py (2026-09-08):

"""The device, as a person uses it.

Everything below this file is a component. This is the order they run in when
somebody picks the thing up, and — like signer.py one layer down — the order
is the security property, not an implementation detail.

    scan -> parse -> summarise -> DISPLAY -> confirm -> PIN -> gate -> sign -> emit

Four rules govern it, and each is here because the obvious alternative fails:

  NOTHING IS UNLOCKED TO READ A TRANSACTION.  The summary the owner approves is
      computed from the watch-only account xpubs recorded at provisioning. The
      seed stays encrypted until after the gate. So a hostile PSBT gets as far
      as the screen and no further, and it never meets a private key at all.

  THE OWNER SEES IT BEFORE THEY PAY FOR IT.  Rendering happens before the PIN
      and long before the lancet. An operation that cannot be displayed is
      refused while it is still free to refuse it — nobody should bleed for a
      transaction the device then declines to show them.

  ONE OPERATION PER SCAN.  The device returns to idle after every signature.
      There is no batch mode and no "sign the rest of these": every signature
      costs one physical act, which is the entire argument of the product.

  A REFUSAL IS A SCREEN, NOT A TRACEBACK.  Every failure path ends at
      `_fail()`, which shows the owner what was refused and why in words. A
      device that drops to a Python traceback has told an owner nothing and
      has taught them to power-cycle and retry, which is how people learn to
      click through warnings.

The whole loop is written against protocols — Display, Buttons, Camera,
SecureElement — so `run_once()` can be driven end to end on a laptop with
fakes. `test_app.py` does exactly that.
"""

from __future__ import annotations

import json
import sys
import time
from dataclasses import dataclass
from typing import Callable

import addresses
import bip32
import duress
import eip712
import buttons as btn
import camera as cam
import eth
import link as lnk
import names
import ops
import psbt as psbtmod
import qr
import ur
import seedstore
import signer
import wallet
from display import Display
from policy import Policy, Tier
from se import PinLockout, SecureElement
from wallet import Provisioning, WalletError

# Eight digits are the input format. PIN-v2 charges a chip-counter use for
# each candidate derivation; the ten-attempt wipe remains firmware policy.
# See se_atecc.py and VALIDATION.md for the hardware validation requirements.
PIN_LENGTH = 8


class Abort(Exception):
    """The owner backed out. Not an error, and never reported as one."""


@dataclass
class Device:
    """Everything the loop needs, injected so it can be driven by fakes."""

    prov: Provisioning
    se: SecureElement
    display: Display
    buttons: btn.Buttons
    camera: cam.Camera
    run_gate: Callable[[Tier], tuple[bool, dict]]
    policy: Policy
    fw_hash: bytes
    cal_hash: bytes
    network: str = "mainnet"
    # None on a device that never enrolled its chamber. See
    # signer.unwrap_context: leaving it None derives exactly what such a
    # device has always derived, and a device that DID enrol cannot be
    # downgraded by dropping it, because its seed will not open.
    read_chamber: "Callable[[], bytes] | None" = None
    # A USB data path, on builds that have one. None on every build BUILD.md
    # section 1 describes, and that is the default. When it IS set it REPLACES
    # the camera rather than joining it: the Pi Zero has one data-capable USB
    # port, the QR webcam occupies it, and a dwc2 controller cannot be host and
    # peripheral at once. Read link.py before enabling this -- it gives up two
    # properties the camera build has, and neither is recoverable in firmware.
    link: "lnk.Link | None" = None
    # The real one. It used to default to a no-op, which is a test
    # convenience: load_device never overrode it, so on the device the SIGNED
    # screen was painted and replaced in the same instant and cam.emit ran its
    # animated output QR with no frame time at all -- flashing the signed
    # transaction past the receiving camera faster than it could latch a
    # frame, on the airgap's only way out.
    sleep: Callable[[float], None] = time.sleep
    # Injected so the tests can drive the confirmation guard, which measures
    # how long a screen has been up before it will accept consent. Faking the
    # clock is how that guard gets tested; weakening it would be how it stops
    # being one.
    clock: Callable[[], float] = time.monotonic

    # ---- screens ----

    def _screen(self, title: str, body: list[str], footer: str = "") -> None:
        lines = [title, ""] + body
        if footer:
            lines += ["", footer]
        self.display.show(lines)

    def _fail(self, reason: str, detail: str = "") -> None:
        """Show a refusal in words, and wait for the owner to acknowledge it.

        Wrapped rather than truncated: a refusal the owner cannot read is a
        refusal they will work around.
        """
        body = ops.wrap_full(detail, ops.DISPLAY_COLS, indent="  ") if detail else []
        # Leave room for the title, the blank, and the footer.
        room = ops.DISPLAY_ROWS - 5
        if len(body) > room:
            body = body[:room - 1] + ["  ..."]
        self._screen(reason.upper()[:ops.DISPLAY_COLS], body, "CONFIRM to continue")
        self.buttons.drain()
        self.buttons.wait(timeout=120.0)

    def _note(self, title: str, *body: str) -> None:
        self._screen(title, [f"  {b}" for b in body])

    # ---- the loop ----

    def idle(self) -> None:
        fp = self.prov.master_fingerprint.hex()
        quorums = len(self.prov.multisig)
        body = [
            f"  wallet   {fp}",
            f"  network  {self.network}",
            # The firmware hash rather than a version string: it is what
            # co-signers register and what the attestation commits to, so it
            # is the identifier worth being able to read off the screen.
            f"  firmware {self.fw_hash[:4].hex()}",
            f"  quorums  {quorums} registered" if quorums else "  quorums  none",
        ]
        if hasattr(self.policy, "describe"):
            body.append(f"  tier     {self.policy.describe()}")
        self._screen("CELL", body + [
            "",
            "  CONFIRM  scan a transaction",
            "  UP       show a receiving address",
            "  DOWN     show this device's keys",
        ])
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

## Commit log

2026-08-21 Rev 0.6: fix sensing defects, close the calibration loop, prepare for release
    Fixes ten defects found in review of Rev 0.5, several of which would have
    failed on a first real build:
    - read_ppg used the chemistry integration time (281 ms/channel) against a
    20 ms budget, so touch mode ran ~6x slow and was analysed at the nominal
    rate; a healthy 68 bpm read as ~11 and failed T3 for every genuine user.
    Now switches integration time, measures the achieved rate, and adds gate
    T0 to refuse an unanalysable capture as a hardware fault.
    - Gates 1-4 were read early but never evaluated early, so an obvious spoof
    still took ten minutes. acquire() now aborts at the early read.
    - Gate 1 was a fl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
    [BOM.csv, instrument.obj]
2026-08-21 Fix CI on LFS checkout, add model preview to README
    The drawings job checked out models/instrument.obj as a 130-byte Git LFS
    pointer, so the parser found no vertices and numpy failed on an empty array
    rather than on a real drift. Set lfs: true on actions/checkout.
    gen_mechanical.py now detects a pointer file and says so, instead of
    surfacing it later as "zero-size array to reduction operation minimum".
    Also errors clearly on a missing file or a vertex-less OBJ.
    README embeds the enclosure render, the explainer and the build sheet, and
    documents how to run the parametric viewer locally.
    [gen_mechanical.py]
2026-08-21 Re-export enclosure from parametric source; product-voice docs pass
    The committed instrument.obj was a stale export. viewer/model.js — the
    parametric source — had already moved the dish to the slot centreline and
    forward in Z; the exported mesh predated both changes, which is where the
    apparent slot/read-spot misalignment came from. There was no design fault.
    Adds tools/export_model.py, which drives headless Chrome against the real
    viewer so the mesh comes from the same three.js path a person gets when they
    open the page, rather than a reimplementation that could drift. The chain is
    now reproducible end to end:
    viewer/model.js -> models/instrument.obj -> diagrams/mechanical.svg
    Re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
    [instrument.obj]
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2026-08-22 Render quorum context; stop the render tools leaking temp dirs
    ops.py: BitcoinSpend now carries quorum_needed, quorum_size and
    signatures_present, so the firmware renders the multisig context the
    industrial-design mockup already shows on screen. Nonsensical quorums are
    refused outright — 4-of-3, zero-of-n, more signatures present than signers.
    The distinction is in the field comments, because it matters: the threshold
    comes from the witness script and is trustworthy, while the count of
    signatures already present comes from a PSBT the HOST assembled. So the
    count is progress, never a security control. What actually establishes that
    a quorum signed at blood tier is attest.verify_quorum(), r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
    [export_model.py, ops.py, test_signer.py]
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2026-08-22 Turntable render quality, printable enclosure shells, standalone viewer
    Turntable
    ---------
    240 frames at 20 fps, 12 s per revolution, 720 px supersampled from 1440 px.
    Every GIF frame carries an exact 5 cs delay, so the loop no longer stutters:
    GIF timing quantises to centiseconds, and the previous 15 -> 12 fps resample
    dropped one frame in five on an uneven cadence. The renderer now warns when a
    requested rate cannot divide 100 or is not a whole-number decimation.
    Quality came from supersampling in GL and downsampling in the browser by
    repeated halving, rather than exporting full-size frames and letting ffmpeg
    shrink them — a single 3:1 shrink point-samples and puts back the aliasing
    th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
    [aperture_tube.stl, cartridge.stl, cartridge_null.stl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]
2026-08-22 Fix mechanical drawing clipping and crossing leaders; correct the pad
    The last note ran off the bottom of the page. Notes were laid out at a fixed
    44 px pitch that assumed every body wrapped to two lines, so a longer one
    overran the note below it and then the canvas. Notes now flow at their real
    height and the canvas height is computed from the content, so no text length
    can clip again. Wrapping also uses the full page width instead of half of it.
    Leader lines in the TOP view crossed each other. Label rows are now assigned
    in order of how high each feature sits in the view, so they fan out. Ordering
    by hand was what put the rear-bay leader — anchored at the very back — on the
    bottom row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
    [gen_mechanical.py]
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2026-08-22 Mechanical drawing: show the cartridge fit, name the notes for what they are
    "THREE THINGS THE MODEL DOES NOT SAY" told the reader nothing about why they
    should read it. All three notes are the same kind of thing: a choice that
    looks arbitrary or decorative and will get "improved" by someone who does not
    know the consequence. Heading is now "THREE CHOICES THAT LOOK COSMETIC AND
    ARE NOT".
    Adds a CARTRIDGE FIT panel, in the space the sheet was wasting. The drawing
    otherwise describes only the outside of the device, but the fit that actually
    stops a build working spans two frames: the slot is on the front face and the
    well has to land under the ring, 31.6 mm inside. That relationship was wrong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
    [gen_mechanical.py]
2026-08-22 Fix enroll-reference emitting a normalised vector that disables the G4 clamp mask
    Also: provenance() no longer crashes when calibration accepted a spoof;
    not_separating was dead code, replaced with measured margins; g6_rho now
    uses the same minimum gate6 enforces; and the anticoagulation claim is
    scoped to exclude recalcified citrate, which G6 does not catch.
    [blood_gate.py, calibrate.py, run_tests.py]
2026-08-22 Attest the calibration in force, not just the firmware
    The firmware hash pins the code and says nothing about the thresholds it
    compares against. Adds cal_hash to the attestation record, computed over
    the threshold files actually loaded, registerable by co-signers exactly
    like a firmware hash.
    Also adds a robustness suite: the enrolment invariant that today's
    enroll-reference bug violated, and nine malformed captures that must
    reject at a named gate rather than raise.
    [attest.py, blood_gate.py, run_tests.py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]
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2026-08-22 Give the touch tier the calibration path it already assumed
    TouchThresholds.load() read a file nothing wrote, so the everyday tier
    could only ever run on shipped defaults. Adds touch-capture/touch-roc
    over the existing panel and features, plus a CI round trip.
    Peak spacing now uses a fixed physiological ceiling instead of bpm_max:
    a number that is both an accept threshold and an analysis parameter is
    fitted under one detector and judged under another, which put FRR at
    100% the first time the sweep ran.
    [addresses.py, bip32.py, bip39.py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]
2026-08-22 Two kits in the BOM, real costs, and CI for the printed parts
    The BOM now carries a Kit column, so a row says what to order rather
    than implying a schedule: Reader 60.10, Reader consumable 31.00, Wallet
    30.40. The consumables were unphased and every one of them is needed to
    run the reader, so a 60 dollar budget came up 31 short.
    Also fixes the touch capture path to match the TouchSensor ABC, and adds
    a CI job regenerating models/print — the STLs are what people actually
    print, and nothing checked them against their generator.
    [BOM.csv]
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2026-08-22 Give the white reference somewhere to actually be read
    The cartridge had no white patch and no way to read one: PATCH was
    declared in the generator but used in no mesh, the stop rib fixed a
    single insertion depth with the well on the read spot, and
    read_white_reference was byte-identical to read_channels. Every gate
    normalises against that patch, so on hardware the reference would have
    been the sample measured against itself - absorbance to zero, genuine
    blood rejected at G1 as 'far too bright'.
    The cartridge is now 51 mm with the well 10.5 mm back, leaving room for
    a 4 mm patch ahead of it, and a 0.35 mm detent gives a first stop at
    34.6 mm where the patch sits under the aperture. White an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
    [cartridge.stl, cartridge_null.stl, cartridge_reference.stl]
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2026-08-22 Measure what the normalisation cancels, and what it only budgets
    The spoof panel says the gate separates blood from ketchup. It says
    nothing about how far the device can drift before it stops working,
    which is the question that decides whether a build survives a real
    workshop.
    robustness.py separates two claims. Invariance: LED aging, gain drift,
    ambient leak and the beam envelope are supposed to be divided or
    subtracted out entirely, so a finite tolerance there is a bug - verified
    by disabling the white-patch normalisation, which turns two of them from
    cancelled into failures. Margin: everything else gets bisected for the
    largest disturbance the panel still survives.
    The result worth acti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
    [hardware.py, robustness.py, run_tests.py]
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2026-08-22 Check hardware driver calls against the vendor libraries
    test_drivers.py compares what display.py, buttons.py, camera.py and se_atecc.py
    call against what adafruit_rgb_display, gpiozero, OpenCV and cryptoauthlib
    actually expose: argument lists, constants, and return shapes. It skips when a
    library is absent, which is the normal case in CI.
    This covers the half of driver correctness that does not need the parts — a
    call with the wrong arity or a constant from the wrong namespace imports
    cleanly and fails on first contact with hardware. Timing, optics and switch
    bounce still need a bench.
    se_atecc.py moves the PIN check to an HMAC verifier written at provisioning,
    and the zone constants ar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
    [test_drivers.py]
2026-08-22 Speckle simulator: exposure, frame rate and grain, with the physics in it
    The linear-blend model has no camera in it, so it cannot say whether the
    optical path can resolve clotting at all. This one is an
    Ornstein-Uhlenbeck field integrated over the exposure and sampled on the
    sensor grid, which makes three design numbers measurable:
    the 2 ms exposure has about 2.5x margin - liquid blood reads liquid at
    2 ms and fails G5 by 5 ms, and it fails toward a false reject only
    because G5 runs before G6;
    at 30 fps the gates read liquid up to tau_c 31 ms and arrested from
    269 ms, so clotting must raise tau_c about ninefold;
    grain below half a pixel puts several speckles inside one pixel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
    [run_tests.py, speckle_sim.py]
2026-08-22 Verify segwit and taproot against implementations that are not ours
    The previous version of this suite could only run legacy scripts, because
    python-bitcoinlib predates segwit. That left the two script types this device
    will actually be used with resting on published vectors and on agreement with
    embit - both worth having, neither the same as being satisfied by code whose
    job is to say no.
    python-bitcointx has witness support. p2wpkh, p2sh-p2wpkh and p2wsh 2-of-3 now
    execute and succeed under the flags a node applies, including LOW_S, NULLFAIL
    and WITNESS_PUBKEYTYPE. The negative cases are the ones worth naming: a
    signature made over the wrong input amount is rejected, which is the
    fee-infl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
    [test_consensus.py]
2026-08-22 secp256k1: precomputed window table for the generator
    run_tests.py stopped completing because test_wallet.py and test_app.py each
    ran for minutes. All of it was in pure-Python EC, reached through
    bip32.derive -> child -> pubkey_point.
    Every scalar multiply in the module except three is against G: public keys,
    BIP-32 child tweaks, nonce points, both halves of ECDSA verification. A fixed
    base can be precomputed, so point_mul_g accumulates 4-bit windows out of a
    table and has no doublings left at all — 63 additions where the general path
    does 256 doublings and 128 additions.
    Not memoisation. Caching scalar-multiply results would key a cache on secret
    scalars, and the table here depends on n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
    [secp256k1.py]
2026-08-22 Hold the fast scalar multiplies to the definition they replaced
    secp256k1 now has three implementations of one operation: the affine group
    law in point_add, the Jacobian accumulation in point_mul, and the fixed-base
    window table in point_mul_g. Two of them are optimisations, and almost every
    multiply in the module goes through one or the other -- public keys, BIP-32
    child tweaks, nonce points, both halves of ECDSA verification.
    A wrong answer there is a wrong signature or a leaked key, not a failed
    assertion, so neither fast path is allowed to be the only implementation of
    what it computes. test_curve.py checks both against the affine definition
    over 18 deterministic scalars, then against f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
    [run_tests.py, test_curve.py]
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2026-08-22 Correct the performance claim in 23ec568
    23ec568 landed two changes and its message described one. The Jacobian
    accumulation in point_mul was already in the tree uncommitted, from the
    session working on the curve code, and my commit picked it up while staging
    secp256k1.py. The 135 s -> 6.6 s figure was both changes together.
    Measured separately, per scalar multiply:
    affine jacobian table
    k*G 87.9 ms 3.0 ms 0.8 ms
    k*Q 88.2 ms 2.8 ms n/a
    So the Jacobian work is 29x and covers every multiply, including the three
    against arbitrary points a fixed-base table cannot touch: ecdsa_verify,
    ecdsa_recover, schnorr_verify. The tabl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
    [secp256k1.py]
2026-08-22 Hand back the proprietary field as parts, not a pre-built key
    SignResult.psbt_proprietary_field returned b"CELL" + version and called it a
    BIP-174 key. It is not one. A proprietary key is
    0xFC <compact len(identifier)> <identifier> <compact subtype> <keydata>
    so the identifier is length-prefixed and cannot be concatenated with the
    subtype. The encoding fix landed in 0fe3330; this removes the thing that
    produced the bad input, rather than leaving callers to take it apart again.
    wallet.py was splicing key[:-1], key[-1] to undo the concatenation.
    Now returns (identifier, subtype, value) and psbt.py builds the key, so the
    encoding lives in one place and a caller cannot assemble it wrongly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
    [signer.py, test_signer.py, wallet.py]
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2026-08-22 Stop blanket staging, and check CONTRIBUTING against the BOM
    Three sessions work in this tree at once, and three times in one day a
    `git add -A` committed whatever another session had half-edited:
    d39e189 swept in a session's in-progress printing changes
    046be19 committed speckle_sim.py mid-edit, shipping two real bugs
    23ec568 picked up another session's point_mul rewrite, and described
    only half of what it contained
    Nothing was lost, but 046be19 shows the failure mode has teeth: the bugs
    were found later, in a commit whose message did not mention the file.
    CLAUDE.md states the rule and gives the reasons, so a session that reads
    it complies. The PreToolUse hook in .cla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
    [run_tests.py]
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2026-08-22 Make the blanket-staging hook fail closed
    The guard read the command with jq. If jq is absent the extraction errors,
    cmd comes back empty, no pattern matches, and every blanket stage sails
    through with nothing to indicate the hook did not run. A guard that silently
    stops guarding is worse than no guard, because CLAUDE.md tells people it is
    there.
    Now uses python3, which this repo already requires everywhere and jq is not,
    and substitutes a sentinel the patterns match when the input cannot be read,
    so an unreadable hook payload denies rather than allows.
    The sentinel deliberately carries no NUL byte. The obvious spelling for one
    is $'\x00UNREADABLE', and bash truncates a variable at the fir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
    [BOM.csv]
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2026-08-22 Prototype LMS attestation signatures (RFC 8554)
    The attestation record is CELL's own format, not Bitcoin's, so it can move to
    a post-quantum signature without waiting for a chain to. That matters more
    here than for the spend key: the attestation public key is published the day
    it is registered, where a spend key is only exposed once you spend.
    Hash-based signatures are the conservative post-quantum choice, resting on the
    hash function and nothing else. Two things normally rule them out, and this
    device answers both by accident of its design.
    They are stateful, and reusing a leaf leaks the one-time key. The ATECC608B's
    monotonic counter already increments before every attestation and surviv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
    [lms.py, run_tests.py, test_lms.py]
2026-08-22 Docs: tighten the README lead and the prose throughout
    The README opens with what the device is, what it signs, what it costs and the
    licence. Consumable economics sit with the build costs in "Building one".
    Prose and docstrings across the docs and firmware state their reasons
    directly.
    [addresses.py, eth.py, hardware.py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]
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2026-08-22 Bench checks for the three hardware questions
    tools/bench.py settles what only the built device can answer, a minute each.
    atecc tests the PIN counter by behaviour: whether the wrapping key can be
    derived without spending an attempt, whether one PIN authorises exactly one
    derive, and whether the budget wipes. It asks the chip to misbehave rather
    than decoding its config zone, since that layout is hard-coded, being wrong
    about it is silent, and the zone locks permanently. It wipes the chip, so it
    runs before provisioning.
    buttons measures how long each switch rings against the 30 ms the firmware
    debounces at. display draws a frame at all four extremes; ST7789Display takes
    x/y offsets, which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
    [bench.py, display.py]
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2026-08-22 Make the build sheet legible, and give the demo page a link preview
    BUILD SHEET. The optical head panel had four labels sitting on top of each
    other: "0 degree observe" ran through the right-hand 45 degree label, the
    aperture note was pressed against the sensor body and the camera's axis, and
    "LED #2 white" floated away from the LED it named. The panel is dense by
    nature, so the fix was to find the genuinely empty band rather than nudge
    things a few pixels and hope. The aperture note now sits under LED #1, which
    is further from what it describes than ideal but is the only clear space
    inside the frame, and readable beats adjacent.
    Also corrects the cartridge to 45 x 14 x 2.4. The sheet still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
    [build_single_file_viewer.py]
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2026-08-22 Cardiac identity: build it, measure it, and record that it does not work
    The touch tier already captures a PPG waveform, so identifying a person from
    its shape would cost nothing in parts. That is the appeal. This builds the
    mechanism and the measurement that decides whether it is usable, because the
    number that matters is not whether it separates people in one sitting -- it is
    whether it still does when the pulse has changed.
    It does not. Equal error rate against synthetic people whose morphology
    differs by amounts this code chose, enrolling at 68 bpm:
    matched rate 14.2% +/- 12 bpm 27.5%
    +/- 4 bpm 13.3% +/- 27 bpm 33.3%
    Chance is 50% and a deployable biometri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
    [cardiac_id.py, run_tests.py, test_cardiac_id.py]
2026-08-22 Register EVM chains instead of shipping a list of them
    The chain table asserted six networks and got one of them wrong: Polygon
    was in it, and format_eth hardcoded " ETH", so a Polygon transfer rendered
    as "1.5 ETH". That is a screen the owner cannot correctly evaluate, on a
    device whose rule is that it does not sign what it cannot render.
    So the table drops to the two chains nobody needs to be told — Ethereum
    and Sepolia — and everything else is registered by the owner at
    provisioning, with the name and native-token ticker it displays under.
    The signature commits to the chain id, but nobody reads a chain id. The
    name and the ticker are what say which network and which denomination is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
    [eth.py, ops.py, test_app.py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]
2026-08-22 Duress PIN: a second PIN that opens a different wallet
    BUILD.md section 16 concedes one attack outright -- someone who lances you and
    uses the sample within the minute passes every gate -- and notes that sensing
    cannot fix it. This is the mechanism that can. Under coercion you give up a
    PIN that works: the device unlocks, signs, and behaves identically. It just
    opens a different wallet.
    It needs no new cryptography. The wrapping key already comes from
    kdf(unwrap_context(pin)), so a second PIN derives a second key and opens a
    second blob. The duress path is not a branch in the unlock chain; it is the
    same code reaching a different secret.
    Making it work was easy. Making it credible was the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
    [duress.py, run_tests.py, se.py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]
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2026-08-22 Count the test suites in one place, and check the docs against it
    The suite total appeared in four documents and every one of them was stale at
    the same time: README said 33, VALIDATION said thirty, BUILD said 32,
    CONTRIBUTING said five, and the runner ran 35. Nothing caught it because the
    number lived only in run_tests.py — the file a reader is least likely to open
    and most likely to believe.
    It is now derived from the suite lists rather than written down, and the
    docs-match-the-code suite checks all four documents against it. Adding a suite
    can no longer leave four files quietly claiming a number nobody runs.
    Also adds a build milestone for running the suite on the Pi itself rather tha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
    [run_tests.py]
2026-08-23 Check the PIN through the chip, so the documented config stops bricking builds
    BUILD.md section 12 tells builders to put a ReqAuth binding on slot 0 and
    calls it the most important line of configuration in the build. The driver
    never called CheckMac. Apply that binding as documented and slot 0 refuses to
    derive, so the device cannot open its own seed: following the build sheet
    produced a brick. Nobody had hit it because nobody has built one.
    The PIN is now checked through the chip's own CheckMac against a PIN-derived
    auth slot, which is what the binding was always describing. Slot map goes from
    five to seven.
    Duress on real hardware rides along and is not the point. RealSecureElement
    could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
    [app.py, atecc_config.py, bench.py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]
2026-08-23 Check the ATECC transcriptions against Microchip's own, and fix a stale assertion
    162c323 landed the CheckMac PIN rewrite and the config-zone tool, both resting
    on one person's reading of a datasheet: an 88-byte digest and a 128-byte field
    map. cryptoauthlib ships Microchip's version of both, so they no longer have to
    be taken on trust.
    The config zone is compared against cryptoauthlib.device.Atecc608Config -- their
    ctypes definition of the same 128 bytes, with the SlotConfig and KeyConfig
    bitfields spelled out. All twelve offsets agree, and every slot policy we encode
    decodes back through THEIR struct to what we meant: ReqAuth=1 AuthKey=2
    LimitedUse=1 on slot 0, WriteConfig=0x4 on both bas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
    [test_drivers.py]
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
